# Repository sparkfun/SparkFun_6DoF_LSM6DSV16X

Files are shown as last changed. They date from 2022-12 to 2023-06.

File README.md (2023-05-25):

# SparkFun 6DoF - LSM6DSV16X (Qwiic)
========================================

<table class="table table-hover table-striped table-bordered">
    <tr>
        <th class="text-center"> 
        </th>
        <th class="text-center">
        </th>
    </tr>
    <tr align="center">
        <td></td>
        <td></td>
    </tr>
    <tr align="center">
        <td><a href="https://www.sparkfun.com/products/21325">SparkFun 6DoF - LSM6DSV16X (Qwiic)</a></td>
        <td><a href="https://www.sparkfun.com/products/21336">SparkFun Micro 6DoF - LSM6DSV16X (Qwiic)</a></td>
    </tr>
</table>

Looking for an extremely accurate way to detect motion utilizing AI? We've got you covered with the Qwiic-enabled, SparkFun LSM6DSV16X 6DoF IMU Breakout and the SparkFun Micro 6DoF - LSM6DSV16X (Qwiic). The LSM6DSV16X Breakout is a high-performance, low-power 6-axis IMU, featuring a 3-axis digital accelerometer, and a 3-axis digital gyroscope, with a triple core for processing acceleration and angular rate data on three separate channels (user interface, OIS, and EIS) with dedicated configuration, processing, and filtering. All this functionality comes in our standard 1in. x 1in. Qwiic form factor and will seamlessly integrate into your Qwiic-based projects. However, we still routed the I<sup>2</sup>C signals out to a set of 0.1in.-spaced pins for users who prefer a soldered connection.

The triple core of the LSM6DSV16X enables processes in edge computing, leveraging embedded advanced dedicated features such as a finite state machine (FSM) for configurable motion tracking and a machine learning core (MLC) for contextual awareness with exportable AI features for IoT applications. 

Additionally, Qvar (electric charge variation detection) is embedded in the LSM6DSV16X for user interface functions like tap, double tap, triple tap, long press, or L/R – R/L swipe.

Repository Contents
-------------------

* **/Documentation** - Data sheets, additional product information
* **/Hardware** - Eagle design files (.brd, .sch)

Documentation
--------------
* **[Library](https://github.com/sparkfun/SparkFun_LSM6DSV16X_Arduino_Library)** - Arduino library for the SparkFun 6DoF - LSM6DSV16X (Qwiic) and the SparkFun Micro 6DoF - LSM6DSV16X (Qwiic). 
* **[Hookup Guide](https://learn.sparkfun.com/tutorials/sparkfun-6dof-lsm6dsv16x-qwiic-hookup-guide)** - Basic hookup guide for the SparkFun 6DoF - LSM6DSV16X (Qwiic) and the SparkFun Micro 6DoF - LSM6DSV16X (Qwiic).

License Information
-------------------

This product is _**open source**_! 

Please review the LICENSE.md file for license information. 

If you have any questions or concerns on licensing, please contact technical support on our [SparkFun forums](https://forum.sparkfun.com/viewforum.php?f=152).

Distributed as-is; no warranty is given.

- Your friends at SparkFun.

_<COLLABORATION CREDIT>_

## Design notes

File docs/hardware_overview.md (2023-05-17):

###Accelerometer - LSM6DSV16X

The LSM6DSV16X Accelerometer from STMicroelectronics has a few different modes: 

* Mode 1: Periperhal only mode - I<sup>2</sup>C or SPI
* Mode 2: Sensor hub mode - I<sup>2</sup>C or SPI with controller I2C port
* Mode 3 and 4: AUX SPI mode I<sup>2</sup>C and SPI access multi-read

<div class="grid.cards.desc" markdown>

<table class="pdf" style="border-style:none;" markdown="1">
<tbody markdown="1">
<tr markdown="1">
<td align="center" width="35%" markdown="block">
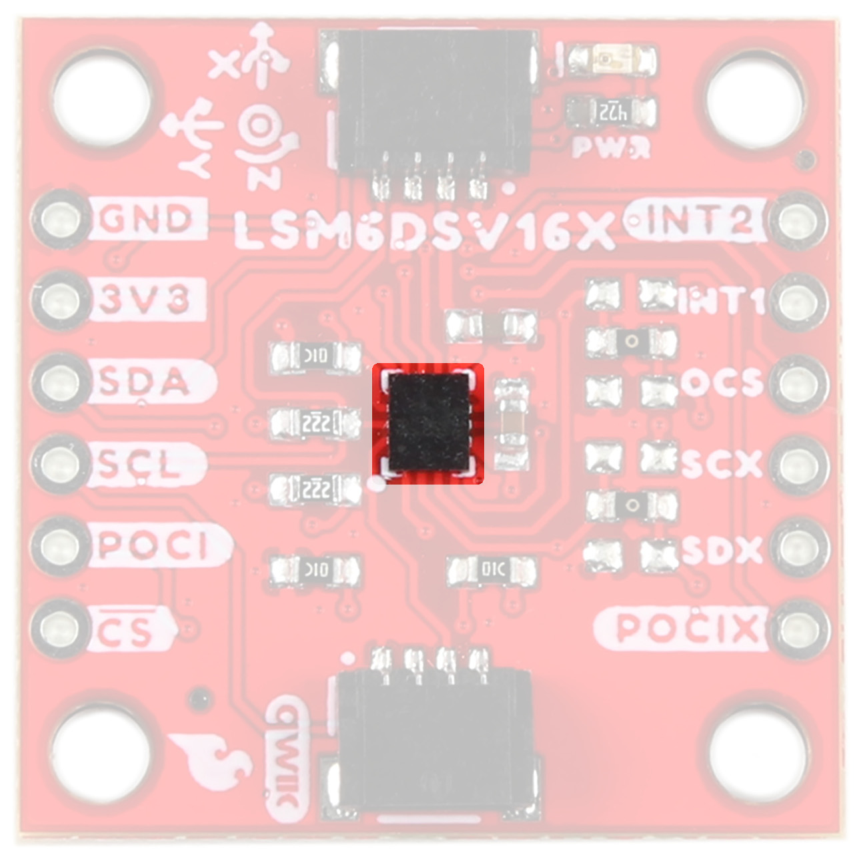
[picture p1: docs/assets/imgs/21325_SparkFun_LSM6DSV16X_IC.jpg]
SparkFun 6DoF - LSM6DSV16X (Qwiic)

</td>
<td align="center" width="35%" markdown="block">
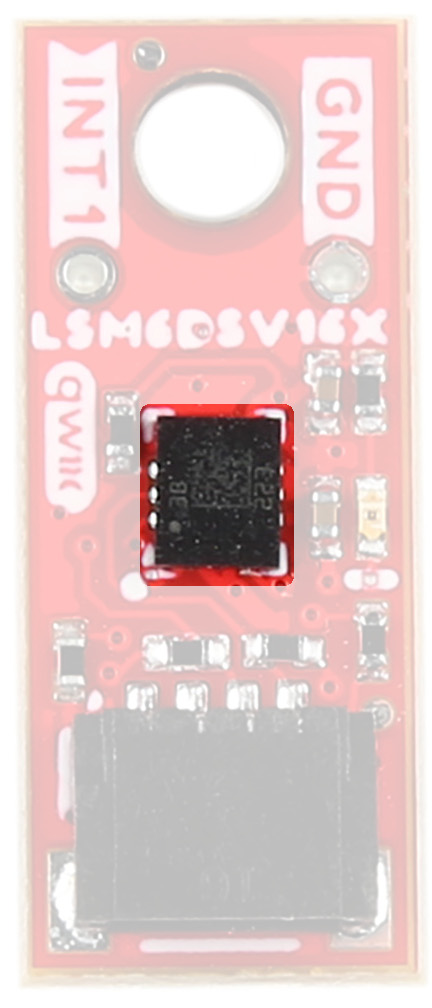
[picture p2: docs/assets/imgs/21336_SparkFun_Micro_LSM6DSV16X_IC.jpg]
SparkFun 6DoF Micro - LSM6DSV16X (Qwiic)

</td>
</tr>
</tbody>
</table>
</div class>

#### Mode 1
This is the default "peripheral only" mode. This mode allows you to use either I<sup>2</sup>C or SPI. By default, I<sup>2</sup>C is enabled with an address of 0x6B. By manipulating the associated jumper, you can change the I<sup>2</sup>C address to 0x6A (cut the power side and close the ground side) or switch to SPI mode (both jumpers open).

#### Mode 2
This mode enables a secondary I<sup>2</sup>C port that the 6DoF controls; up to 4 external sensors can be connected to the I<sup>2</sup>C controller interface of the device. External sensors communicate via the SCX and SDX (PICOX) lines - the SCX and SDX jumpers will need to be opened.

#### Modes 3 & 4
In addition to the primary I<sup>2</sup>C peripheral interface or SPI (3- / 4-wire) serial interface, an auxiliary SPI (3- / 4-wire) serial interface is available for external device connections (i.e. camera module). Mode 3 is available for gyroscope only, Mode 4 is available for both gyroscope and accelerometer.

The analog hub and Qvar functionalities are available in mode 1 with I²C interface only.

###Qwiic Connector

The Qwiic connector(s) on the SparkFun 6DoF - LSM6DSV16X (Qwiic) and SparkFun 6DoF Micro - LSM6DSV16X (Qwiic) provide power and I<sup>2</sup>C connectivity simultaneously.

<div class="grid.cards.desc" markdown>

<table class="pdf" style="border-style:none;" markdown="1">
<tbody markdown="1">
<tr markdown="1">
<td align="center" width="35%" markdown="block">
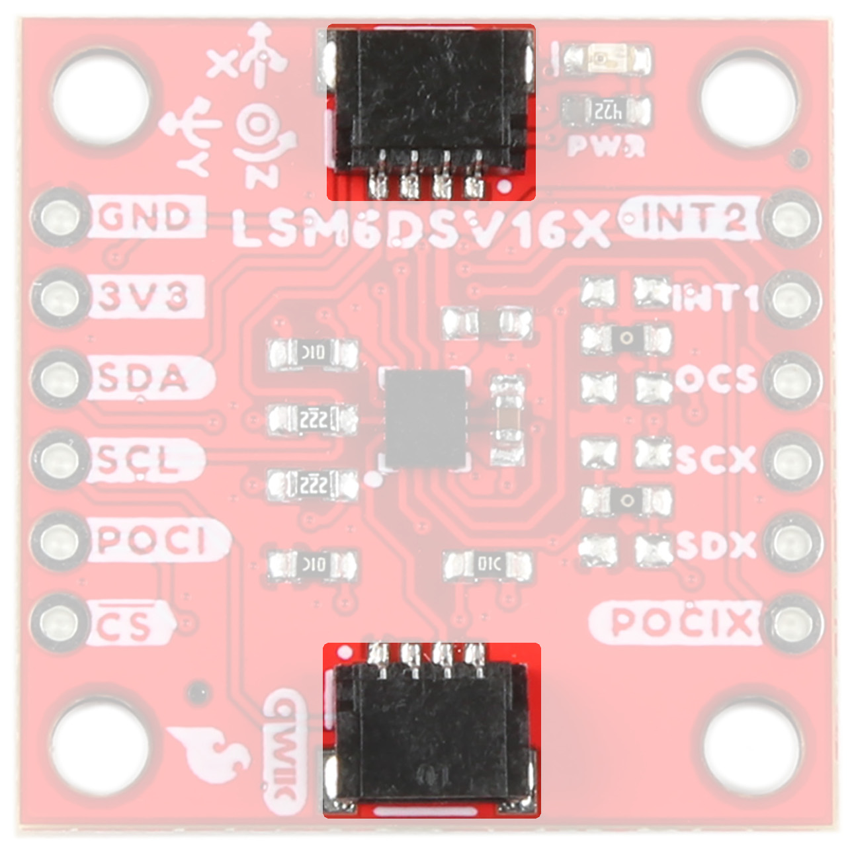
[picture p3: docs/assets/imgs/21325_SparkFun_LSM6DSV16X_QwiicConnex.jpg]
SparkFun 6DoF - LSM6DSV16X (Qwiic)

</td>
<td align="center" width="35%" markdown="block">
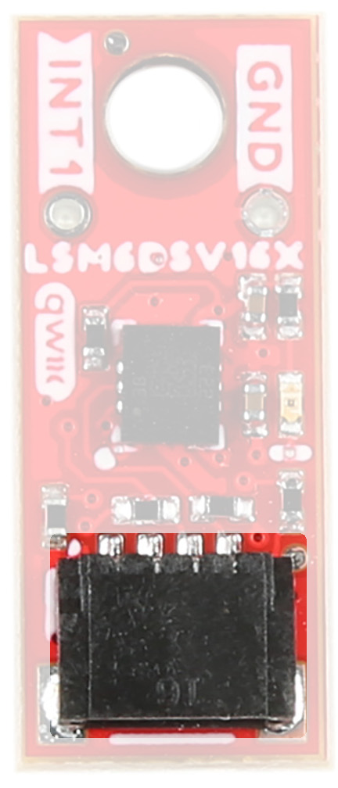
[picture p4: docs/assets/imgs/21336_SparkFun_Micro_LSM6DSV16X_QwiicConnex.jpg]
SparkFun 6DoF Micro - LSM6DSV16X (Qwiic)

</td>
</tr>
</tbody>
</table>
</div class>

###Power

Ideally, power to these boards will be provided by the Qwiic cables. However, should you wish to provide power separately, the 1" x 1" board has its pins broken out to PTH and you can wire up power via these. 

!!! warning
    <p>Make sure to pay attention to logic levels - supply voltage range should be between 1.71V - 3.6V. </p>

<figure markdown>
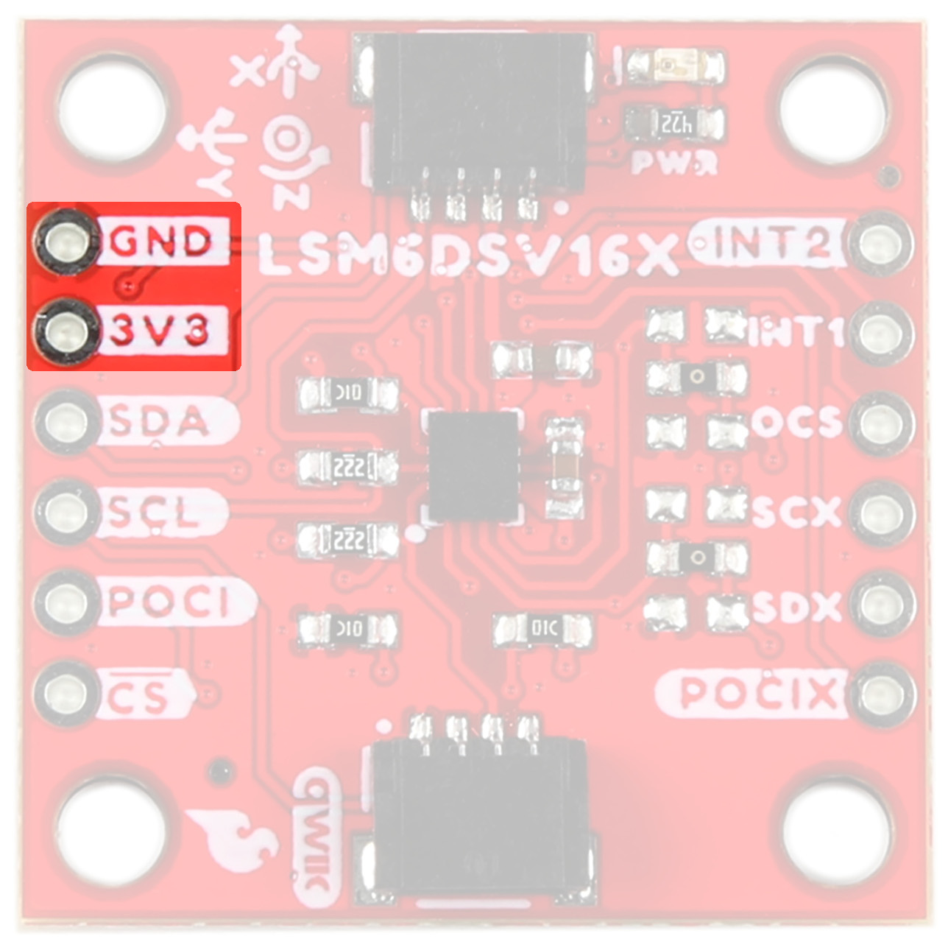
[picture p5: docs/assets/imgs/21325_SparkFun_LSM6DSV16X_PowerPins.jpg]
LSM6DSV16X Power Pins

<figcaption markdown>LSM6DSV16X Power Pins</figcaption>
</figure>

###GPIO

This is a quick overview of the pin functionality. For more information, refer to the [datasheet](assets/BoardFiles/lsm6dsv16x.pdf). 

#### I<sup>2</sup>C

If you do not want to use the Qwiic connectors, I<sup>2</sup>C functionality has been broken out to PTH pins on the 1x1" board. 

<figure markdown>
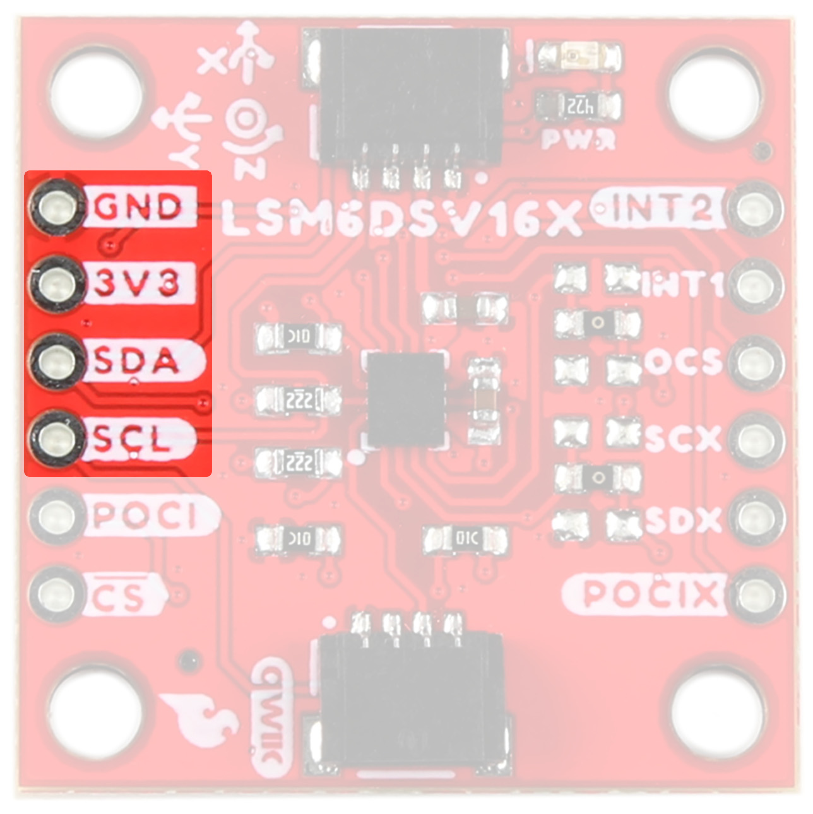
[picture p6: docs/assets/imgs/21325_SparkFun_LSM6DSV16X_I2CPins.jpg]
LSM6DSV16X I2C Pins

<figcaption markdown>LSM6DSV16X I2C Pins</figcaption>
</figure>

#### SPI

Primary SPI functionality has been broken out to the highlighted pins below. 

<figure markdown>
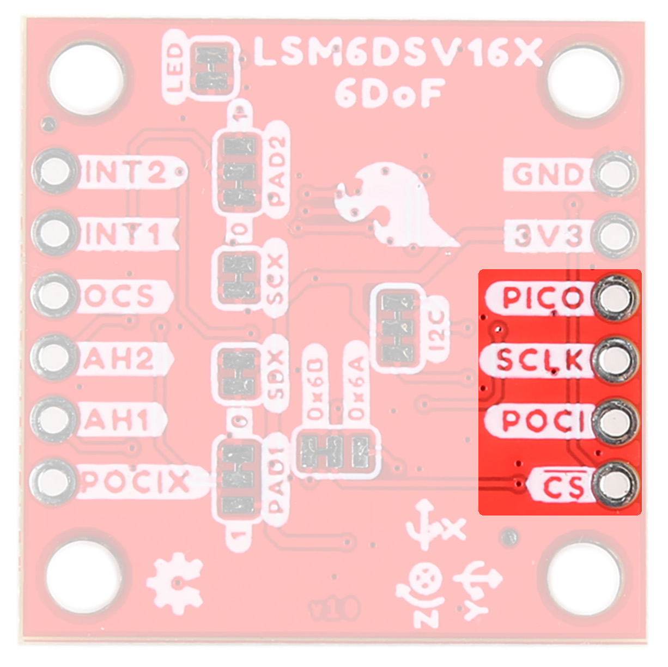
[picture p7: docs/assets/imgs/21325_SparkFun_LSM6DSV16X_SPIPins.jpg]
LSM6DSV16X SPI Pins

<figcaption markdown>LSM6DSV16X SPI Pins</figcaption>
</figure>

Auxiliary SPI is available via AH1, AH2, and OCS. 

<figure markdown>
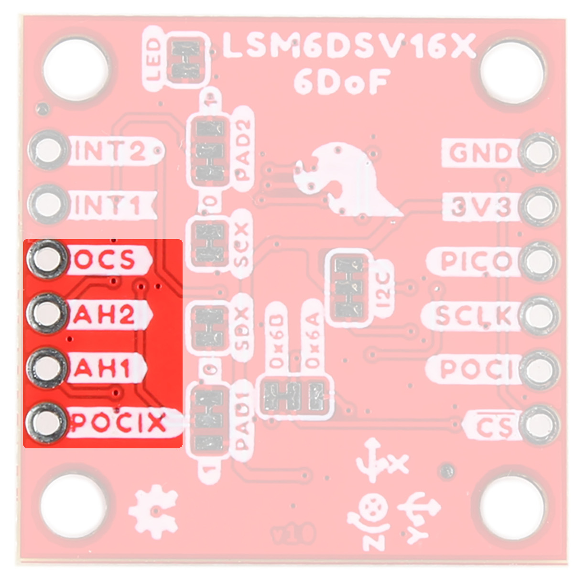
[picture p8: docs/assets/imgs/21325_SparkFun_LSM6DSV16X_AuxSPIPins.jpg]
LSM6DSV16X Aux SPI Pins

<figcaption markdown>LSM6DSV16X Aux SPI Pins</figcaption>
</figure>

#### AH1/AH2

The LSM6DSV16X embeds Qvar functionality, which is an electrostatic sensor able to measure the variation of the quasi-electrostatic potential. The Qvar sensing channel can be used for user interface applications like tap, double tap, triple tap, long press, and L/R – R/L swipe. Functionality is accessed via the AH1 and AH2 pins. For more information, refer to STMicroelectronics' [Qvar Sensing Channel Application Notes](https://www.st.com/resource/en/application_note/an5755-qvar-sensing-channel--stmicroelectronics.pdf). 

<figure markdown>
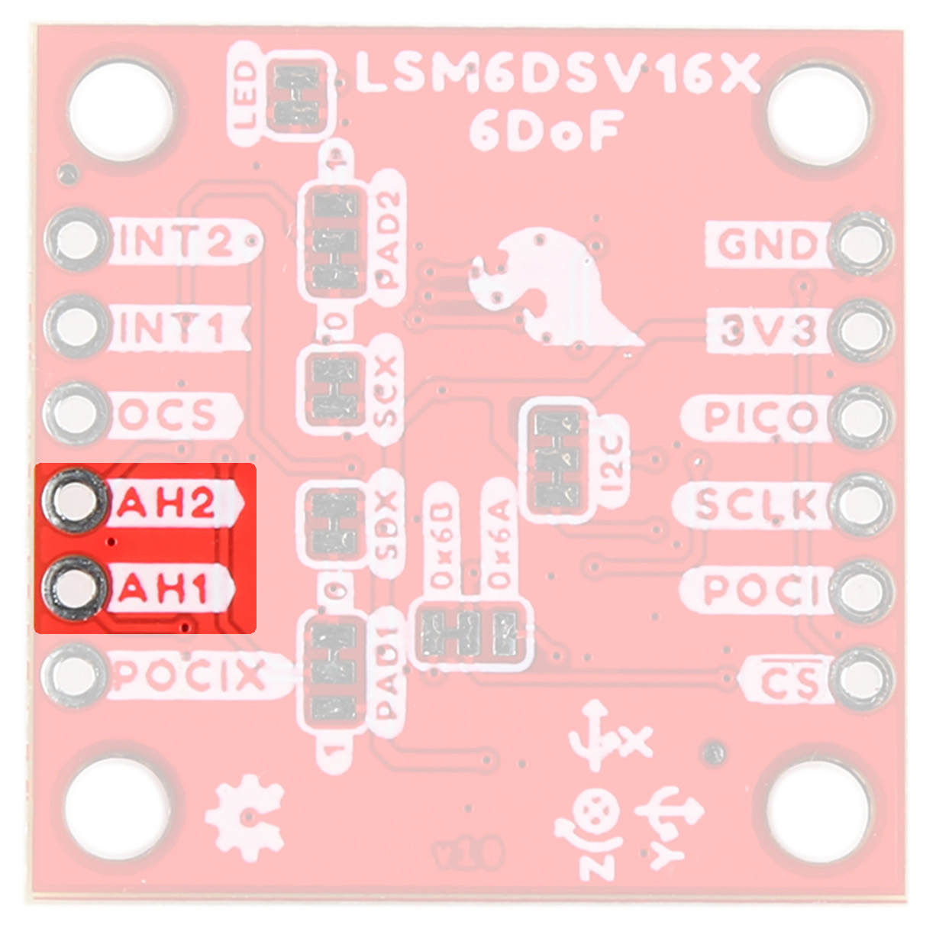
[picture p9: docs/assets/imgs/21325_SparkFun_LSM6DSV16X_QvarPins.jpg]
LSM6DSV16X Aux SPI Pins

<figcaption markdown>LSM6DSV16X Qvar Pins</figcaption>
</figure>

#### Interrupt Pins

Interrupt functionality is available via the INT pins. There are two interrupts available on the 1x1" board, and 1 interrupt available on the Micro. These pins are configurable to be high or low. 

<div class="grid.cards.desc" markdown>

<table class="pdf" style="border-style:none;" markdown="1">
<tbody markdown="1">
<tr markdown="1">
<td align="center" width="35%" markdown="block">
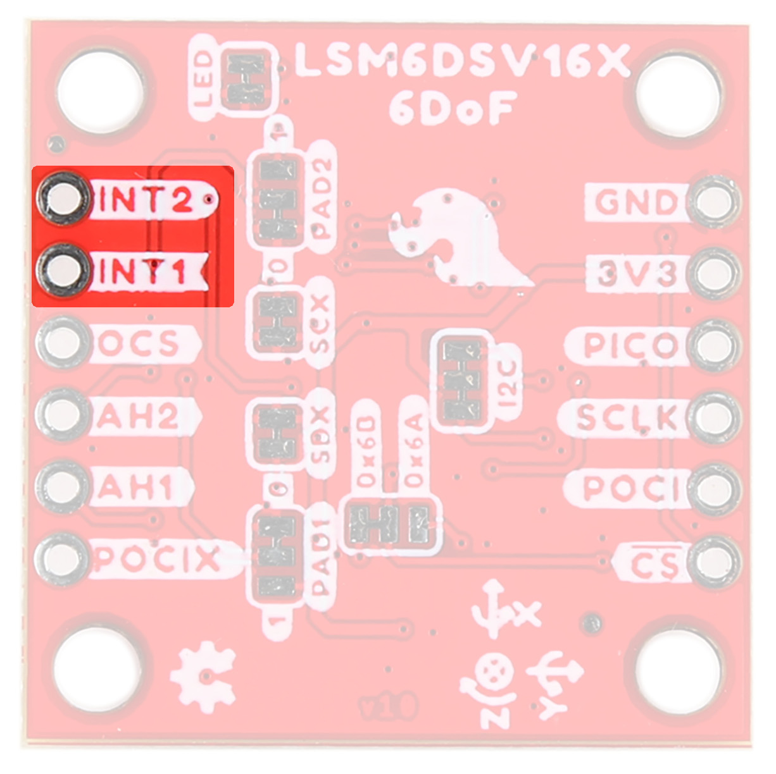
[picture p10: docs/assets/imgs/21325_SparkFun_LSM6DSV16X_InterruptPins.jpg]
LSM6DSV16X Interrupt Pins

</td>
<td align="center" width="35%" markdown="block">
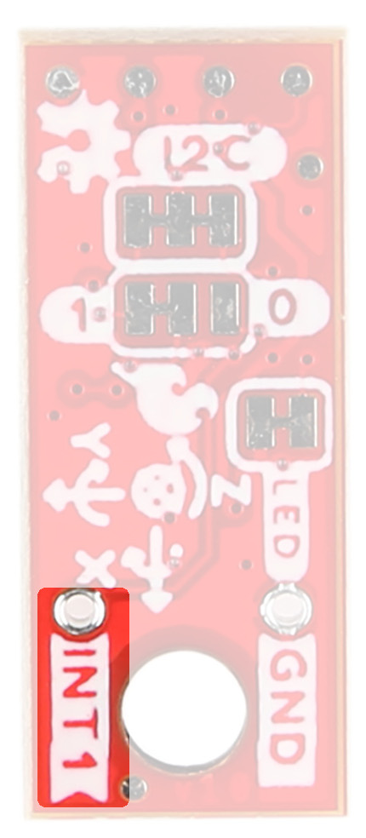
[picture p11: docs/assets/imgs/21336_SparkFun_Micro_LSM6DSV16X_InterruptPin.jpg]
LSM6DSV16X Micro Interrupt Pin

</td>
</tr>
</tbody>
</table>
</div class>

###Jumpers 

####I2C

Like our other Qwiic boards, the Qwiic 6DoF - LSM6DSV16X boards come equipped with pull-up resistors on the clock and data pins. If you are daisy-chaining multiple Qwiic devices, you will want to cut this jumper; if multiple sensors are connected to the bus with the pull-up resistors enabled, the parallel equivalent resistance will create too strong of a pull-up for the bus to operate correctly. As a general rule of thumb, disable all but one pair of pull-up resistors if multiple devices are connected to the bus. To disable the pull up resistors, use an X-acto knife to cut the joint between the two jumper pads highlighted below.

<div class="grid.cards.desc" markdown>

<table class="pdf" style="border-style:none;" markdown="1">
<tbody markdown="1">
<tr markdown="1">
<td align="center" width="35%" markdown="block">
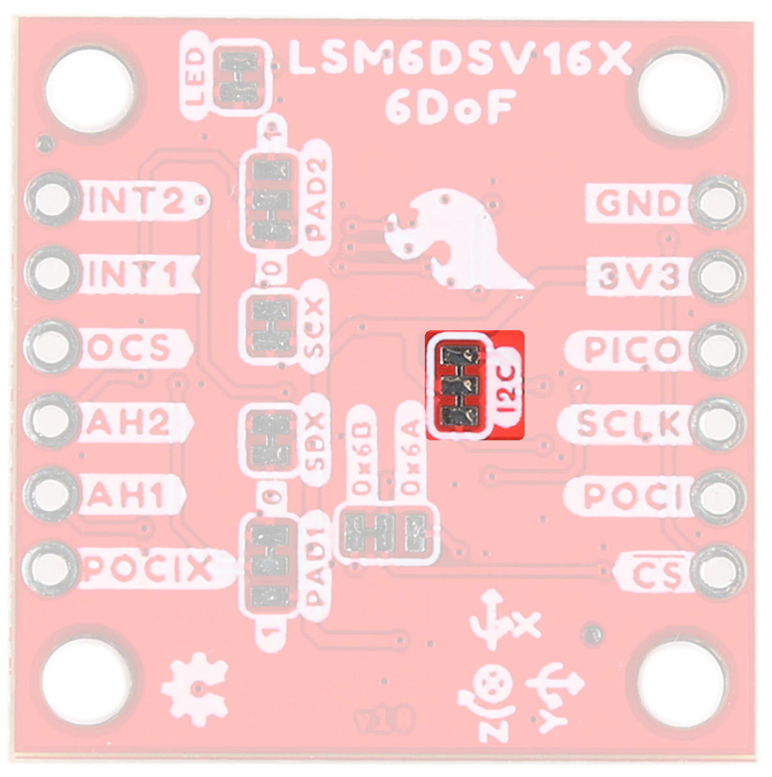
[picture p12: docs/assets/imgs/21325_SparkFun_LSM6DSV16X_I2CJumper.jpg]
SparkFun 6DoF - LSM6DSV16X (Qwiic)

</td>
<td align="center" width="35%" markdown="block">
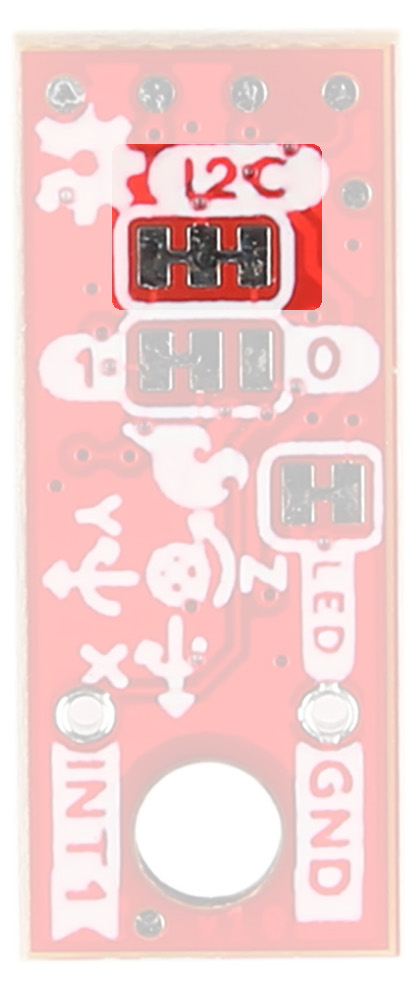
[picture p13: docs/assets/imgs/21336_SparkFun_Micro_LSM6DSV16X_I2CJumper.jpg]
SparkFun 6DoF Micro - LSM6DSV16X (Qwiic)

</td>
</tr>
</tbody>
</table>
</div class>

####I<sup>2</sup>C Address

The SparkFun 6DoF - LSM6DSV16X (Qwiic) boards have a default I<sup>2</sup>C address of 0x6B, but by cutting the address jumper on the back of the board, you can select 0x6A (GND) or SPI (fully open). 

<div class="grid.cards.desc" markdown>

<table class="pdf" style="border-style:none;" markdown="1">
<tbody markdown="1">
<tr markdown="1">
<td align="center" width="35%" markdown="block">
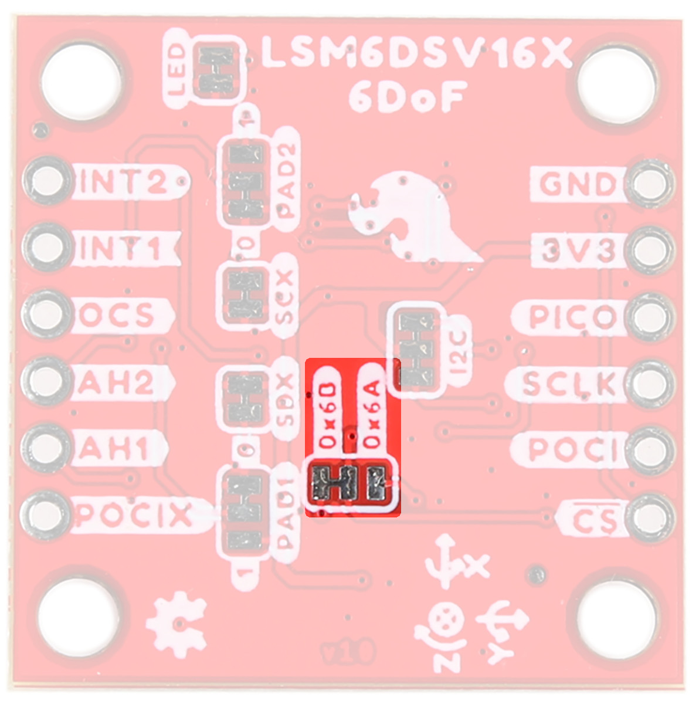
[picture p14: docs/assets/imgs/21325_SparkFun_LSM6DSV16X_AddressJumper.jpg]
LSM6DSV16X Address Jumpers

</td>
<td align="center" width="35%" markdown="block">
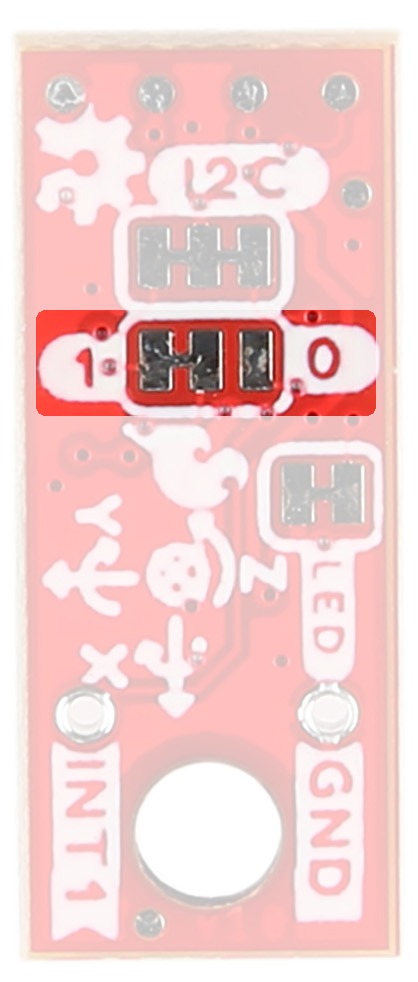
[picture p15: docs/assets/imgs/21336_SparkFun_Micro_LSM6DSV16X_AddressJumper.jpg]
LSM6DSV16X Micro Address Jumpers

</td>
</tr>
</tbody>
</table>
</div class>

####SDX/SCX

If using either Mode 2 (sensor hub mode) or the analog capabilities of the sensor, cut both of these traces. 

<figure markdown>
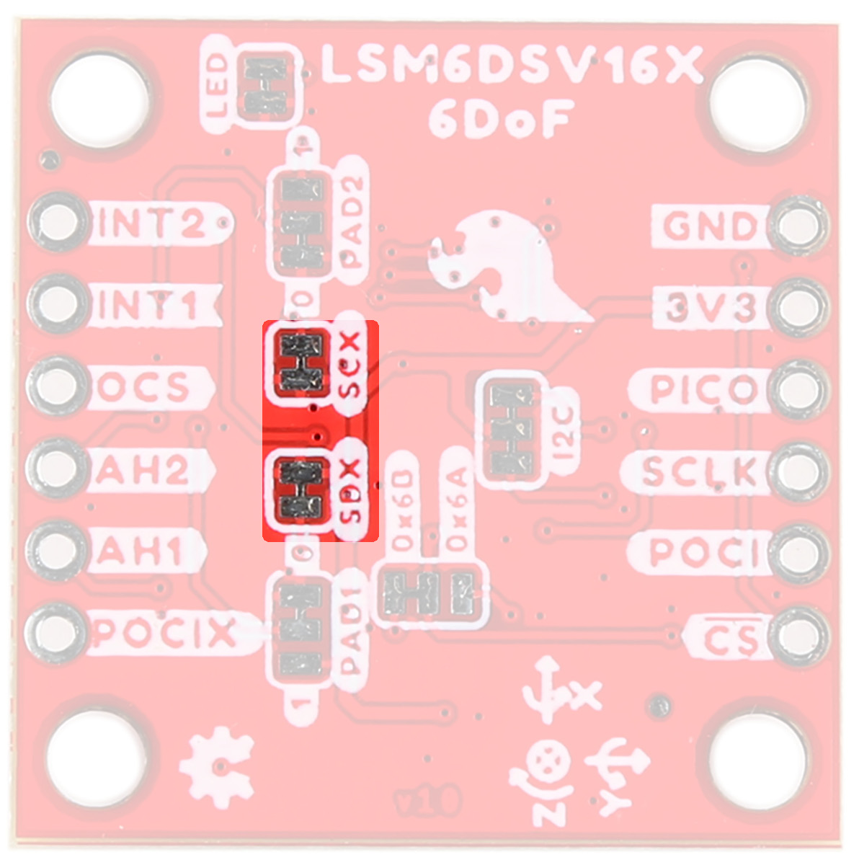
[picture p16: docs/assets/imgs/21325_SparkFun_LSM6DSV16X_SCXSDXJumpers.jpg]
LSM6DSV16X SCX/SDX Jumpers

<figcaption markdown>LSM6DSV16X SCX/SDX Jumpers</figcaption>
</figure>

####Pad Jumpers

When using the Analog In (QVar) functionality, you can select whether P1 is tied to GND or 3v3 using the PAD1 jumper. Similarly, you can select whether P2 is tied to GND or 3v3 using the PAD2 jumper. Refer to either the [application notes](https://www.st.com/en/mems-and-sensors/lsm6dsv16x.html#documentation) for more information. 

<figure markdown>
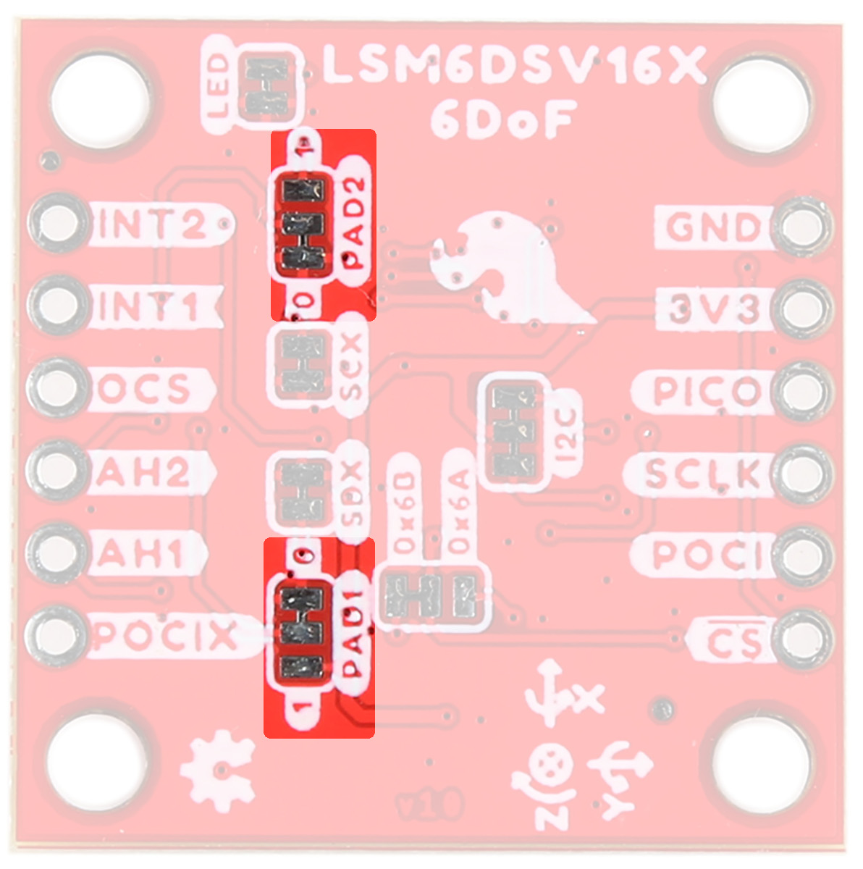
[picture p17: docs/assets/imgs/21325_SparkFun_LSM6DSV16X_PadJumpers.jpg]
LSM6DSV16X Pad Jumpers

<figcaption markdown>LSM6DSV16X Pad Jumpers</figcaption>
</figure>

####LED

Let there be light! Or not. An LED on the front of each board indicates power is being provided to the board. If you don't like LEDs or you are concerned about current draw, cut the jumper highlighted below. 

<div class="grid.cards.desc" markdown>

<table class="pdf" style="border-style:none;" markdown="1">
<tbody markdown="1">
<tr markdown="1">
<td align="center" width="35%" markdown="block">
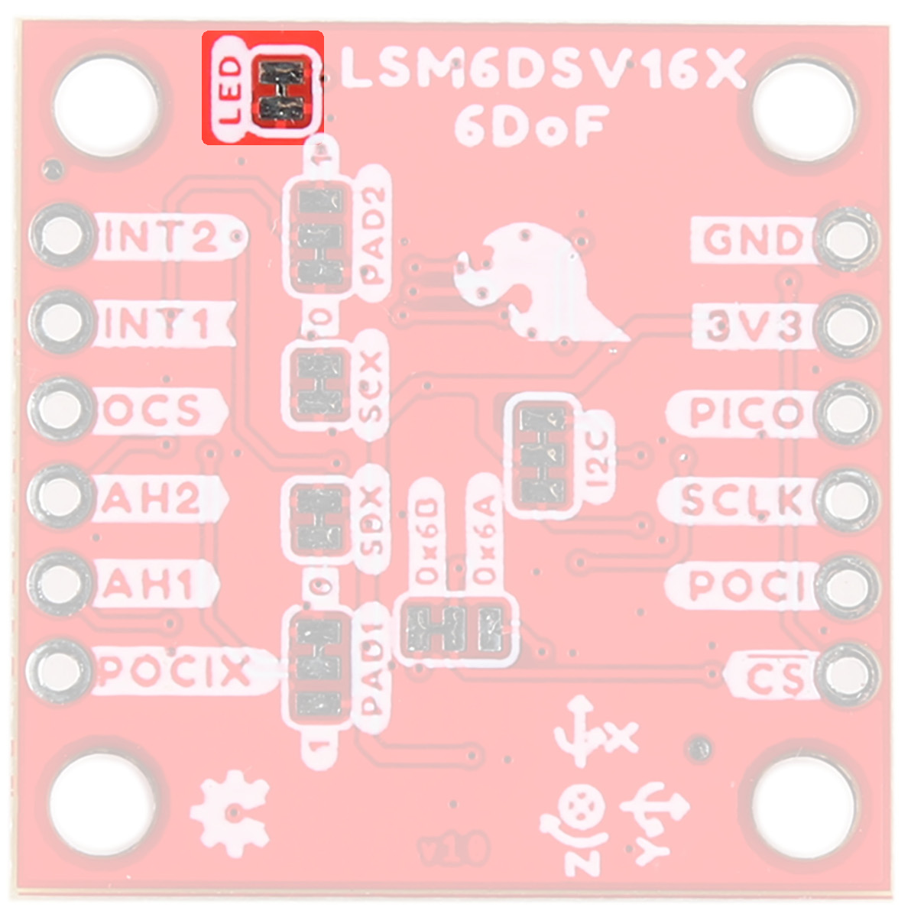
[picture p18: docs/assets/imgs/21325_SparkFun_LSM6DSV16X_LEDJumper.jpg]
SparkFun 6DoF - LSM6DSV16X (Qwiic)

</td>
<td align="center" width="35%" markdown="block">
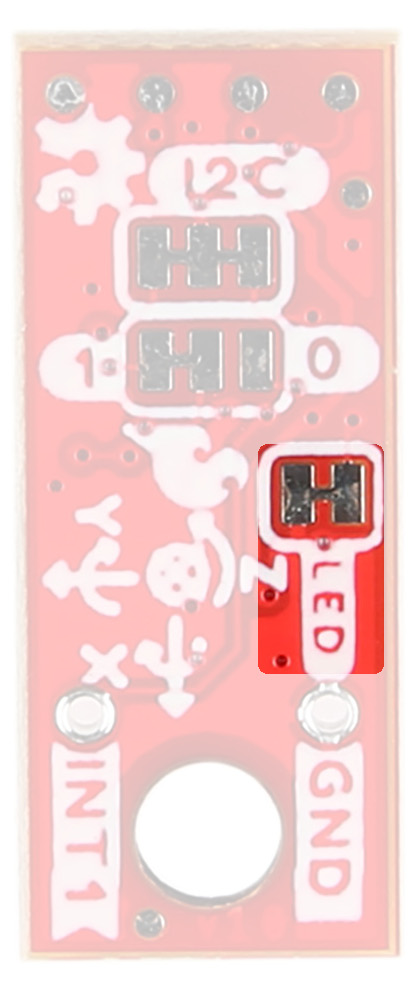
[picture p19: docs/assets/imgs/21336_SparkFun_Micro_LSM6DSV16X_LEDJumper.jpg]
SparkFun 6DoF Micro - LSM6DSV16X (Qwiic)

</td>
</tr>
</tbody>
</table>
</div class>

###Board Outline

The SparkFun 6DoF - LSM6DSV16X (Qwiic) follows the standard 1" x 1" convention of most of our Qwiic breakout boards. 

<figure markdown>
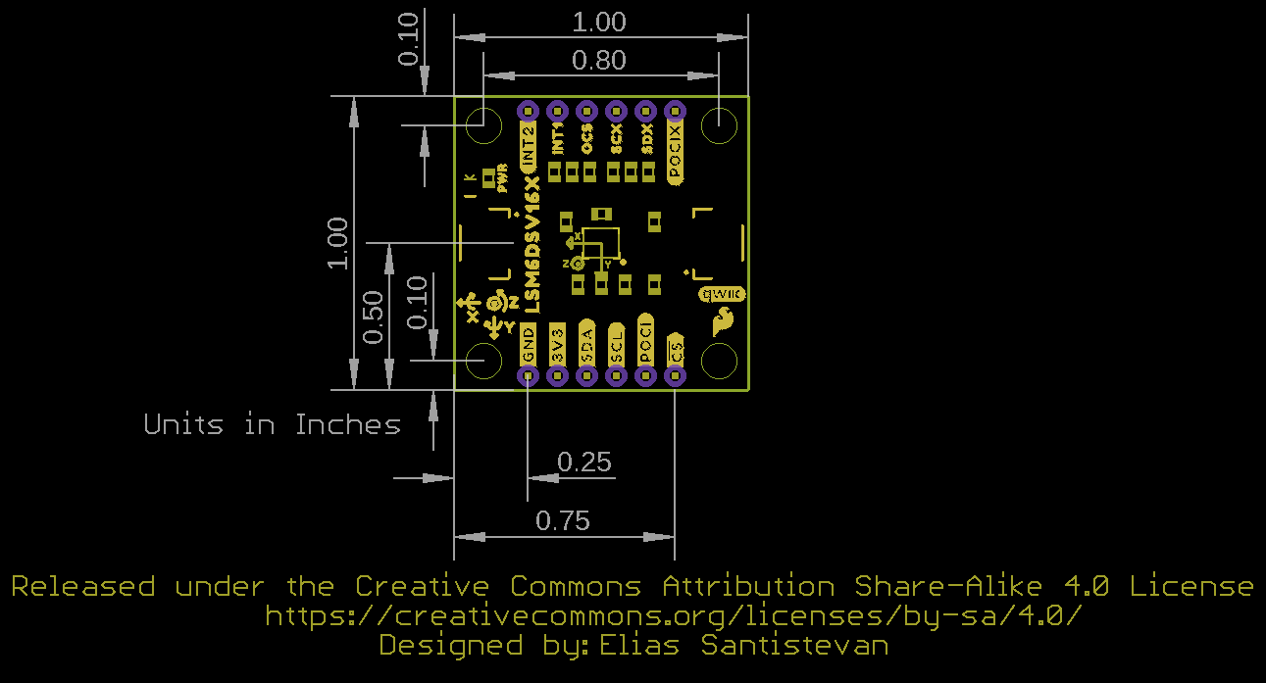
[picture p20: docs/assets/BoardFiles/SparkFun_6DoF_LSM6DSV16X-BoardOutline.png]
SparkFun 6DoF - LSM6DSV16X (Qwiic) Board Outline

<figcaption markdown>SparkFun 6DoF - LSM6DSV16X (Qwiic)</figcaption>
</figure>

The SparkFun 6DoF Micro - LSM6DSV16X (Qwiic) measures 0.3" x 0.75". 

<figure markdown>
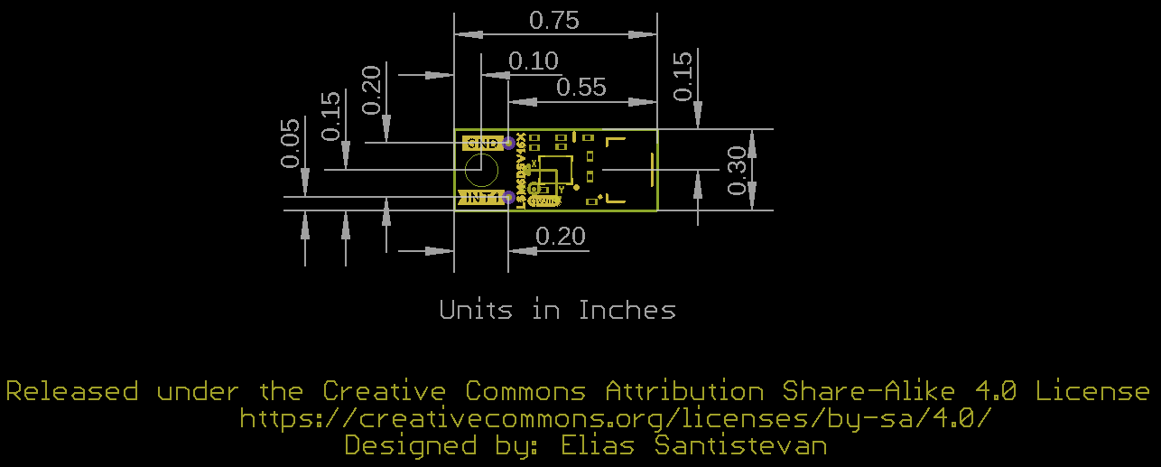
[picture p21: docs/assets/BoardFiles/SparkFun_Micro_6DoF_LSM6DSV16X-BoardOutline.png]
SparkFun 6DoF - LSM6DSV16X (Qwiic) Board Outline

<figcaption markdown>SparkFun 6DoF Micro - LSM6DSV16X (Qwiic)</figcaption>
</figure>

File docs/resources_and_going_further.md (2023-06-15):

For more information, check out the resources below.

SparkFun 6DoF LSM6DSV16X 1"x1" Board: 

* [Schematic (PDF)](assets/BoardFiles/SparkFun_6DoF_LSM6DSV16X-Schematic.pdf){:target="_blank"}
* [Eagle Files](assets/BoardFiles/SparkFun_6DoF_LSM6DSV16X-EagleFiles.zip)
* [Board Outline (PNG)](assets/BoardFiles/SparkFun_6DoF_LSM6DSV16X-BoardOutline.png){:target="_blank"}
* [GitHub Hardware Repo](https://github.com/sparkfun/SparkFun_6DoF_LSM6DSV16X){:target="_blank"}
* [GitHub Arduino Library Repo](https://github.com/sparkfun/SparkFun_LSM6DSV16X_Arduino_Library)

SparkFun 6DoF LSM6DSV16X Micro Board: 

* [Schematic (PDF)](assets/BoardFiles/SparkFun_Micro_6DoF_LSM6DSV16X-Schematic.pdf){:target="_blank"}
* [Eagle Files](assets/BoardFiles/SparkFun_Micro_6DoF_LSM6DSV16X-EagleFiles.zip)
* [Board Outline (PNG)](assets/BoardFiles/SparkFun_Micro_6DoF_LSM6DSV16X-BoardOutline.png){:target="_blank"}
* [GitHub Hardware Repo](https://github.com/sparkfun/SparkFun_6DoF_LSM6DSV16X){:target="_blank"}
* [GitHub Arduino Library Repo](https://github.com/sparkfun/SparkFun_LSM6DSV16X_Arduino_Library)

Or check out other [Qwiic Sensor Tutorials](https://learn.sparkfun.com/tutorials/tags/qwiic):

<table style="border-style:none">
    <tr>
        <td style="vertical-align: text-top;" width="264px">
            <a href="https://learn.sparkfun.com/tutorials/sparkfun-humidity-sensor-breakout---shtc3-qwiic-hookup-guide">
            
            <h3 style="vertical-align: left">SparkFun Humidity Sensor Breakout - SHTC3 (Qwiic) Hookup Guide
            </h3></a>
        </td>
        <td style="vertical-align: text-top;" width="264px">
            <div style="text-align: center"><a href="https://learn.sparkfun.com/tutorials/qwiic-atmospheric-sensor-bme280-hookup-guide">
            </div>
            <h3 style="text-align: left">Qwiic Atmospheric Sensor (BME280) Hookup Guide
            </h3></a>
        </td>
        <td style="vertical-align: text-top;" width="264px">
            <div style="text-align: center"><a href="https://learn.sparkfun.com/tutorials/qwiic-tmp117-high-precision-digital-temperature-sensor-hookup-guide">
            </div>
            <h3 style="text-align: left">Qwiic TMP117 High Precision Digital Temperature Sensor Hookup Guide
            </h3></a>
        </td>
        <td style="vertical-align: text-top;" width="264px">
            <a href="https://learn.sparkfun.com/tutorials/qwiic-pressure-sensor-bmp384-hookup-guide">
            
            <h3 style="text-align: left">Qwiic Pressure Sensor (BMP384) Hookup Guide
            </h3></a>
        </td>
    </tr>
</table>

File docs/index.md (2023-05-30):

<link rel="stylesheet" href="https://cdnjs.cloudflare.com/ajax/libs/font-awesome/4.7.0/css/font-awesome.min.css">

<div class="grid.cards.desc" markdown>

<table class="pdf" style="border-style:none;" markdown="1">
<tbody markdown="1">
<tr markdown="1">
<td align="center" width="35%" markdown="block">
SparkFun 6DoF - LSM6DSV16X (Qwiic) (https://www.sparkfun.com/products/21325)

The [SparkFun 6DoF - LSM6DSV16X (Qwiic)](https://www.sparkfun.com/products/21325) is a Qwiic enabled board based on the LSM6DSV16X from STMicroelectronics. This little chip is a high-performance, low-power 6-axis IMU, featuring a 3-axis digital accelerometer and a 3-axis digital gyroscope, with a triple core for processing acceleration and angular rate data on three separate channels (user interface, OIS, and EIS) with dedicated configuration, processing, and filtering. 

<center>
[Purchase from SparkFun :fontawesome-solid-cart-plus:](https://www.sparkfun.com/products/21325){ .md-button .md-button--primary }
</center>
</td>
<td align="center" width="35%" markdown="block">
SparkFun Micro 6DoF - LSM6DSV16X (Qwiic) (https://www.sparkfun.com/products/21336)

The [SparkFun 6DoF Micro- LSM6DSV16X (Qwiic)](https://www.sparkfun.com/products/21336) is the 1x1's mini-me, containing most of it's elder sibling's functionality in a tiny little package. 

<center>
[Purchase from SparkFun :fontawesome-solid-cart-plus:](https://www.sparkfun.com/products/21336){ .md-button .md-button--primary }
</center>
</td>
</tr>
</tbody>
</table>
</div class>

<div style="text-align: center;">
<iframe width="560" height="315" src="https://www.youtube.com/embed/iTeRRxXpNMM" title="YouTube video player" frameborder="0" allow="accelerometer; autoplay; clipboard-write; encrypted-media; gyroscope; picture-in-picture; web-share" allowfullscreen></iframe></div>

### Required Materials

To follow along with this tutorial, you will need the following materials. You may not need everything though depending on what you have. Add it to your cart, read through the guide, and adjust the cart as necessary.

<section class="cards">

<!--   card 1 -->
  <article class="card">
	<div class="card-header">
		<a href="https://www.sparkfun.com/products/21325"><center><b>SparkFun 6DoF - LSM6DSV16X (Qwiic)</b><br />SEN-21325</center></a>
	</div>    
    <div class="card-content">
		<a href="https://www.sparkfun.com/products/21325">
			SparkFun 6DoF - LSM6DSV16X (Qwiic)
		</a>
	<!-- 
		<div class="card-footer">
			<button class="button1"><a href="https://www.sparkfun.com/products/21772" style="color: #ffffff">Purchase From SparkFun <i class="fa fa-cart-plus"></i></a></button>
		</div> -->
   </div><!-- .card-content -->
  </article>

<!--   card 2 -->
  <article class="card">
	<div class="card-header">
		<a href="https://www.sparkfun.com/products/21336"><center><b>SparkFun 6DoF Micro- LSM6DSV16X (Qwiic)</b><br /> SEN-21336</center></a>
	</div>    
    <div class="card-content">
		<a href="https://www.sparkfun.com/products/21336">
			SparkFun 6DoF Micro- LSM6DSV16X (Qwiic)
		</a>
   </div><!-- .card-content -->
  </article>

<!--   card 3 -->
  <article class="card">
	<div class="card-header">
		<a href="https://www.sparkfun.com/products/15123"><center><b>SparkFun RedBoard Qwiic</b><br /> DEV-14743</center></a>
	</div>    
    <div class="card-content">
		<a href="https://www.sparkfun.com/products/15123">
			SparkFun RedBoard Qwiic
		</a>
   </div><!-- .card-content -->
  </article>

<!--   card 4 -->
  <article class="card">
	<div class="card-header">
		<a href="https://www.sparkfun.com/products/14427"><center><b>Qwiic Cable - 100mm</b><br /> PRT-14427</center></a>
	</div>    
    <div class="card-content">
		<a href="https://www.sparkfun.com/products/14427">
			Qwiic Cable - 100mm
		</a>
   </div><!-- .card-content -->
  </article>

<!--   card 5 -->
  <article class="card">
	<div class="card-header">
		<a href="https://www.sparkfun.com/products/14743"><center><b>USB 3.1 Cable A to C - 3 Foot</b><br /> CAB-14743</center></a>
	</div>    
    <div class="card-content">
		<a href="https://www.sparkfun.com/products/14743">
			USB 3.1 Cable A to C - 3 Foot
		</a>
   </div><!-- .card-content -->
  </article>

  </section>

### Suggested Reading

If you aren’t familiar with the following concepts, we recommend checking out these tutorials before continuing.

<section class="cards">

<!--   card 1 -->
  <article class="card">
    <picture class="thumbnail">
         
    </picture>
    <div class="card-content">
      <a href="https://www.sparkfun.com/qwiic">Qwiic Connect System</a>
   </div><!-- .card-content -->
  </article>

<!--   card 2 -->
  <article class="card">
    <picture class="thumbnail">
         
    </picture>
    <div class="card-content">
      <a href="https://learn.sparkfun.com/tutorials/accelerometer-basics">Accelerometer Basics</a>
   </div><!-- .card-content -->
  </article>

<!--   card 3 -->
  <article class="card">
    <picture class="thumbnail">
         
    </picture>
    <div class="card-content">
      <a href="https://learn.sparkfun.com/tutorials/i2c">I2C</a>
   </div><!-- .card-content -->
  </article>
</section>

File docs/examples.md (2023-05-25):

###Example 1: Basic Readings

This first example just does some basic measurements. To find Example 1, go to **File** > **Examples** > **SparkFun 6DoF LSM6DSV16X** > **example1_basic**:

<figure markdown>
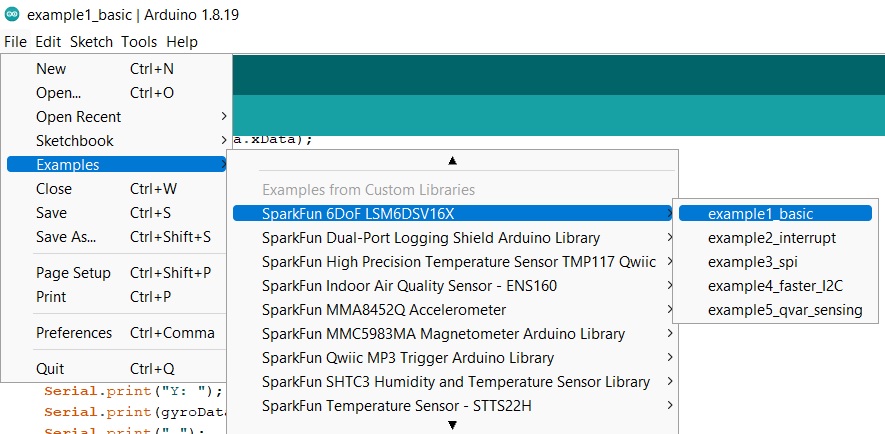
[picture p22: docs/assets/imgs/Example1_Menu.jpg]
LSM6DSV16X Arduino Example 1

<figcaption markdown>Finding Example 1</figcaption>
</figure>

Alternatively, you can expand the link below and copy and paste the code into a shiny new Arduino sketch: 

??? "Example 1 Arduino Code"
	```
	--8<-- "https://raw.githubusercontent.com/sparkfun/SparkFun_LSM6DSV16X_Arduino_Library/main/examples/example1_basic/example1_basic.ino"
	```

Make sure you've selected the correct board and port in the Tools menu and then hit the upload button. Once the code has finished uploading, go ahead and open a [Serial Monitor](https://learn.sparkfun.com/tutorials/terminal-basics). You should see something similar to the following. Note the obvious changes where the sensor was turned upright. 

<figure markdown>
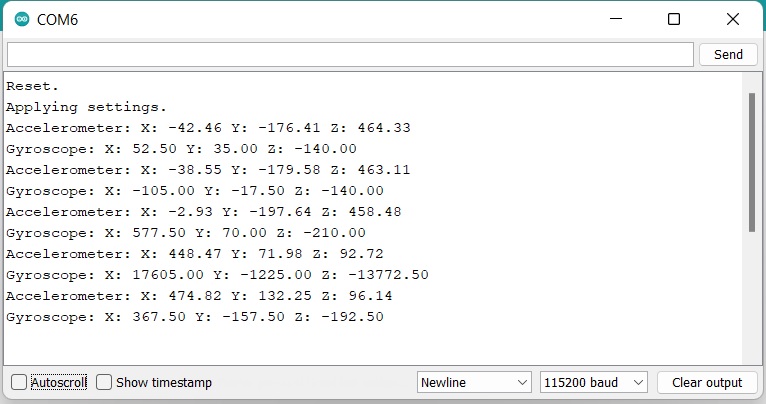
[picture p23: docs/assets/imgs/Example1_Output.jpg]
LSM6DSV16X Arduino Example 1 Output

<figcaption markdown>Example 1 Output</figcaption>
</figure>

###Example 2: Interrupt

This example shows the basic settings and functions for retrieving accelerometer data. In addition we're setting the data ready signal to interrupt pin one in an active high configuration and show additional ways in which the interrupts can be configured. To find Example 2, go to **File** > **Examples** > **SparkFun 6DoF LSM6DSV16X** > **example2_interrupt**. 

<figure markdown>
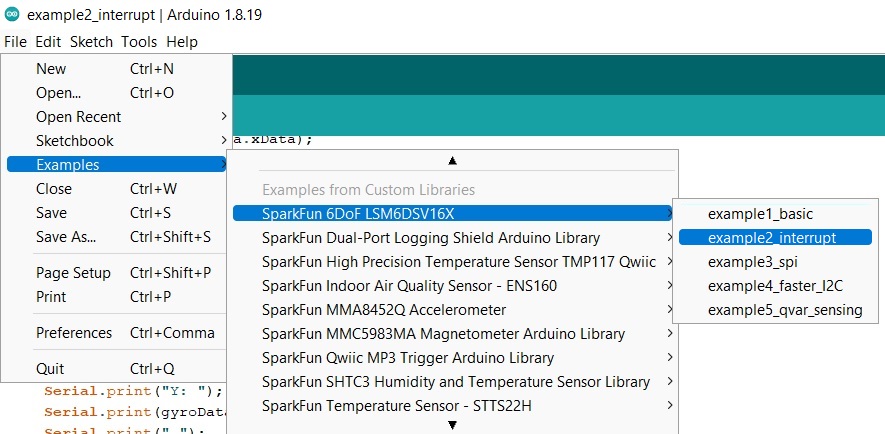
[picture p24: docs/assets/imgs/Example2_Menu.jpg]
LSM6DSV16X Arduino Example 2

<figcaption markdown>Finding Example 2</figcaption>
</figure>

Alternatively, you can expand the link below and copy and paste the code into a shiny new Arduino sketch: 

??? "Example 2 Arduino Code"
	```
	--8<-- "https://raw.githubusercontent.com/sparkfun/SparkFun_LSM6DSV16X_Arduino_Library/main/examples/example2_interrupt/example2_interrupt.ino"
	```

Your setup should resemble something like this: 

<figure markdown>
LSM6DSV16X Arduino Example 2
<figcaption markdown>Example 2</figcaption>
</figure>

Make sure your code matches the pin you've selected as the interrupt pin. Here Pin 2 is wired as the interrupt pin on the RedBoard, so the code was modified to reflect that. Again, make sure you've selected the correct board and port in the Tools menu and then hit the upload button. Once the code has finished uploading, go ahead and open a [Serial Monitor](https://learn.sparkfun.com/tutorials/terminal-basics). You should see something similar to the following.

<figure markdown>
LSM6DSV16X Arduino Example 2 Output
<figcaption markdown>Example 2 Output</figcaption>
</figure>

###Example 3: SPI

 This example shows the basic settings and functions for retrieving accelerometer and gyroscopic data but using the SPI interface. Everything other than that is identical to the "basic" example. To find Example 3, go to **File** > **Examples** > **SparkFun 6DoF LSM6DSV16X** > **example3_spi**:

<figure markdown>
LSM6DSV16X Arduino Example 3
<figcaption markdown>Finding Example 3</figcaption>
</figure>

Alternatively, you can expand the link below and copy and paste the code into a shiny new Arduino sketch: 

??? "Example 3 Arduino Code"
	```
	--8<-- "https://raw.githubusercontent.com/sparkfun/SparkFun_LSM6DSV16X_Arduino_Library/main/examples/example3_spi/example3_spi.ino"
	```

The wiring for this example is fairly straight forward, if somewhat ugly. Here's what it looks like:

<figure markdown>
LSM6DSV16X Arduino Example 3
<figcaption markdown>Example 3</figcaption>
</figure>

And here are the connections:
<center>
<table>
    <th colspan="2" align="center"><b>Pin Connections</b></th>
    <tr align="center">
        <td><b>Qwiic Breakout Pin</b></td>
        <td><b>RedBoard Pin</b></td>    
    </tr>   
    <tr align="center">
        <td>PICO</td>
        <td>11</td>
    </tr>
    <tr align="center">
        <td>POCI</td>
        <td>12</td>       
    </tr> 
    <tr align="center">
        <td>SCLK</td>
        <td>13</td>
    </tr>
    <tr align="center"> 
        <td>CS</td> 
        <td>A4</td>
    </tr>
</table>
</center>

Once you get the correct port and board selected and the code is uploaded, you should see something like the following: 

<figure markdown>
LSM6DSV16X Arduino Example 3 Output
<figcaption markdown>Example 3 Output</figcaption>
</figure>

!!! attention
	If you are using the SparkFun RedBoard Qwiic and your output only says "Reset. Applying Settings." with no other output, make sure that you have your I/O jumper set correctly. You'll find the 3V3 vs 5V jumper on the front of the RedBoard Qwiic. You'll need to cut the connective trace to 5V and solder the center jumper pad to the 3V3 pad. More information can be found in the [RedBoard Qwiic Hookup Guide](https://learn.sparkfun.com/tutorials/redboard-qwiic-hookup-guide/all#hardware-overview). 

	<figure markdown>
	3V3/5V Jumper on the RedBoard
	<figcaption markdown>3V3/5V Jumper on the RedBoard</figcaption>
	</figure>

<!-- 
	https://github.com/sparkfun/SparkFun_LSM6DSV16X_Arduino_Library/blob/main/examples/example3_spi/example3_spi.ino
-->

### Further Examples

There are a few more examples in the library that get you started with I<sup>2</sup>C speeds, Qvar, and single/double tap. Feel free to explore and play with these examples to maximize your use of the SparkFun 6DoF - LSM6DSV16X (Qwiic) or  SparkFun Micro 6DoF - LSM6DSV16X (Qwiic)!

<!-- Starting comment of example 4
###Example 4: Basic Readings

 This example shows how to retrieve accelerometer and gyroscopic data as fast as the I2C bus will allow.

 If you want to run the accel and gyro at 416Hz, you need to use 400kHz I2C. See the Wire.setClock(400000); at the start of setup().

 This example also allows you to run the accel and gyro at different rates,
 should you want to. To find Example 4, go to **File** > **Examples** > **SparkFun 6DoF LSM6DSV16X** > **example4_faster_I2C**:

<figure markdown>
[![LSM6DSV16X Arduino Example 4](assets/imgs/Example4_Menu.jpg){ width="90%" }](assets/imgs/Example4_Menu.jpg "Click to enlarge")
<figcaption markdown>Finding Example 4</figcaption>
</figure>

Alternatively, you can expand the link below and copy and paste the code into a shiny new Arduino sketch: 

??? "Example 4 Arduino Code"
	```
	--8<-- "https://raw.githubusercontent.com/sparkfun/SparkFun_STTS22H_Arduino_Library/main/examples/example1-basic/example1-basic.ino"
	```

<!-- 
	https://github.com/sparkfun/SparkFun_LSM6DSV16X_Arduino_Library/blob/main/examples/example4_faster_I2C/example4_faster_I2C.ino
-->
<!-- Starting comment of example 5

###Example 5: Basic Readings

This example shows the basic setup and functions for the QVar sensing pins (AH1/AH2). 

Before running this example you'll need to cut the SDX and SCX jumpers on the bottom side of the board. These pins are not broken out on the micro.

The Qvar pins are analog input pins and can be used for a wide range of applications. However, to use them on the SparkFun 6DoF LSM6DSV16X you'll need to add some kind of filter, depending on your application, to the unpopulated pads. You can refer to the [two application notes from STMicroelectronics here](https://www.st.com/en/mems-and-sensors/lsm6dsv16x.html#documentation).

To find Example 5, go to **File** > **Examples** > **SparkFun 6DoF LSM6DSV16X** > **example5_qvar_sensing**:

<figure markdown>
[![LSM6DSV16X Arduino Example 5](assets/imgs/Example5_Menu.jpg){ width="90%" }](assets/imgs/Example5_Menu.jpg "Click to enlarge")
<figcaption markdown>Finding Example 5</figcaption>
</figure>

Alternatively, you can expand the link below and copy and paste the code into a shiny new Arduino sketch: 

??? "Example 5 Arduino Code"
	```
	--8<-- "https://raw.githubusercontent.com/sparkfun/SparkFun_STTS22H_Arduino_Library/main/examples/example1-basic/example1-basic.ino"
	```

<!-- 
	https://github.com/sparkfun/SparkFun_LSM6DSV16X_Arduino_Library/blob/main/examples/example5_qvar_sensing/example5_qvar_sensing.ino
-->

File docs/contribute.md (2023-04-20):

# Contribute: Make an Augmentation!
Spot an improvement opportunity? Feel free to contribute to our open-source design and documentation. 

## :material-file-document-multiple:&nbsp;Improve our Documentation
All of this documentation can be modified by you! Please help us make it better.

* These pages are contained in the [`docs` folder](https://github.com/sparkfun/SparkFun_6DoF_LSM6DSV16X/tree/main/docs) of the [SparkFun 6DoF - LSM6DSV16X (Qwiic) repository](https://github.com/sparkfun/SparkFun_6DoF_LSM6DSV16X).

### Submit a Correction

1. With a GitHub account, [fork this repository](https://github.com/sparkfun/SparkFun_6DoF_LSM6DSV16X/fork).
2. Add your corrections or improvements to the markdown file.
3. File a pull request with your changes, and enjoy making the ~~words~~ ~~worlds~~ world a better place.
	* Once received, the documentation specialist will automatically be notified.
	* We will review your suggested improvements to make sure they are correct and fit within our documentation standards.

## :material-cog:&nbsp;Improve our Hardware Design
All of our designs are open-source! Please help us make it better.

* Our board design files are contained in the [`Hardware` folder](https://github.com/sparkfun/SparkFun_6DoF_LSM6DSV16X/tree/main/Hardware) of the [SparkFun 6DoF - LSM6DSV16X (Qwiic) repository](https://github.com/sparkfun/SparkFun_6DoF_LSM6DSV16X).

1. With a GitHub account, [fork this repository](https://github.com/sparkfun/SparkFun_6DoF_LSM6DSV16X/fork).
2. Add your design augmentation(s)
3. File a pull request with your changes, and enjoy making the ~~words~~ ~~worlds~~ world a better place.
	1. Once received, the engineer in charge of the original design will automatically be notified.
	2. We will review your suggested improvement(s) to verify that they are within our board design standards and meet our product design requirements.
	3. If approved, we will flag these changes for our next board revision. Congrats! 🍻

		!!! info
			Even if your suggestion is accepted, these changes may not be immediately available for purchase. We may have to cycle through our current product inventory first.

## Contributors&nbsp;:clap:
Let's provide some recognition to the contributors for this project!

GitHub Contributors Image
<br>


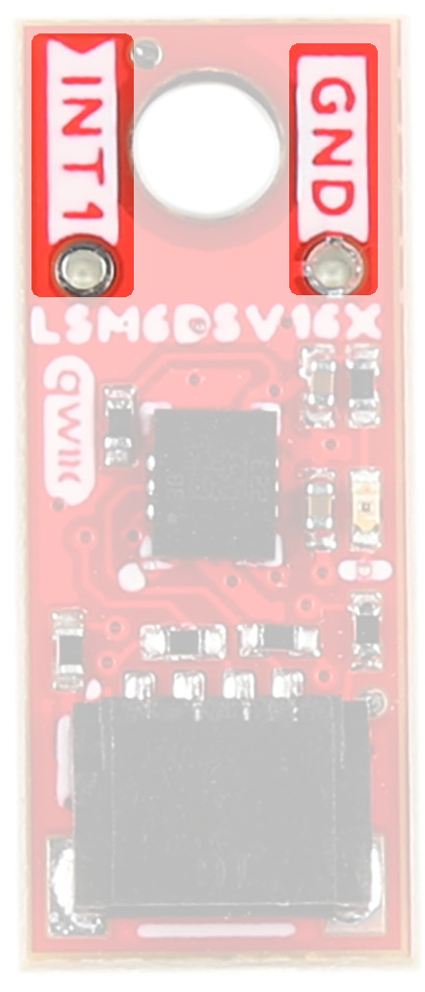
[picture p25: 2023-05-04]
docs/assets/imgs/21336_SparkFun_Micro_LSM6DSV16X_PTHs.jpg

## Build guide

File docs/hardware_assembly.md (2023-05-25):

The delightful thing about our Qwiic boards is that they are quite literally plug and play. 

<figure markdown>
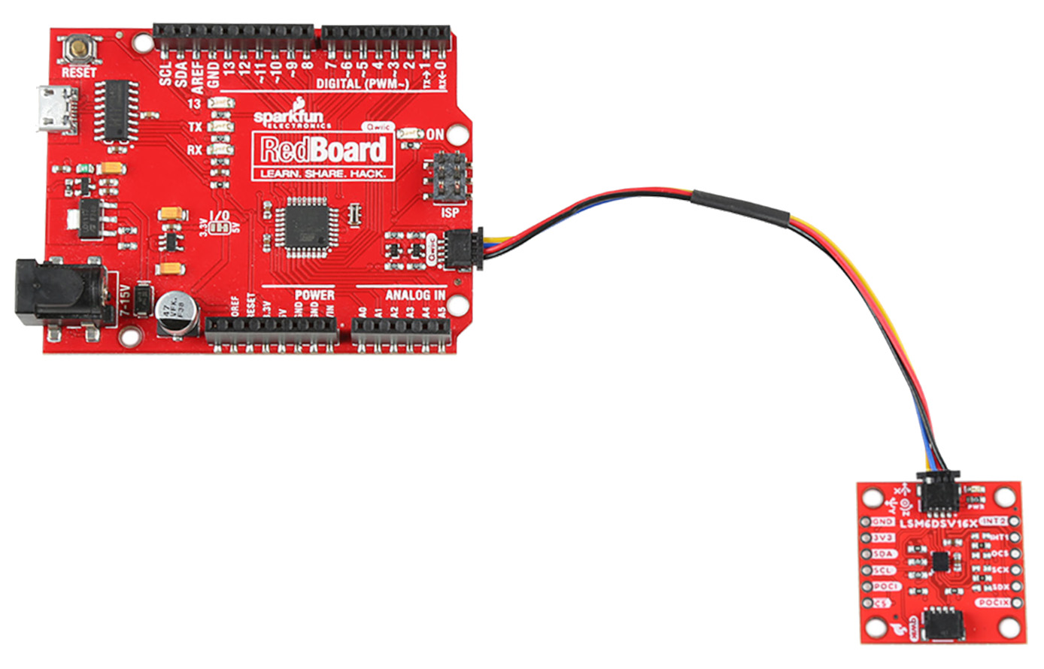
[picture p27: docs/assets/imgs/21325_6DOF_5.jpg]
SparkFun 6DoF - LSM6DSV16X (Qwiic) Plugged into the RedBoard Qwiic

<figcaption markdown>SparkFun 6DoF - LSM6DSV16X (Qwiic) Plugged into the RedBoard Qwiic</figcaption>
</figure>

<figure markdown>
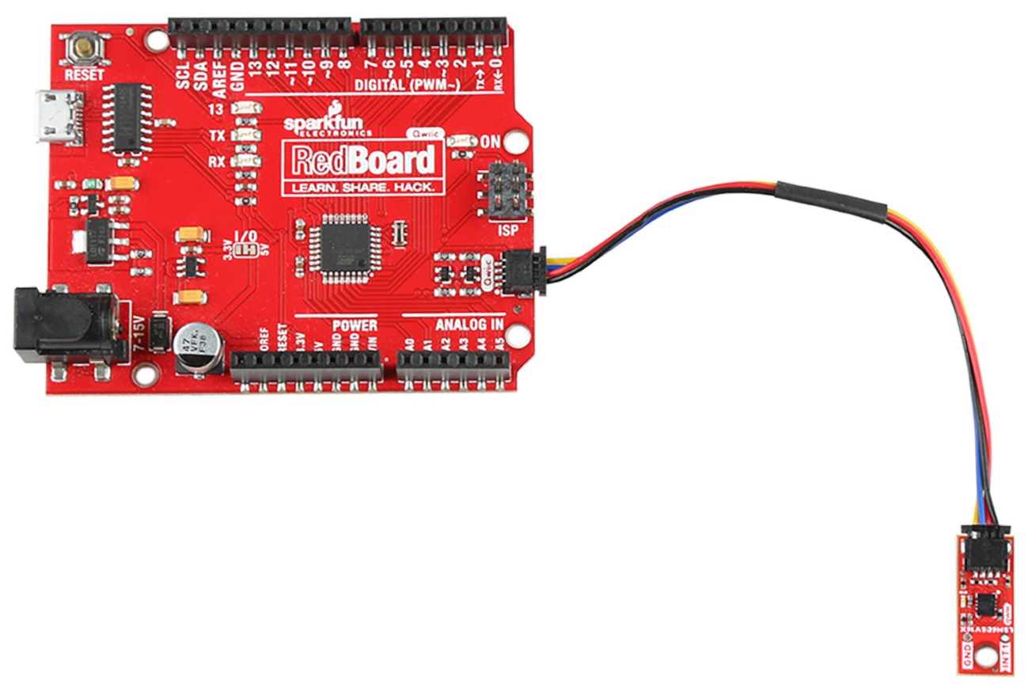
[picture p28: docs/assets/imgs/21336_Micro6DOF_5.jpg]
SparkFun 6DoF Micro - LSM6DSV16X (Qwiic) Plugged into the RedBoard Qwiic

<figcaption markdown>SparkFun 6DoF Micro - LSM6DSV16X (Qwiic)  Plugged into the RedBoard Qwiic</figcaption>
</figure>

!!! attention
	If you are using the SparkFun RedBoard Qwiic, make sure that you have your I/O jumper set correctly. You'll find the 3V3 vs 5V jumper on the front of the RedBoard Qwiic. You'll need to cut the connective trace to 5V and solder the center jumper pad to the 3V3 pad in order for the examples to work. More information can be found in the [RedBoard Qwiic Hookup Guide](https://learn.sparkfun.com/tutorials/redboard-qwiic-hookup-guide/all#hardware-overview). 

	<figure markdown>
	3V3/5V Jumper on the RedBoard
	<figcaption markdown>3V3/5V Jumper on the RedBoard</figcaption>
	</figure>

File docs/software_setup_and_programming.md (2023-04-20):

!!! attention
	If this is your first time using Arduino, please review our tutorial on [installing the Arduino IDE](https://learn.sparkfun.com/tutorials/installing-arduino-ide). If you have not previously installed an Arduino library, please check out our [installation guide](https://learn.sparkfun.com/tutorials/installing-an-arduino-library).

SparkFun has written a library to work with the SparkFun LSM6DSV16X Boards. You can obtain this library through the Arduino Library Manager by searching for "LSM6DSV16X" and installing the latest version. If you prefer downloading libraries manually, you can grab them from the GitHub Repository.

<center>
	[SparkFun LSM6DSV16X Arduino Library GitHub](https://github.com/sparkfun/SparkFun_LSM6DSV16X_Arduino_Library/archive/refs/heads/main.zip){ .md-button .md-button--primary }
</center>

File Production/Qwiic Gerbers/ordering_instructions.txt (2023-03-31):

panel size, 169x117mm
PCB thickness, 1.6mm
number of layers, 2
soldermask color, Red
silkscreen color, White
oz copper, 1oz
finish, HASL lead free
stencils, top
pcs per panel, 24
min trace width, 0.2540mm / 0.0100in
min drill size, 0.3048mm / 0.0120in

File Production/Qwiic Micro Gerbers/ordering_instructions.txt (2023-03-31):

panel size, 170x79mm
PCB thickness, 1.6mm
number of layers, 2
soldermask color, Red
silkscreen color, White
oz copper, 1oz
finish, HASL lead free
stencils, top
pcs per panel, 64
min trace width, 0.1524mm / 0.0060in
min drill size, 0.3000mm / 0.0118in

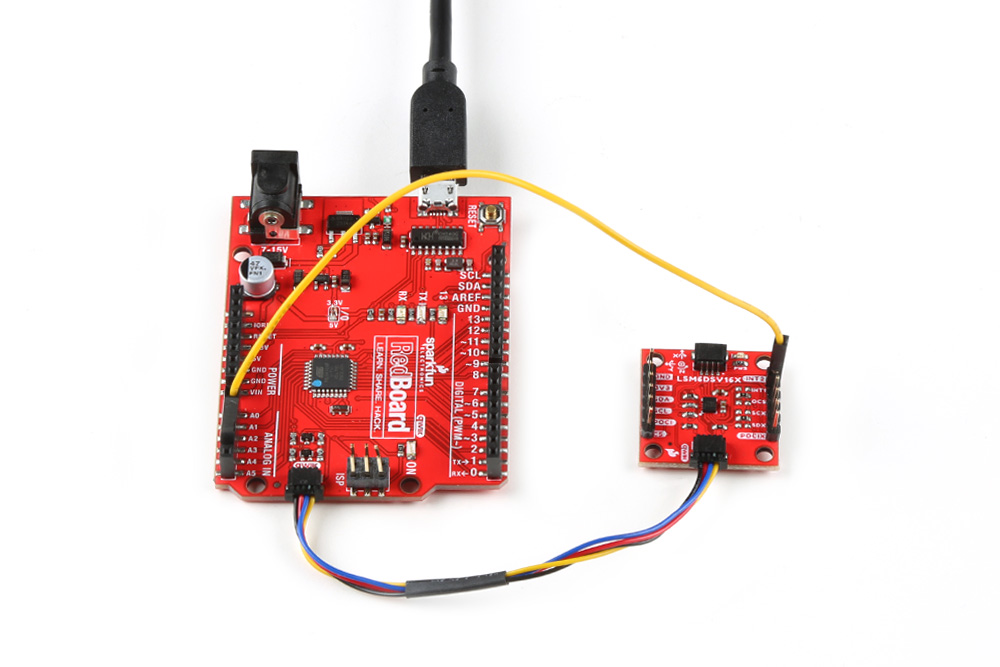
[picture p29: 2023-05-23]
docs/assets/imgs/Example2_WiringTake2.jpg

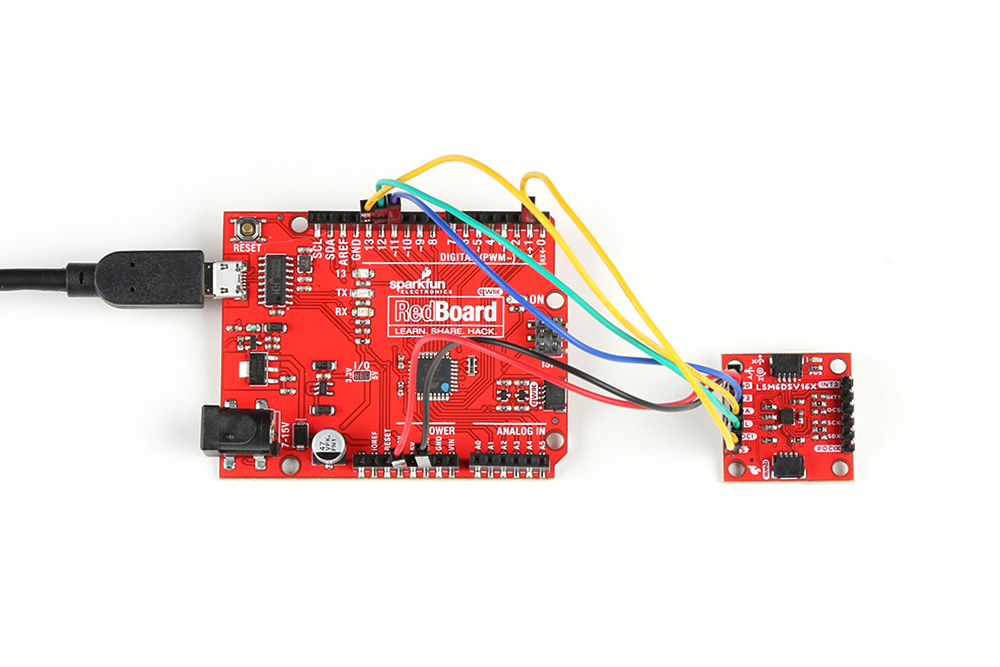
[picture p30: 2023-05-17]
docs/assets/imgs/Example3_Wiring.jpg

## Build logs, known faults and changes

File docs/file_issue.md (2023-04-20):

# Did we make a mistake?

Spot something wrong? Please let us know. 

!!! attention
    This is not where customers should seek assistance on a product. If you require technical assistance or have questions about a product that is not working as expected, please head over to the [SparkFun Technical Assistance](https://www.sparkfun.com/technical_assistance) page for some initial troubleshooting.
    <center>
    [SparkFun Technical Assistance Page](https://www.sparkfun.com/technical_assistance){ .md-button .md-button--primary }
    </center>
    
    If you can't find what you need there, you'll need a [Forum Account](https://forum.sparkfun.com/ucp.php?mode=register) to search product forums and post questions.

## Discrepancies in the Documentation

All of this documentation can be modified by you! Please help us make it better.

* The documentation files for these pages are contained in the [`docs` folder](https://github.com/sparkfun/SparkFun_6DoF_LSM6DSV16X/tree/main/docs) of the [SparkFun 6DoF - LSM6DSV16X (Qwiic)](https://github.com/sparkfun/SparkFun_6DoF_LSM6DSV16X) repository.

### Spot something wrong?
If a section of the documentation is incorrect, please [open an issue](https://github.com/sparkfun/SparkFun_6DoF_LSM6DSV16X/issues) and let us know.

### Do you have a suggested correction?
1. With a GitHub account, fork this repo
2. Add your correction(s) or improvement(s) to the markdown file(s)
3. File a pull request with your changes, and enjoy making the ~~words~~ ~~worlds~~ world a better place.
    * Once received, the documentation specialist will automatically be notified.
    * We will review your suggested improvement(s) to make sure they are correct and fit within our documentation standards.

## Problems in the Hardware Design

All of our designs are open-source! Please help us make it better.

* Our board design files are contained in the [`Hardware` folder](https://github.com/sparkfun/SparkFun_6DoF_LSM6DSV16X/tree/main/Hardware) of the [SparkFun 6DoF - LSM6DSV16X (Qwiic)](https://github.com/sparkfun/SparkFun_6DoF_LSM6DSV16X) repository. 

### Does something not make sense?
If part of the design is confusing, please [open an issue](https://github.com/sparkfun/SparkFun_6DoF_LSM6DSV16X/issues) and let us know.

### Did we forget to include an important function of the board?
* Please keep in mind that we may intentionally exclude certain functions of the board to meet our product design requirements. *(For example, our Qwiic Micro boards are intended to fit on a small board layout and only use I<sup>2</sup>C communication; therefore, we may not have the SPI and interrupt pins available for users.)*
* If part of the board's functionality is missing, please [open an issue](https://github.com/sparkfun/SparkFun_6DoF_LSM6DSV16X/issues) and file a feature request.

### Do you wish to contribute directly to improving the board design?
1. With a GitHub account, Fork this repo
2. Add your design improvement(s)
3. File a pull request with your changes, and enjoy making the ~~words~~ ~~worlds~~ world a better place.
    * Once received, the engineer in charge of the original design will automatically be notified.
    * We will review your suggested improvement(s), if they are within our board design standards and meet our product design requirements, we will flag these changes for our next board revision. *(Please note, that even if your suggestion is accepted, these changes may not be immediate. We may have to cycle through our current product inventory first.)*

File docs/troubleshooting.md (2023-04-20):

!!! note
    <span class="glyphicon glyphicon-question-sign" aria-hidden="true"></span>
        <strong> Not working as expected and need help? </strong> <br /><br />

    If you need technical assistance and more information on a product that is not working as you expected, we recommend heading on over to the <a href="https://www.sparkfun.com/technical_assistance">SparkFun Technical Assistance</a> page for some initial troubleshooting. <br /><br />

    <div style="text-align: center"><a href="https://www.sparkfun.com/technical_assistance" target="sfe_technical_assistance" class="md-button">SparkFun Technical Assistance Page</a></div>

    If you don't find what you need there, the <a href="https://forum.sparkfun.com/index.php">SparkFun Forums</a> are a great place to find and ask for help. If this is your first visit, you'll need to <a href="https://forum.sparkfun.com/ucp.php?mode=register">create a Forum Account</a> to search product forums and post questions.<br /><br />

    <div style="text-align: center"><a href="https://forum.sparkfun.com/ucp.php?mode=register" class="md-button">Create New Forum Account</a>&nbsp;&nbsp;&nbsp;<a href="https://forum.sparkfun.com/index.php" class="md-button md-button--primary">Log Into SparkFun Forums</a></div>

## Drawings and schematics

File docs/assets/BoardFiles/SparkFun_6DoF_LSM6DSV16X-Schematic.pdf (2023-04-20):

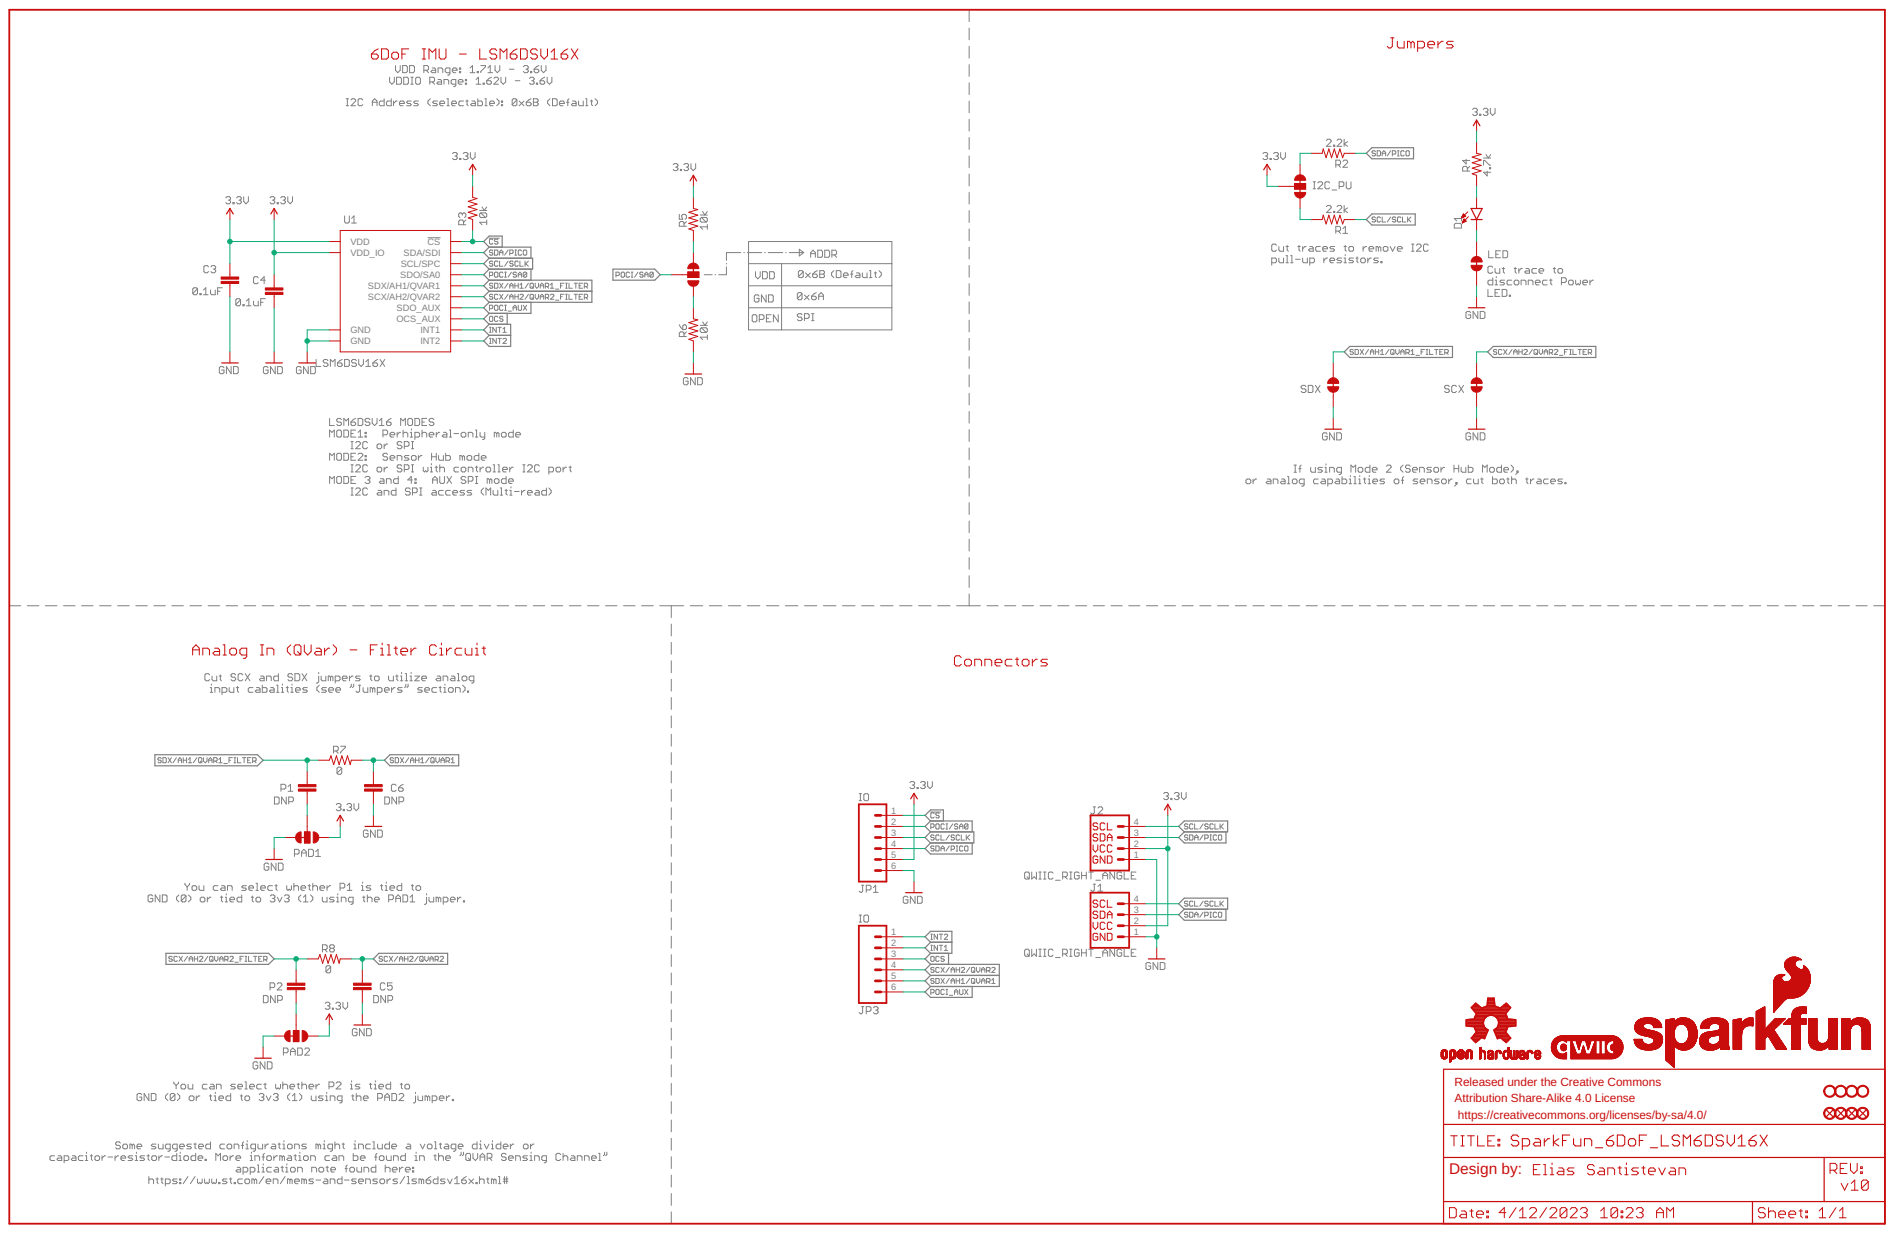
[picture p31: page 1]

SDA/SDI SCL/SPC

Released under the Creative Commons Attribution Share-Alike 4.0 License

https://creativecommons.org/licenses/by-sa/4.0/ Design by:

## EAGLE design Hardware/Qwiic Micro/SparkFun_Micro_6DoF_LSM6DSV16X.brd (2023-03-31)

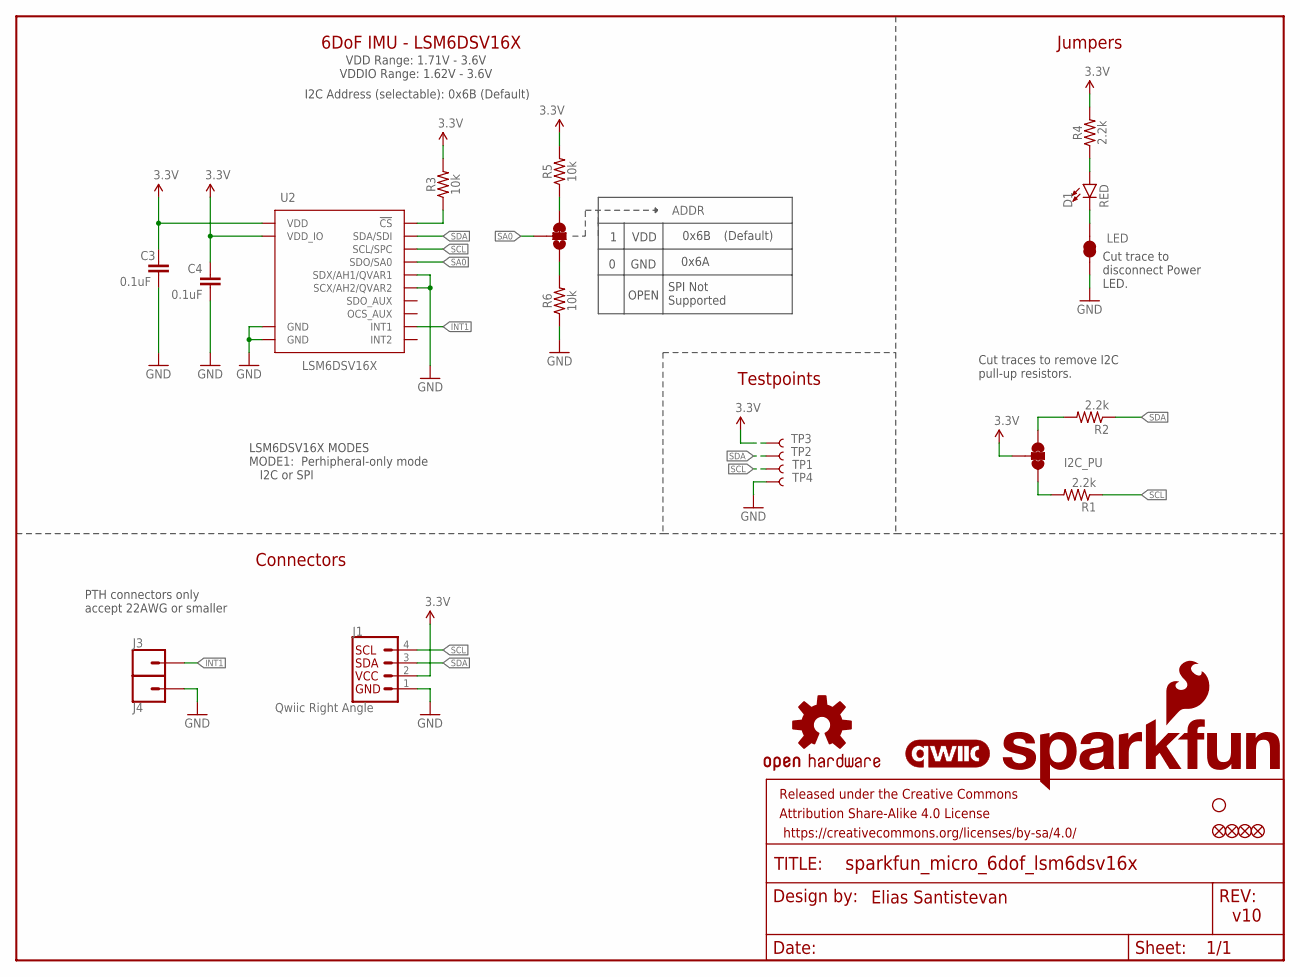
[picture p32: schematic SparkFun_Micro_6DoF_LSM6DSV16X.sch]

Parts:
ADDR: JUMPER-SMT_3_1-NC_TRACE_SILK; SMT-JUMPER_3_1-NC_TRACE_SILK
C3, C4: 0.1uF; 0402-TIGHT
D1: RED; LED-0402
FD1, FD2: FIDUCIALUFIDUCIAL; FIDUCIAL-MICRO
FID1, FID2: FIDUCIALUFIDUCIAL; FIDUCIAL-MICRO
FRAME1: FRAME-LETTER; CREATIVE_COMMONS
I2C_PU: S_MODE; SMT-JUMPER_3_2-NC_TRACE_SILK
J1: Qwiic Right Angle; JST04_1MM_RA
J3, J4: CONN_01_1MM; 1X01_1MM_NO_SILK
LED: JUMPER-SMT_2_NC_TRACE_SILK; SMT-JUMPER_2_NC_TRACE_SILK
LOGO1: QWIIC_LOGO_3MM; QWIIC_3MM
LOGO2: OSHW-LOGOMINI; OSHW-LOGO-MINI
LOGO3: SFE_LOGO_NAME_FLAMEBLANK; BLANK
R1, R2, R4: 2.2k; 0402-TIGHT
R3, R5, R6: 10k; 0402-TIGHT
STANDOFF1: STAND-OFFTIGHT; STAND-OFF-TIGHT
TP1, TP2, TP3, TP4: TEST-POINT3; PAD.03X.03
U2: LSM6DSV16X; LGA-14L

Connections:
3.3V: C3.1, C4.1, I2C_PU.2, J1.2, R3.2, R4.2, R5.2, TP3.1, U2.P5 (VDD_IO), U2.P8 (VDD)
GND: C3.2, C4.2, J1.1, J4.1, LED.1, R6.1, TP4.1, U2.P2 (SDX/AH1/QVAR1), U2.P3 (SCX/AH2/QVAR2), U2.P6 (GND), U2.P7 (GND)
INT1: J3.1, U2.P4 (INT1)
unnamed: ADDR.3, R5.1
unnamed: D1.A, R4.1
unnamed: D1.C, LED.2
unnamed: R3.1, U2.P12 (!CS!)
unnamed: I2C_PU.1, R1.2
unnamed: I2C_PU.3, R2.2
unnamed: ADDR.1, R6.2
SA0: ADDR.2, U2.P1 (SDO/SA0)
SCL: J1.4, R1.1, TP1.1, U2.P13 (SCL/SPC)
SDA: J1.3, R2.1, TP2.1, U2.P14 (SDA/SDI)

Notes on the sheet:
6DoF IMU - LSM6DSV16X
Cut traces to remove I2C pull-up resistors.
LSM6DSV16X MODES MODE1: Perhipheral-only mode I2C or SPI
VDD Range: 1.71V - 3.6V VDDIO Range: 1.62V - 3.6V
v10
Jumpers
Cut trace to disconnect Power LED.
Connectors
VDD
GND
OPEN
0x6B
0x6A
Elias Santistevan
SPI Not Supported
Testpoints
(Default)
I2C Address (selectable): 0x6B (Default)
PTH connectors only accept 22AWG or smaller

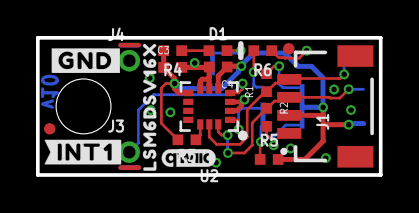
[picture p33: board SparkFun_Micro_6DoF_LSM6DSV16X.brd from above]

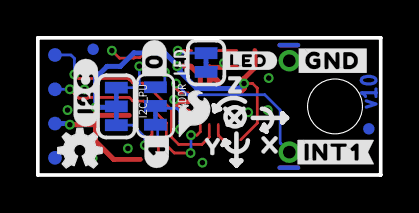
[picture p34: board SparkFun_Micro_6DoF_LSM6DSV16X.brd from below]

Board: 2 copper layers, 19.1 x 7.6 mm, 42 parts (20 on the bottom side), 13 nets.

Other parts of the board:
U$1: #0#4
U$2: #1#4
U$3: #LED#2121
U$4, U$10: #GND#4
U$5: #INT1#0
U$6: LSM6DSV16X31
U$7: X2114
U$8: Y2115
U$9: Z2116
U$11: #INT1#2
U$12: #I2C#4
U$29: SFE_LOGO_FLAME_.1

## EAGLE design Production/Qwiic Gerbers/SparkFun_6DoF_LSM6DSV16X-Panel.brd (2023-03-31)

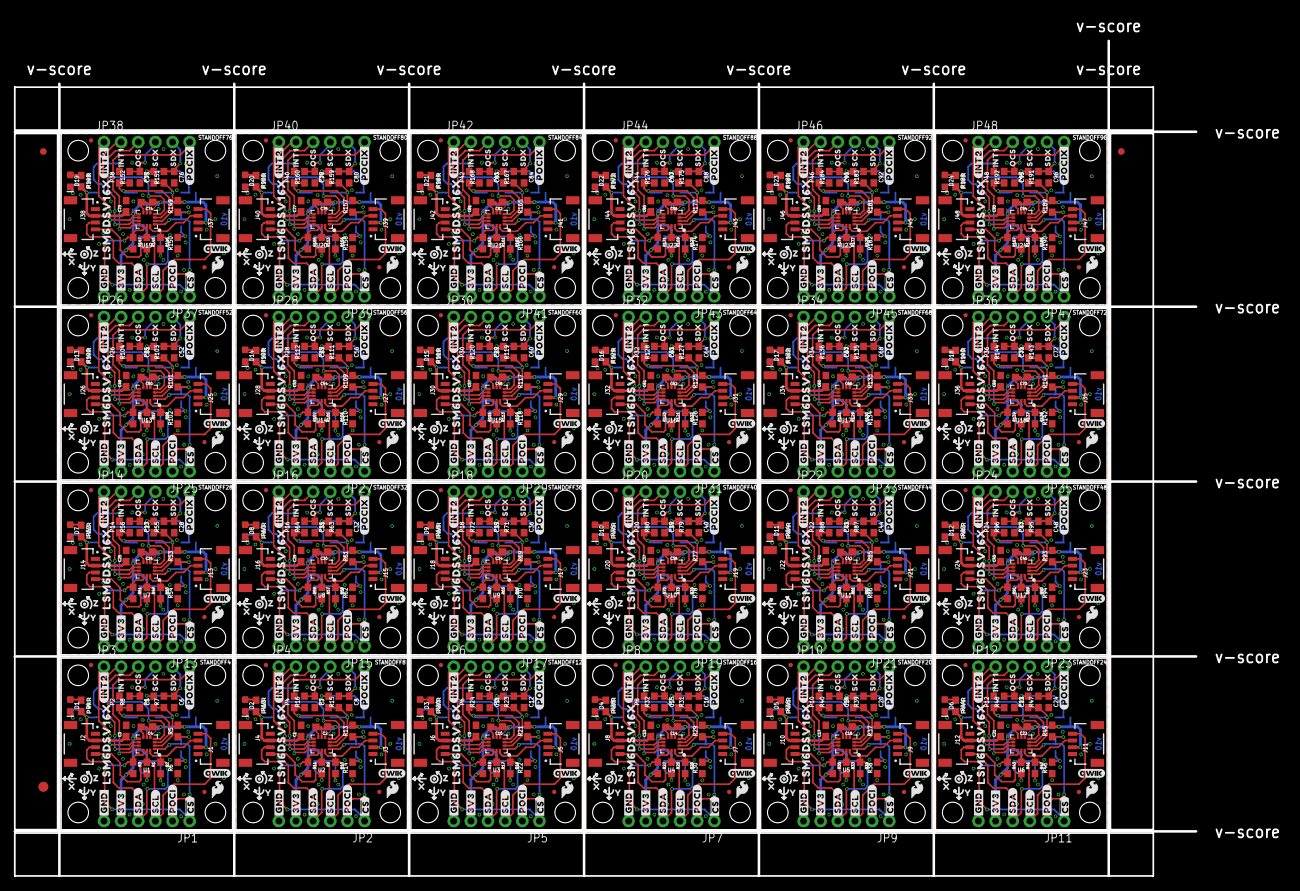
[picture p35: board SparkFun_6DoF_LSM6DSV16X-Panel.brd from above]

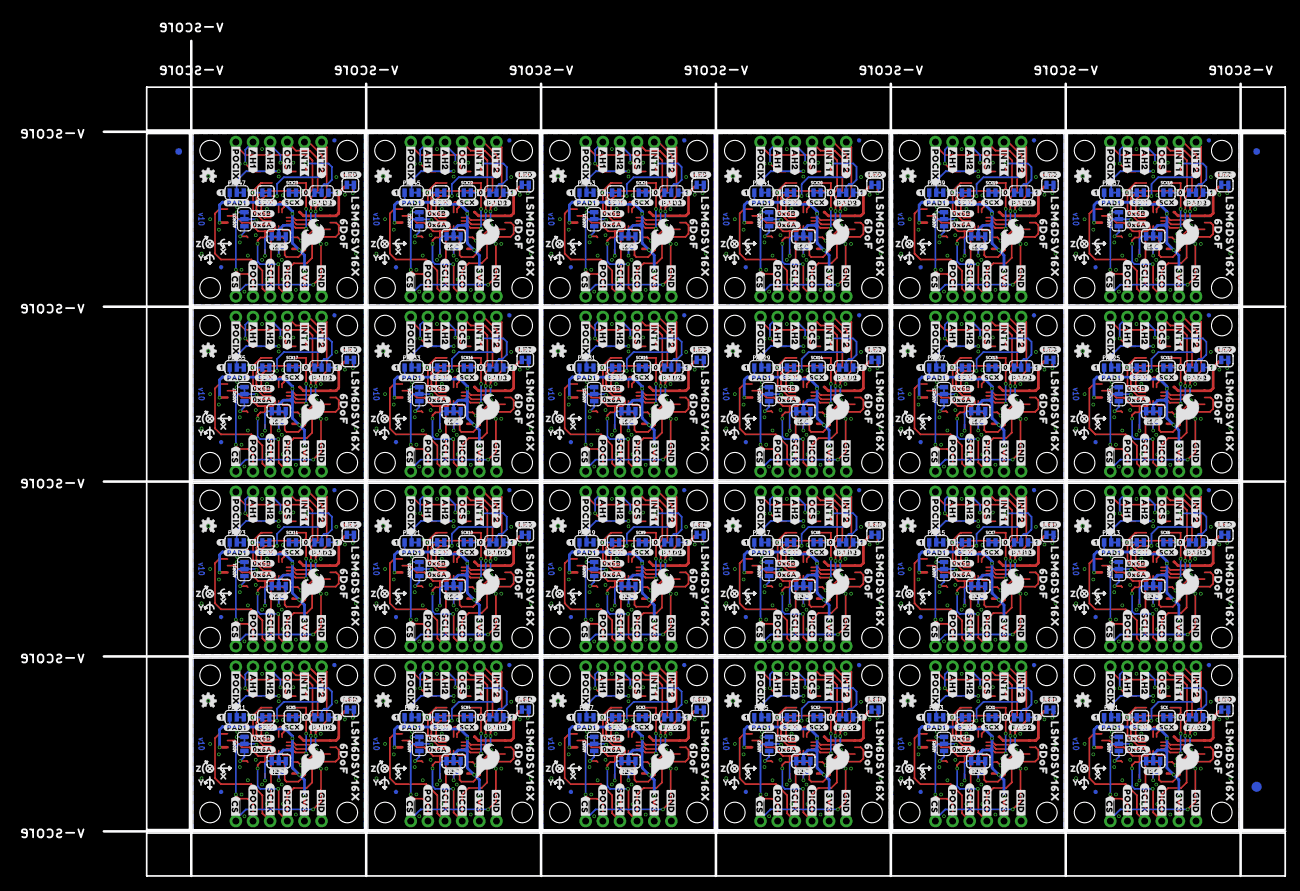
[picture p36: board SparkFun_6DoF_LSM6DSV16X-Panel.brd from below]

Board: 2 copper layers, 175.0 x 123.7 mm, 2094 parts (963 on the bottom side), 528 nets.

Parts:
ADDR, ADDR1, ADDR2, ADDR3, ADDR4, ADDR5, ADDR6, ADDR7, ADDR8, ADDR9, ADDR10, ADDR11, ADDR12, ADDR13, ADDR14, ADDR15, ADDR16, ADDR17, ADDR18, ADDR19, ADDR20, ADDR21, ADDR22, ADDR23: JUMPER-SMT_3_1-NC_TRACE_SILK; SMT-JUMPER_3_1-NC_TRACE_SILK
C1, C2, C3, C4, C9, C10, C13, C14, C17, C18, C21, C22, C25, C26, C29, C30, C33, C34, C37, C38, C41, C42, C45, C46, C49, C50, C53, C54, C57, C58, C61, C62, C65, C66, C69, C70, C73, C74, C77, C78, C81, C82, C85, C86, C89, C90, C93, C94: 0.1uF; 0603
C5, C6, C7, C8, C11, C12, C15, C16, C19, C20, C23, C24, C27, C28, C31, C32, C35, C36, C39, C40, C43, C44, C47, C48, C51, C52, C55, C56, C59, C60, C63, C64, C67, C68, C71, C72, C75, C76, C79, C80, C83, C84, C87, C88, C91, C92, C95, C96: 110pF; 0603
D1, D2, D3, D4, D5, D6, D7, D8, D9, D10, D11, D12, D13, D14, D15, D16, D17, D18, D19, D20, D21, D22, D23, D24: RED; LED-0603
E$1, E$2, E$3, E$4: FIDUCIAL-1X2
E$5, E$6: FIDUCIAL-1.5X3
FD1, FD2, FD3, FD4, FD5, FD6, FD7, FD8, FD9, FD10, FD11, FD12, FD13, FD14, FD15, FD16, FD17, FD18, FD19, FD20, FD21, FD22, FD23, FD24, FD25, FD26, FD27, FD28, FD29, FD30, FD31, FD32, FD33, FD34, FD35, FD36, FD37, FD38, FD39, FD40, FD41, FD42, FD43, FD44, FD45, FD46, FD47, FD48: FIDUCIALUFIDUCIAL; FIDUCIAL-MICRO
FID1, FID2, FID3, FID4, FID5, FID6, FID7, FID8, FID9, FID10, FID11, FID12, FID13, FID14, FID15, FID16, FID17, FID18, FID19, FID20, FID21, FID22, FID23, FID24, FID25, FID26, FID27, FID28, FID29, FID30, FID31, FID32, FID33, FID34, FID35, FID36, FID37, FID38, FID39, FID40, FID41, FID42, FID43, FID44, FID45, FID46, FID47, FID48: FIDUCIALUFIDUCIAL; FIDUCIAL-MICRO
FRAME1, FRAME2, FRAME3, FRAME4, FRAME5, FRAME6, FRAME7, FRAME8, FRAME9, FRAME10, FRAME11, FRAME12, FRAME13, FRAME14, FRAME15, FRAME16, FRAME17, FRAME18, FRAME19, FRAME20, FRAME21, FRAME22, FRAME23, FRAME24: FRAME-LEDGER; CREATIVE_COMMONS
I2C_PU, I2C_PU1, I2C_PU2, I2C_PU3, I2C_PU4, I2C_PU5, I2C_PU6, I2C_PU7, I2C_PU8, I2C_PU9, I2C_PU10, I2C_PU11, I2C_PU12, I2C_PU13, I2C_PU14, I2C_PU15, I2C_PU16, I2C_PU17, I2C_PU18, I2C_PU19, I2C_PU20, I2C_PU21, I2C_PU22, I2C_PU23: S_MODE; SMT-JUMPER_3_2-NC_TRACE_SILK
J1, J2, J3, J4, J5, J6, J7, J8, J9, J10, J11, J12, J13, J14, J15, J16, J17, J18, J19, J20, J21, J22, J23, J24, J25, J26, J27, J28, J29, J30, J31, J32, J33, J34, J35, J36, J37, J38, J39, J40, J41, J42, J43, J44, J45, J46, J47, J48: QWIIC_RIGHT_ANGLE; JST04_1MM_RA
JP1, JP2, JP3, JP4, JP5, JP6, JP7, JP8, JP9, JP10, JP11, JP12, JP13, JP14, JP15, JP16, JP17, JP18, JP19, JP20, JP21, JP22, JP23, JP24, JP25, JP26, JP27, JP28, JP29, JP30, JP31, JP32, JP33, JP34, JP35, JP36, JP37, JP38, JP39, JP40, JP41, JP42, JP43, JP44, JP45, JP46, JP47, JP48: IO; 1X06_NO_SILK
LED, LED1, LED2, LED3, LED4, LED5, LED6, LED7, LED8, LED9, LED10, LED11, LED12, LED13, LED14, LED15, LED16, LED17, LED18, LED19, LED20, LED21, LED22, LED23: JUMPER-SMT_2_NC_TRACE_SILK; SMT-JUMPER_2_NC_TRACE_SILK
LOGO1, LOGO5, LOGO8, LOGO11, LOGO14, LOGO17, LOGO20, LOGO23, LOGO26, LOGO29, LOGO32, LOGO35, LOGO38, LOGO41, LOGO44, LOGO47, LOGO50, LOGO53, LOGO56, LOGO59, LOGO62, LOGO65, LOGO68, LOGO71: QWIIC_LOGO_4MM; QWIIC_4MM
LOGO2, LOGO4, LOGO7, LOGO10, LOGO13, LOGO16, LOGO19, LOGO22, LOGO25, LOGO28, LOGO31, LOGO34, LOGO37, LOGO40, LOGO43, LOGO46, LOGO49, LOGO52, LOGO55, LOGO58, LOGO61, LOGO64, LOGO67, LOGO70: OSHW-LOGOMINI; OSHW-LOGO-MINI
LOGO3, LOGO6, LOGO9, LOGO12, LOGO15, LOGO18, LOGO21, LOGO24, LOGO27, LOGO30, LOGO33, LOGO36, LOGO39, LOGO42, LOGO45, LOGO48, LOGO51, LOGO54, LOGO57, LOGO60, LOGO63, LOGO66, LOGO69, LOGO72: SFE_LOGO_NAME_FLAMEBLANK; BLANK
P1, P2, P3, P4, P5, P6, P7, P8, P9, P10, P11, P12, P13, P14, P15, P16, P17, P18, P19, P20, P21, P22, P23, P24, P25, P26, P27, P28, P29, P30, P31, P32, P33, P34, P35, P36, P37, P38, P39, P40, P41, P42, P43, P44, P45, P46, P47, P48: 110pF; 0603
PAD1, PAD2, PAD3, PAD4, PAD5, PAD6, PAD7, PAD8, PAD9, PAD10, PAD11, PAD12, PAD13, PAD14, PAD15, PAD16, PAD17, PAD18, PAD19, PAD20, PAD21, PAD22, PAD23, PAD24, PAD25, PAD26, PAD27, PAD28, PAD29, PAD30, PAD31, PAD32, PAD33, PAD34, PAD35, PAD36, PAD37, PAD38, PAD39, PAD40, PAD41, PAD42, PAD43, PAD44, PAD45, PAD46, PAD47, PAD48: JUMPER-SMT_3_1-NC_TRACE_SILK; SMT-JUMPER_3_1-NC_TRACE_SILK
R1, R2, R9, R10, R17, R18, R25, R26, R33, R34, R41, R42, R49, R50, R57, R58, R65, R66, R73, R74, R81, R82, R89, R90, R97, R98, R105, R106, R113, R114, R121, R122, R129, R130, R137, R138, R145, R146, R153, R154, R161, R162, R169, R170, R177, R178, R185, R186: 2.2k; 0603
R3, R5, R6, R11, R13, R14, R19, R21, R22, R27, R29, R30, R35, R37, R38, R43, R45, R46, R51, R53, R54, R59, R61, R62, R67, R69, R70, R75, R77, R78, R83, R85, R86, R91, R93, R94, R99, R101, R102, R107, R109, R110, R115, R117, R118, R123, R125, R126, R131, R133, R134, R139, R141, R142, R147, R149, R150, R155, R157, R158, R163, R165, R166, R171, R173, R174, R179, R181, R182, R187, R189, R190: 10k; 0603
R4, R12, R20, R28, R36, R44, R52, R60, R68, R76, R84, R92, R100, R108, R116, R124, R132, R140, R148, R156, R164, R172, R180, R188: 4.7k; 0603
R7, R8, R15, R16, R23, R24, R31, R32, R39, R40, R47, R48, R55, R56, R63, R64, R71, R72, R79, R80, R87, R88, R95, R96, R103, R104, R111, R112, R119, R120, R127, R128, R135, R136, R143, R144, R151, R152, R159, R160, R167, R168, R175, R176, R183, R184, R191, R192: 0; 0603
SCX, SCX1, SCX2, SCX3, SCX4, SCX5, SCX6, SCX7, SCX8, SCX9, SCX10, SCX11, SCX12, SCX13, SCX14, SCX15, SCX16, SCX17, SCX18, SCX19, SCX20, SCX21, SCX22, SCX23: JUMPER-SMT_2_NC_TRACE_SILK; SMT-JUMPER_2_NC_TRACE_SILK
SDX, SDX1, SDX2, SDX3, SDX4, SDX5, SDX6, SDX7, SDX8, SDX9, SDX10, SDX11, SDX12, SDX13, SDX14, SDX15, SDX16, SDX17, SDX18, SDX19, SDX20, SDX21, SDX22, SDX23: JUMPER-SMT_2_NC_TRACE_SILK; SMT-JUMPER_2_NC_TRACE_SILK
STANDOFF1, STANDOFF2, STANDOFF3, STANDOFF4, STANDOFF5, STANDOFF6, STANDOFF7, STANDOFF8, STANDOFF9, STANDOFF10, STANDOFF11, STANDOFF12, STANDOFF13, STANDOFF14, STANDOFF15, STANDOFF16, STANDOFF17, STANDOFF18, STANDOFF19, STANDOFF20, STANDOFF21, STANDOFF22, STANDOFF23, STANDOFF24, STANDOFF25, STANDOFF26, STANDOFF27, STANDOFF28, STANDOFF29, STANDOFF30, STANDOFF31, STANDOFF32, STANDOFF33, STANDOFF34, STANDOFF35, STANDOFF36, STANDOFF37, STANDOFF38, STANDOFF39, STANDOFF40, STANDOFF41, STANDOFF42, STANDOFF43, STANDOFF44, STANDOFF45, STANDOFF46, STANDOFF47, STANDOFF48, STANDOFF49, STANDOFF50, STANDOFF51, STANDOFF52, STANDOFF53, STANDOFF54, STANDOFF55, STANDOFF56, STANDOFF57, STANDOFF58, STANDOFF59, STANDOFF60, STANDOFF61, STANDOFF62, STANDOFF63, STANDOFF64, STANDOFF65, STANDOFF66, STANDOFF67, STANDOFF68, STANDOFF69, STANDOFF70, STANDOFF71, STANDOFF72, STANDOFF73, STANDOFF74, STANDOFF75, STANDOFF76, STANDOFF77, STANDOFF78, STANDOFF79, STANDOFF80, STANDOFF81, STANDOFF82, STANDOFF83, STANDOFF84, STANDOFF85, STANDOFF86, STANDOFF87, STANDOFF88, STANDOFF89, STANDOFF90, STANDOFF91, STANDOFF92, STANDOFF93, STANDOFF94, STANDOFF95, STANDOFF96: STAND-OFFTIGHT; STAND-OFF-TIGHT
U1, U2, U3, U4, U5, U6, U7, U8, U9, U10, U11, U12, U13, U14, U15, U16, U17, U18, U19, U20, U21, U22, U23, U24: LSM6DSV16X; LGA-14L
U$1, U$15, U$22, U$53, U$97, U$101, U$145, U$149, U$193, U$197, U$241, U$245, U$289, U$293, U$337, U$341, U$385, U$389, U$433, U$437, U$481, U$485, U$529, U$533, U$577, U$581, U$625, U$629, U$673, U$677, U$721, U$725, U$769, U$773, U$817, U$821, U$865, U$869, U$913, U$917, U$961, U$965, U$1009, U$1013, U$1057, U$1061, U$1105, U$1109: #3V3#1
U$2, U$17, U$50, U$54, U$98, U$102, U$146, U$150, U$194, U$198, U$242, U$246, U$290, U$294, U$338, U$342, U$386, U$390, U$434, U$438, U$482, U$486, U$530, U$534, U$578, U$582, U$626, U$630, U$674, U$678, U$722, U$726, U$770, U$774, U$818, U$822, U$866, U$870, U$914, U$918, U$962, U$966, U$1010, U$1014, U$1058, U$1062, U$1106, U$1110: #GND#0
U$3, U$59, U$107, U$155, U$203, U$251, U$299, U$347, U$395, U$443, U$491, U$539, U$587, U$635, U$683, U$731, U$779, U$827, U$875, U$923, U$971, U$1019, U$1067, U$1115: ##CS##7
U$4, U$51, U$99, U$147, U$195, U$243, U$291, U$339, U$387, U$435, U$483, U$531, U$579, U$627, U$675, U$723, U$771, U$819, U$867, U$915, U$963, U$1011, U$1059, U$1107: #SDA#4
U$5, U$52, U$100, U$148, U$196, U$244, U$292, U$340, U$388, U$436, U$484, U$532, U$580, U$628, U$676, U$724, U$772, U$820, U$868, U$916, U$964, U$1012, U$1060, U$1108: #SCL#5
U$6, U$66, U$114, U$162, U$210, U$258, U$306, U$354, U$402, U$450, U$498, U$546, U$594, U$642, U$690, U$738, U$786, U$834, U$882, U$930, U$978, U$1026, U$1074, U$1122: #POCI#11
U$7, U$76, U$124, U$172, U$220, U$268, U$316, U$364, U$412, U$460, U$508, U$556, U$604, U$652, U$700, U$748, U$796, U$844, U$892, U$940, U$988, U$1036, U$1084, U$1132: INT16
U$8, U$75, U$123, U$171, U$219, U$267, U$315, U$363, U$411, U$459, U$507, U$555, U$603, U$651, U$699, U$747, U$795, U$843, U$891, U$939, U$987, U$1035, U$1083, U$1131: #INT2#2
U$9, U$77, U$125, U$173, U$221, U$269, U$317, U$365, U$413, U$461, U$509, U$557, U$605, U$653, U$701, U$749, U$797, U$845, U$893, U$941, U$989, U$1037, U$1085, U$1133: OCS17
U$10, U$78, U$126, U$174, U$222, U$270, U$318, U$366, U$414, U$462, U$510, U$558, U$606, U$654, U$702, U$750, U$798, U$846, U$894, U$942, U$990, U$1038, U$1086, U$1134: SCX18
U$11, U$79, U$127, U$175, U$223, U$271, U$319, U$367, U$415, U$463, U$511, U$559, U$607, U$655, U$703, U$751, U$799, U$847, U$895, U$943, U$991, U$1039, U$1087, U$1135: SDX19
U$12, U$84, U$132, U$180, U$228, U$276, U$324, U$372, U$420, U$468, U$516, U$564, U$612, U$660, U$708, U$756, U$804, U$852, U$900, U$948, U$996, U$1044, U$1092, U$1140: #AH1#32
U$13, U$55, U$103, U$151, U$199, U$247, U$295, U$343, U$391, U$439, U$487, U$535, U$583, U$631, U$679, U$727, U$775, U$823, U$871, U$919, U$967, U$1015, U$1063, U$1111: #0X6A#11
U$14, U$56, U$104, U$152, U$200, U$248, U$296, U$344, U$392, U$440, U$488, U$536, U$584, U$632, U$680, U$728, U$776, U$824, U$872, U$920, U$968, U$1016, U$1064, U$1112: #0X6B#11
U$16, U$96, U$144, U$192, U$240, U$288, U$336, U$384, U$432, U$480, U$528, U$576, U$624, U$672, U$720, U$768, U$816, U$864, U$912, U$960, U$1008, U$1056, U$1104, U$1152: #LED#4
U$18, U$67, U$115, U$163, U$211, U$259, U$307, U$355, U$403, U$451, U$499, U$547, U$595, U$643, U$691, U$739, U$787, U$835, U$883, U$931, U$979, U$1027, U$1075, U$1123: #POCI#12
U$19, U$85, U$133, U$181, U$229, U$277, U$325, U$373, U$421, U$469, U$517, U$565, U$613, U$661, U$709, U$757, U$805, U$853, U$901, U$949, U$997, U$1045, U$1093, U$1141: #AH2#32
U$20, U$86, U$134, U$182, U$230, U$278, U$326, U$374, U$422, U$470, U$518, U$566, U$614, U$662, U$710, U$758, U$806, U$854, U$902, U$950, U$998, U$1046, U$1094, U$1142: #OCS#32
U$21, U$87, U$135, U$183, U$231, U$279, U$327, U$375, U$423, U$471, U$519, U$567, U$615, U$663, U$711, U$759, U$807, U$855, U$903, U$951, U$999, U$1047, U$1095, U$1143: #INT1#25
U$23, U$93, U$141, U$189, U$237, U$285, U$333, U$381, U$429, U$477, U$525, U$573, U$621, U$669, U$717, U$765, U$813, U$861, U$909, U$957, U$1005, U$1053, U$1101, U$1149: #PAD1#4
U$24, U$63, U$111, U$159, U$207, U$255, U$303, U$351, U$399, U$447, U$495, U$543, U$591, U$639, U$687, U$735, U$783, U$831, U$879, U$927, U$975, U$1023, U$1071, U$1119: #POCIX#8
U$25, U$57, U$105, U$153, U$201, U$249, U$297, U$345, U$393, U$441, U$489, U$537, U$585, U$633, U$681, U$729, U$777, U$825, U$873, U$921, U$969, U$1017, U$1065, U$1113: #I2C#11
U$26, U$65, U$113, U$161, U$209, U$257, U$305, U$353, U$401, U$449, U$497, U$545, U$593, U$641, U$689, U$737, U$785, U$833, U$881, U$929, U$977, U$1025, U$1073, U$1121: #PICO#13
U$27, U$60, U$108, U$156, U$204, U$252, U$300, U$348, U$396, U$444, U$492, U$540, U$588, U$636, U$684, U$732, U$780, U$828, U$876, U$924, U$972, U$1020, U$1068, U$1116: ##CS##8
U$28, U$58, U$106, U$154, U$202, U$250, U$298, U$346, U$394, U$442, U$490, U$538, U$586, U$634, U$682, U$730, U$778, U$826, U$874, U$922, U$970, U$1018, U$1066, U$1114: PWR8
U$29, U$62, U$110, U$158, U$206, U$254, U$302, U$350, U$398, U$446, U$494, U$542, U$590, U$638, U$686, U$734, U$782, U$830, U$878, U$926, U$974, U$1022, U$1070, U$1118: SFE_LOGO_FLAME_.1
U$30, U$94, U$142, U$190, U$238, U$286, U$334, U$382, U$430, U$478, U$526, U$574, U$622, U$670, U$718, U$766, U$814, U$862, U$910, U$958, U$1006, U$1054, U$1102, U$1150: #PAD2#4
U$31, U$61, U$109, U$157, U$205, U$253, U$301, U$349, U$397, U$445, U$493, U$541, U$589, U$637, U$685, U$733, U$781, U$829, U$877, U$925, U$973, U$1021, U$1069, U$1117: 6DOF12
U$32, U$89, U$137, U$185, U$233, U$281, U$329, U$377, U$425, U$473, U$521, U$569, U$617, U$665, U$713, U$761, U$809, U$857, U$905, U$953, U$1001, U$1049, U$1097, U$1145: #1#729
U$33, U$64, U$112, U$160, U$208, U$256, U$304, U$352, U$400, U$448, U$496, U$544, U$592, U$640, U$688, U$736, U$784, U$832, U$880, U$928, U$976, U$1024, U$1072, U$1120: #POCIX#7
U$34, U$37, U$68, U$71, U$116, U$119, U$164, U$167, U$212, U$215, U$260, U$263, U$308, U$311, U$356, U$359, U$404, U$407, U$452, U$455, U$500, U$503, U$548, U$551, U$596, U$599, U$644, U$647, U$692, U$695, U$740, U$743, U$788, U$791, U$836, U$839, U$884, U$887, U$932, U$935, U$980, U$983, U$1028, U$1031, U$1076, U$1079, U$1124, U$1127: X2114
U$35, U$38, U$69, U$72, U$117, U$120, U$165, U$168, U$213, U$216, U$261, U$264, U$309, U$312, U$357, U$360, U$405, U$408, U$453, U$456, U$501, U$504, U$549, U$552, U$597, U$600, U$645, U$648, U$693, U$696, U$741, U$744, U$789, U$792, U$837, U$840, U$885, U$888, U$933, U$936, U$981, U$984, U$1029, U$1032, U$1077, U$1080, U$1125, U$1128: Y2115
U$36, U$39, U$70, U$73, U$118, U$121, U$166, U$169, U$214, U$217, U$262, U$265, U$310, U$313, U$358, U$361, U$406, U$409, U$454, U$457, U$502, U$505, U$550, U$553, U$598, U$601, U$646, U$649, U$694, U$697, U$742, U$745, U$790, U$793, U$838, U$841, U$886, U$889, U$934, U$937, U$982, U$985, U$1030, U$1033, U$1078, U$1081, U$1126, U$1129: Z2116
U$40, U$74, U$122, U$170, U$218, U$266, U$314, U$362, U$410, U$458, U$506, U$554, U$602, U$650, U$698, U$746, U$794, U$842, U$890, U$938, U$986, U$1034, U$1082, U$1130: #INT2#3
U$41, U$88, U$136, U$184, U$232, U$280, U$328, U$376, U$424, U$472, U$520, U$568, U$616, U$664, U$712, U$760, U$808, U$856, U$904, U$952, U$1000, U$1048, U$1096, U$1144: #1#4
U$42, U$80, U$128, U$176, U$224, U$272, U$320, U$368, U$416, U$464, U$512, U$560, U$608, U$656, U$704, U$752, U$800, U$848, U$896, U$944, U$992, U$1040, U$1088, U$1136: #SDX#20
U$43, U$81, U$129, U$177, U$225, U$273, U$321, U$369, U$417, U$465, U$513, U$561, U$609, U$657, U$705, U$753, U$801, U$849, U$897, U$945, U$993, U$1041, U$1089, U$1137: #SCX#19
U$44, U$90, U$138, U$186, U$234, U$282, U$330, U$378, U$426, U$474, U$522, U$570, U$618, U$666, U$714, U$762, U$810, U$858, U$906, U$954, U$1002, U$1050, U$1098, U$1146: SFE_LOGO_FLAME_.2
U$45, U$49, U$91, U$92, U$139, U$140, U$187, U$188, U$235, U$236, U$283, U$284, U$331, U$332, U$379, U$380, U$427, U$428, U$475, U$476, U$523, U$524, U$571, U$572, U$619, U$620, U$667, U$668, U$715, U$716, U$763, U$764, U$811, U$812, U$859, U$860, U$907, U$908, U$955, U$956, U$1003, U$1004, U$1051, U$1052, U$1099, U$1100, U$1147, U$1148: #0#4
U$46, U$47, U$82, U$83, U$130, U$131, U$178, U$179, U$226, U$227, U$274, U$275, U$322, U$323, U$370, U$371, U$418, U$419, U$466, U$467, U$514, U$515, U$562, U$563, U$610, U$611, U$658, U$659, U$706, U$707, U$754, U$755, U$802, U$803, U$850, U$851, U$898, U$899, U$946, U$947, U$994, U$995, U$1042, U$1043, U$1090, U$1091, U$1138, U$1139: LSM6DSV16X37
U$48, U$95, U$143, U$191, U$239, U$287, U$335, U$383, U$431, U$479, U$527, U$575, U$623, U$671, U$719, U$767, U$815, U$863, U$911, U$959, U$1007, U$1055, U$1103, U$1151: #SCLK#4

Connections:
3.3V: C3.1, C4.1, I2C_PU.2, J1.2, J2.2, JP1.5, PAD1.1, PAD2.1, R3.2, R4.2, R5.2, U1.P5, U1.P8
3.3V1: C1.1, C2.1, I2C_PU1.2, J3.2, J4.2, JP2.5, PAD3.1, PAD4.1, R11.2, R12.2, R13.2, U2.P5, U2.P8
3.3V2: C9.1, C10.1, I2C_PU2.2, J5.2, J6.2, JP5.5, PAD5.1, PAD6.1, R19.2, R20.2, R21.2, U3.P5, U3.P8
3.3V3: C13.1, C14.1, I2C_PU3.2, J7.2, J8.2, JP7.5, PAD7.1, PAD8.1, R27.2, R28.2, R29.2, U4.P5, U4.P8
3.3V4: C17.1, C18.1, I2C_PU4.2, J9.2, J10.2, JP9.5, PAD9.1, PAD10.1, R35.2, R36.2, R37.2, U5.P5, U5.P8
3.3V5: C21.1, C22.1, I2C_PU5.2, J11.2, J12.2, JP11.5, PAD11.1, PAD12.1, R43.2, R44.2, R45.2, U6.P5, U6.P8
3.3V6: C25.1, C26.1, I2C_PU6.2, J13.2, J14.2, JP13.5, PAD13.1, PAD14.1, R51.2, R52.2, R53.2, U7.P5, U7.P8
3.3V7: C29.1, C30.1, I2C_PU7.2, J15.2, J16.2, JP15.5, PAD15.1, PAD16.1, R59.2, R60.2, R61.2, U8.P5, U8.P8
3.3V8: C33.1, C34.1, I2C_PU8.2, J17.2, J18.2, JP17.5, PAD17.1, PAD18.1, R67.2, R68.2, R69.2, U9.P5, U9.P8
3.3V9: C37.1, C38.1, I2C_PU9.2, J19.2, J20.2, JP19.5, PAD19.1, PAD20.1, R75.2, R76.2, R77.2, U10.P5, U10.P8
3.3V10: C41.1, C42.1, I2C_PU10.2, J21.2, J22.2, JP21.5, PAD21.1, PAD22.1, R83.2, R84.2, R85.2, U11.P5, U11.P8
3.3V11: C45.1, C46.1, I2C_PU11.2, J23.2, J24.2, JP23.5, PAD23.1, PAD24.1, R91.2, R92.2, R93.2, U12.P5, U12.P8
3.3V12: C49.1, C50.1, I2C_PU12.2, J25.2, J26.2, JP25.5, PAD25.1, PAD26.1, R99.2, R100.2, R101.2, U13.P5, U13.P8
3.3V13: C53.1, C54.1, I2C_PU13.2, J27.2, J28.2, JP27.5, PAD27.1, PAD28.1, R107.2, R108.2, R109.2, U14.P5, U14.P8
3.3V14: C57.1, C58.1, I2C_PU14.2, J29.2, J30.2, JP29.5, PAD29.1, PAD30.1, R115.2, R116.2, R117.2, U15.P5, U15.P8
3.3V15: C61.1, C62.1, I2C_PU15.2, J31.2, J32.2, JP31.5, PAD31.1, PAD32.1, R123.2, R124.2, R125.2, U16.P5, U16.P8
3.3V16: C65.1, C66.1, I2C_PU16.2, J33.2, J34.2, JP33.5, PAD33.1, PAD34.1, R131.2, R132.2, R133.2, U17.P5, U17.P8
3.3V17: C69.1, C70.1, I2C_PU17.2, J35.2, J36.2, JP35.5, PAD35.1, PAD36.1, R139.2, R140.2, R141.2, U18.P5, U18.P8
3.3V18: C73.1, C74.1, I2C_PU18.2, J37.2, J38.2, JP37.5, PAD37.1, PAD38.1, R147.2, R148.2, R149.2, U19.P5, U19.P8
3.3V19: C77.1, C78.1, I2C_PU19.2, J39.2, J40.2, JP39.5, PAD39.1, PAD40.1, R155.2, R156.2, R157.2, U20.P5, U20.P8
3.3V20: C81.1, C82.1, I2C_PU20.2, J41.2, J42.2, JP41.5, PAD41.1, PAD42.1, R163.2, R164.2, R165.2, U21.P5, U21.P8
3.3V21: C85.1, C86.1, I2C_PU21.2, J43.2, J44.2, JP43.5, PAD43.1, PAD44.1, R171.2, R172.2, R173.2, U22.P5, U22.P8
3.3V22: C89.1, C90.1, I2C_PU22.2, J45.2, J46.2, JP45.5, PAD45.1, PAD46.1, R179.2, R180.2, R181.2, U23.P5, U23.P8
3.3V23: C93.1, C94.1, I2C_PU23.2, J47.2, J48.2, JP47.5, PAD47.1, PAD48.1, R187.2, R188.2, R189.2, U24.P5, U24.P8
!CS!: JP1.1, R3.1, U1.P12
!CS!1: JP2.1, R11.1, U2.P12
!CS!2: JP5.1, R19.1, U3.P12
!CS!3: JP7.1, R27.1, U4.P12
!CS!4: JP9.1, R35.1, U5.P12
!CS!5: JP11.1, R43.1, U6.P12
!CS!6: JP13.1, R51.1, U7.P12
!CS!7: JP15.1, R59.1, U8.P12
!CS!8: JP17.1, R67.1, U9.P12
!CS!9: JP19.1, R75.1, U10.P12
!CS!10: JP21.1, R83.1, U11.P12
!CS!11: JP23.1, R91.1, U12.P12
!CS!12: JP25.1, R99.1, U13.P12
!CS!13: JP27.1, R107.1, U14.P12
!CS!14: JP29.1, R115.1, U15.P12
!CS!15: JP31.1, R123.1, U16.P12
!CS!16: JP33.1, R131.1, U17.P12
!CS!17: JP35.1, R139.1, U18.P12
!CS!18: JP37.1, R147.1, U19.P12
!CS!19: JP39.1, R155.1, U20.P12
!CS!20: JP41.1, R163.1, U21.P12
!CS!21: JP43.1, R171.1, U22.P12
!CS!22: JP45.1, R179.1, U23.P12
!CS!23: JP47.1, R187.1, U24.P12
GND: C3.2, C4.2, C5.2, C6.2, J1.1, J2.1, JP1.6, LED.1, PAD1.3, PAD2.3, R6.1, SCX.1, SDX.1, U1.P6, U1.P7
GND1: C1.2, C2.2, C7.2, C8.2, J3.1, J4.1, JP2.6, LED1.1, PAD3.3, PAD4.3, R14.1, SCX1.1, SDX1.1, U2.P6, U2.P7
GND2: C9.2, C10.2, C11.2, C12.2, J5.1, J6.1, JP5.6, LED2.1, PAD5.3, PAD6.3, R22.1, SCX2.1, SDX2.1, U3.P6, U3.P7
GND3: C13.2, C14.2, C15.2, C16.2, J7.1, J8.1, JP7.6, LED3.1, PAD7.3, PAD8.3, R30.1, SCX3.1, SDX3.1, U4.P6, U4.P7
GND4: C17.2, C18.2, C19.2, C20.2, J9.1, J10.1, JP9.6, LED4.1, PAD9.3, PAD10.3, R38.1, SCX4.1, SDX4.1, U5.P6, U5.P7
GND5: C21.2, C22.2, C23.2, C24.2, J11.1, J12.1, JP11.6, LED5.1, PAD11.3, PAD12.3, R46.1, SCX5.1, SDX5.1, U6.P6, U6.P7
GND6: C25.2, C26.2, C27.2, C28.2, J13.1, J14.1, JP13.6, LED6.1, PAD13.3, PAD14.3, R54.1, SCX6.1, SDX6.1, U7.P6, U7.P7
GND7: C29.2, C30.2, C31.2, C32.2, J15.1, J16.1, JP15.6, LED7.1, PAD15.3, PAD16.3, R62.1, SCX7.1, SDX7.1, U8.P6, U8.P7
GND8: C33.2, C34.2, C35.2, C36.2, J17.1, J18.1, JP17.6, LED8.1, PAD17.3, PAD18.3, R70.1, SCX8.1, SDX8.1, U9.P6, U9.P7
GND9: C37.2, C38.2, C39.2, C40.2, J19.1, J20.1, JP19.6, LED9.1, PAD19.3, PAD20.3, R78.1, SCX9.1, SDX9.1, U10.P6, U10.P7
GND10: C41.2, C42.2, C43.2, C44.2, J21.1, J22.1, JP21.6, LED10.1, PAD21.3, PAD22.3, R86.1, SCX10.1, SDX10.1, U11.P6, U11.P7
GND11: C45.2, C46.2, C47.2, C48.2, J23.1, J24.1, JP23.6, LED11.1, PAD23.3, PAD24.3, R94.1, SCX11.1, SDX11.1, U12.P6, U12.P7
GND12: C49.2, C50.2, C51.2, C52.2, J25.1, J26.1, JP25.6, LED12.1, PAD25.3, PAD26.3, R102.1, SCX12.1, SDX12.1, U13.P6, U13.P7
GND13: C53.2, C54.2, C55.2, C56.2, J27.1, J28.1, JP27.6, LED13.1, PAD27.3, PAD28.3, R110.1, SCX13.1, SDX13.1, U14.P6, U14.P7
GND14: C57.2, C58.2, C59.2, C60.2, J29.1, J30.1, JP29.6, LED14.1, PAD29.3, PAD30.3, R118.1, SCX14.1, SDX14.1, U15.P6, U15.P7
GND15: C61.2, C62.2, C63.2, C64.2, J31.1, J32.1, JP31.6, LED15.1, PAD31.3, PAD32.3, R126.1, SCX15.1, SDX15.1, U16.P6, U16.P7
GND16: C65.2, C66.2, C67.2, C68.2, J33.1, J34.1, JP33.6, LED16.1, PAD33.3, PAD34.3, R134.1, SCX16.1, SDX16.1, U17.P6, U17.P7
GND17: C69.2, C70.2, C71.2, C72.2, J35.1, J36.1, JP35.6, LED17.1, PAD35.3, PAD36.3, R142.1, SCX17.1, SDX17.1, U18.P6, U18.P7
GND18: C73.2, C74.2, C75.2, C76.2, J37.1, J38.1, JP37.6, LED18.1, PAD37.3, PAD38.3, R150.1, SCX18.1, SDX18.1, U19.P6, U19.P7
GND19: C77.2, C78.2, C79.2, C80.2, J39.1, J40.1, JP39.6, LED19.1, PAD39.3, PAD40.3, R158.1, SCX19.1, SDX19.1, U20.P6, U20.P7
GND20: C81.2, C82.2, C83.2, C84.2, J41.1, J42.1, JP41.6, LED20.1, PAD41.3, PAD42.3, R166.1, SCX20.1, SDX20.1, U21.P6, U21.P7
GND21: C85.2, C86.2, C87.2, C88.2, J43.1, J44.1, JP43.6, LED21.1, PAD43.3, PAD44.3, R174.1, SCX21.1, SDX21.1, U22.P6, U22.P7
GND22: C89.2, C90.2, C91.2, C92.2, J45.1, J46.1, JP45.6, LED22.1, PAD45.3, PAD46.3, R182.1, SCX22.1, SDX22.1, U23.P6, U23.P7
GND23: C93.2, C94.2, C95.2, C96.2, J47.1, J48.1, JP47.6, LED23.1, PAD47.3, PAD48.3, R190.1, SCX23.1, SDX23.1, U24.P6, U24.P7
INT1: JP3.2, U1.P4
INT2: JP3.1, U1.P9
INT3: JP4.2, U2.P4
INT4: JP4.1, U2.P9
INT5: JP6.2, U3.P4
INT6: JP6.1, U3.P9
INT7: JP8.2, U4.P4
INT8: JP8.1, U4.P9
INT9: JP10.2, U5.P4
INT10: JP10.1, U5.P9
INT11: JP12.2, U6.P4
INT12: JP12.1, U6.P9
INT13: JP14.2, U7.P4
INT14: JP14.1, U7.P9
INT15: JP16.2, U8.P4
INT16: JP16.1, U8.P9
INT17: JP18.2, U9.P4
INT18: JP18.1, U9.P9
INT19: JP20.2, U10.P4
INT20: JP20.1, U10.P9
INT21: JP22.2, U11.P4
INT22: JP22.1, U11.P9
INT23: JP24.2, U12.P4
INT24: JP24.1, U12.P9
INT25: JP26.2, U13.P4
INT26: JP26.1, U13.P9
INT27: JP28.2, U14.P4
INT28: JP28.1, U14.P9
INT29: JP30.2, U15.P4
INT30: JP30.1, U15.P9
INT31: JP32.2, U16.P4
INT32: JP32.1, U16.P9
INT33: JP34.2, U17.P4
INT34: JP34.1, U17.P9
INT35: JP36.2, U18.P4
INT36: JP36.1, U18.P9
INT37: JP38.2, U19.P4
INT38: JP38.1, U19.P9
INT39: JP40.2, U20.P4
INT40: JP40.1, U20.P9
INT41: JP42.2, U21.P4
INT42: JP42.1, U21.P9
INT43: JP44.2, U22.P4
INT44: JP44.1, U22.P9
INT45: JP46.2, U23.P4
INT46: JP46.1, U23.P9
INT47: JP48.2, U24.P4
INT48: JP48.1, U24.P9
unnamed: ADDR.3, R5.1
unnamed: D1.A, R4.1
unnamed: D1.C, LED.2
unnamed: P2.2, PAD2.2
unnamed: I2C_PU.1, R1.2
unnamed: I2C_PU.3, R2.2
unnamed: ADDR.1, R6.2
unnamed: P1.2, PAD1.2
unnamed: I2C_PU1.1, R9.2
unnamed: I2C_PU1.3, R10.2
unnamed: D2.A, R12.1
unnamed: D2.C, LED1.2
unnamed: ADDR1.3, R13.1
unnamed: ADDR1.1, R14.2
unnamed: P3.2, PAD3.2
unnamed: P4.2, PAD4.2
unnamed: I2C_PU2.1, R17.2
unnamed: I2C_PU2.3, R18.2
unnamed: D3.A, R20.1
unnamed: D3.C, LED2.2
unnamed: ADDR2.3, R21.1
unnamed: ADDR2.1, R22.2
unnamed: P5.2, PAD5.2
unnamed: P6.2, PAD6.2
unnamed: I2C_PU3.1, R25.2
unnamed: I2C_PU3.3, R26.2
unnamed: D4.A, R28.1
unnamed: D4.C, LED3.2
unnamed: ADDR3.3, R29.1
unnamed: ADDR3.1, R30.2
unnamed: P7.2, PAD7.2
unnamed: P8.2, PAD8.2
unnamed: I2C_PU4.1, R33.2
unnamed: I2C_PU4.3, R34.2
unnamed: D5.A, R36.1
unnamed: D5.C, LED4.2
unnamed: ADDR4.3, R37.1
unnamed: ADDR4.1, R38.2
unnamed: P9.2, PAD9.2
unnamed: P10.2, PAD10.2
unnamed: I2C_PU5.1, R41.2
unnamed: I2C_PU5.3, R42.2
unnamed: D6.A, R44.1
unnamed: D6.C, LED5.2
unnamed: ADDR5.3, R45.1
unnamed: ADDR5.1, R46.2
unnamed: P11.2, PAD11.2
unnamed: P12.2, PAD12.2
unnamed: I2C_PU6.1, R49.2
unnamed: I2C_PU6.3, R50.2
unnamed: D7.A, R52.1
unnamed: D7.C, LED6.2
unnamed: ADDR6.3, R53.1
unnamed: ADDR6.1, R54.2
unnamed: P13.2, PAD13.2
unnamed: P14.2, PAD14.2
unnamed: I2C_PU7.1, R57.2
unnamed: I2C_PU7.3, R58.2
unnamed: D8.A, R60.1
unnamed: D8.C, LED7.2
unnamed: ADDR7.3, R61.1
unnamed: ADDR7.1, R62.2
unnamed: P15.2, PAD15.2
unnamed: P16.2, PAD16.2
unnamed: I2C_PU8.1, R65.2
unnamed: I2C_PU8.3, R66.2
unnamed: D9.A, R68.1
unnamed: D9.C, LED8.2
unnamed: ADDR8.3, R69.1
unnamed: ADDR8.1, R70.2
unnamed: P17.2, PAD17.2
unnamed: P18.2, PAD18.2
unnamed: I2C_PU9.1, R73.2
unnamed: I2C_PU9.3, R74.2
unnamed: D10.A, R76.1
unnamed: D10.C, LED9.2
unnamed: ADDR9.3, R77.1
unnamed: ADDR9.1, R78.2
unnamed: P19.2, PAD19.2
unnamed: P20.2, PAD20.2
unnamed: I2C_PU10.1, R81.2
unnamed: I2C_PU10.3, R82.2
unnamed: D11.A, R84.1
unnamed: D11.C, LED10.2
unnamed: ADDR10.3, R85.1
unnamed: ADDR10.1, R86.2
unnamed: P21.2, PAD21.2
unnamed: P22.2, PAD22.2
unnamed: I2C_PU11.1, R89.2
unnamed: I2C_PU11.3, R90.2
unnamed: D12.A, R92.1
unnamed: D12.C, LED11.2
unnamed: ADDR11.3, R93.1
unnamed: ADDR11.1, R94.2
unnamed: P23.2, PAD23.2
unnamed: P24.2, PAD24.2
unnamed: I2C_PU12.1, R97.2
unnamed: I2C_PU12.3, R98.2
unnamed: D13.A, R100.1
unnamed: D13.C, LED12.2
unnamed: ADDR12.3, R101.1
unnamed: ADDR12.1, R102.2
unnamed: P25.2, PAD25.2
unnamed: P26.2, PAD26.2
unnamed: I2C_PU13.1, R105.2
unnamed: I2C_PU13.3, R106.2
unnamed: D14.A, R108.1
unnamed: D14.C, LED13.2
unnamed: ADDR13.3, R109.1
unnamed: ADDR13.1, R110.2
unnamed: P27.2, PAD27.2
unnamed: P28.2, PAD28.2
unnamed: I2C_PU14.1, R113.2
unnamed: I2C_PU14.3, R114.2
unnamed: D15.A, R116.1
unnamed: D15.C, LED14.2
unnamed: ADDR14.3, R117.1
unnamed: ADDR14.1, R118.2
unnamed: P29.2, PAD29.2
unnamed: P30.2, PAD30.2
unnamed: I2C_PU15.1, R121.2
unnamed: I2C_PU15.3, R122.2
unnamed: D16.A, R124.1
unnamed: D16.C, LED15.2
unnamed: ADDR15.3, R125.1
unnamed: ADDR15.1, R126.2
unnamed: P31.2, PAD31.2
unnamed: P32.2, PAD32.2
unnamed: I2C_PU16.1, R129.2
unnamed: I2C_PU16.3, R130.2
unnamed: D17.A, R132.1
unnamed: D17.C, LED16.2
unnamed: ADDR16.3, R133.1
unnamed: ADDR16.1, R134.2
unnamed: P33.2, PAD33.2
unnamed: P34.2, PAD34.2
unnamed: I2C_PU17.1, R137.2
unnamed: I2C_PU17.3, R138.2
unnamed: D18.A, R140.1
unnamed: D18.C, LED17.2
unnamed: ADDR17.3, R141.1
unnamed: ADDR17.1, R142.2
unnamed: P35.2, PAD35.2
unnamed: P36.2, PAD36.2
unnamed: I2C_PU18.1, R145.2
unnamed: I2C_PU18.3, R146.2
unnamed: D19.A, R148.1
unnamed: D19.C, LED18.2
unnamed: ADDR18.3, R149.1
unnamed: ADDR18.1, R150.2
unnamed: P37.2, PAD37.2
unnamed: P38.2, PAD38.2
unnamed: I2C_PU19.1, R153.2
unnamed: I2C_PU19.3, R154.2
unnamed: D20.A, R156.1
unnamed: D20.C, LED19.2
unnamed: ADDR19.3, R157.1
unnamed: ADDR19.1, R158.2
unnamed: P39.2, PAD39.2
unnamed: P40.2, PAD40.2
unnamed: I2C_PU20.1, R161.2
unnamed: I2C_PU20.3, R162.2
unnamed: D21.A, R164.1
unnamed: D21.C, LED20.2
unnamed: ADDR20.3, R165.1
unnamed: ADDR20.1, R166.2
unnamed: P41.2, PAD41.2
unnamed: P42.2, PAD42.2
unnamed: I2C_PU21.1, R169.2
unnamed: I2C_PU21.3, R170.2
unnamed: D22.A, R172.1
unnamed: D22.C, LED21.2
unnamed: ADDR21.3, R173.1
unnamed: ADDR21.1, R174.2
unnamed: P43.2, PAD43.2
unnamed: P44.2, PAD44.2
unnamed: I2C_PU22.1, R177.2
unnamed: I2C_PU22.3, R178.2
unnamed: D23.A, R180.1
unnamed: D23.C, LED22.2
unnamed: ADDR22.3, R181.1
unnamed: ADDR22.1, R182.2
unnamed: P45.2, PAD45.2
unnamed: P46.2, PAD46.2
unnamed: I2C_PU23.1, R185.2
unnamed: I2C_PU23.3, R186.2
unnamed: D24.A, R188.1
unnamed: D24.C, LED23.2
unnamed: ADDR23.3, R189.1
unnamed: ADDR23.1, R190.2
unnamed: P47.2, PAD47.2
unnamed: P48.2, PAD48.2
OCS: JP3.3, U1.P10
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

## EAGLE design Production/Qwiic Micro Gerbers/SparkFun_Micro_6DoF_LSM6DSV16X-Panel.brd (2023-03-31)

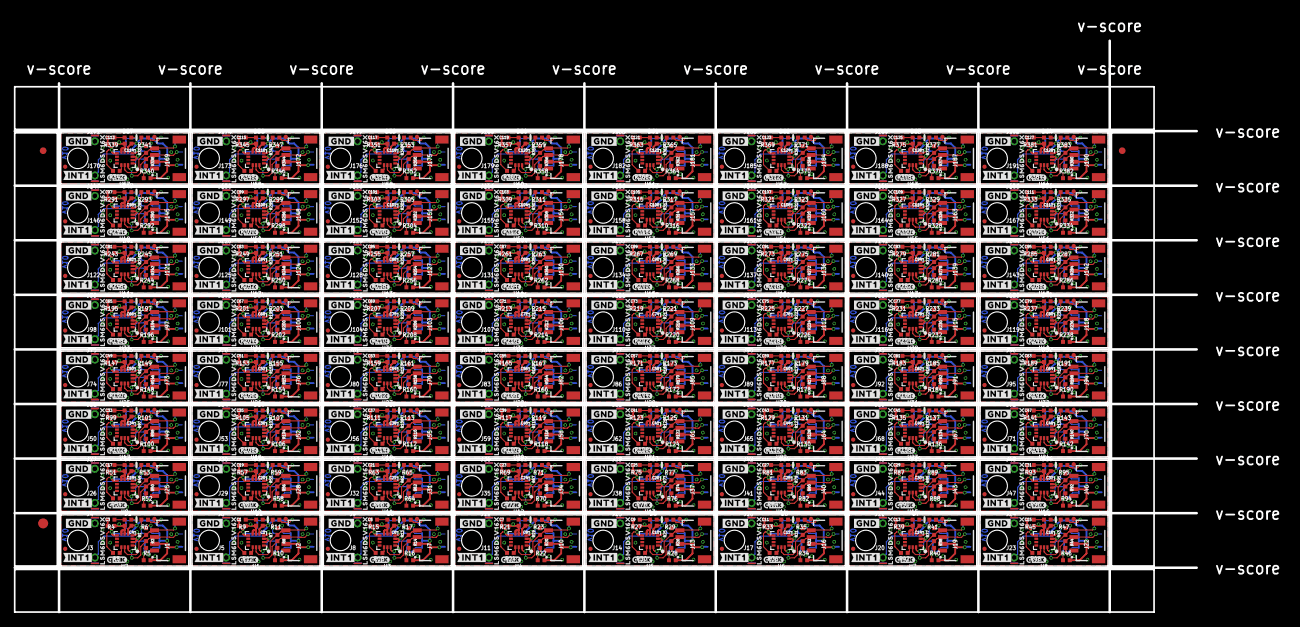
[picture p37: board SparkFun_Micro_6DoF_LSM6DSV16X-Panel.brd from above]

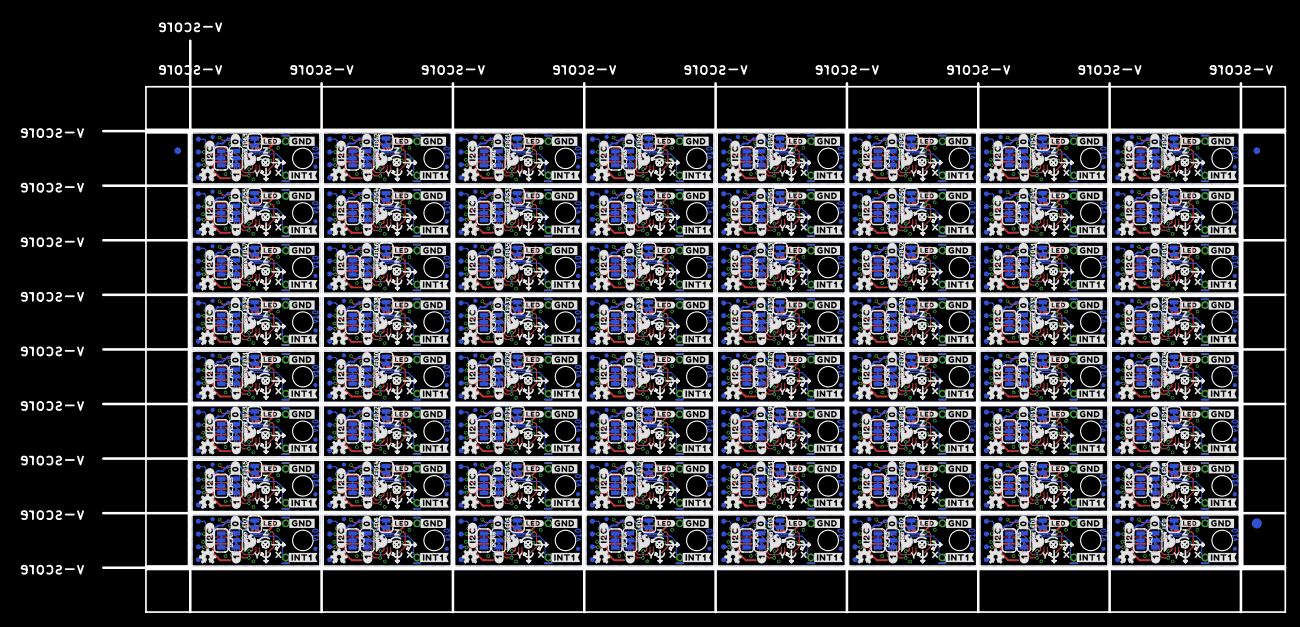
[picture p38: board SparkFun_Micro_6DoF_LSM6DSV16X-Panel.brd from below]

Board: 2 copper layers, 176.0 x 85.1 mm, 2630 parts (1283 on the bottom side), 832 nets.

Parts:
ADDR, ADDR1, ADDR2, ADDR3, ADDR4, ADDR5, ADDR6, ADDR7, ADDR8, ADDR9, ADDR10, ADDR11, ADDR12, ADDR13, ADDR14, ADDR15, ADDR16, ADDR17, ADDR18, ADDR19, ADDR20, ADDR21, ADDR22, ADDR23, ADDR24, ADDR25, ADDR26, ADDR27, ADDR28, ADDR29, ADDR30, ADDR31, ADDR32, ADDR33, ADDR34, ADDR35, ADDR36, ADDR37, ADDR38, ADDR39, ADDR40, ADDR41, ADDR42, ADDR43, ADDR44, ADDR45, ADDR46, ADDR47, ADDR48, ADDR49, ADDR50, ADDR51, ADDR52, ADDR53, ADDR54, ADDR55, ADDR56, ADDR57, ADDR58, ADDR59, ADDR60, ADDR61, ADDR62, ADDR63: JUMPER-SMT_3_1-NC_TRACE_SILK; SMT-JUMPER_3_1-NC_TRACE_SILK
C1, C2, C3, C4, C5, C6, C7, C8, C9, C10, C11, C12, C13, C14, C15, C16, C17, C18, C19, C20, C21, C22, C23, C24, C25, C26, C27, C28, C29, C30, C31, C32, C33, C34, C35, C36, C37, C38, C39, C40, C41, C42, C43, C44, C45, C46, C47, C48, C49, C50, C51, C52, C53, C54, C55, C56, C57, C58, C59, C60, C61, C62, C63, C64, C65, C66, C67, C68, C69, C70, C71, C72, C73, C74, C75, C76, C77, C78, C79, C80, C81, C82, C83, C84, C85, C86, C87, C88, C89, C90, C91, C92, C93, C94, C95, C96, C97, C98, C99, C100, C101, C102, C103, C104, C105, C106, C107, C108, C109, C110, C111, C112, C113, C114, C115, C116, C117, C118, C119, C120, C121, C122, C123, C124, C125, C126, C127, C128: 0.1uF; 0402-TIGHT
D1, D2, D3, D4, D5, D6, D7, D8, D9, D10, D11, D12, D13, D14, D15, D16, D17, D18, D19, D20, D21, D22, D23, D24, D25, D26, D27, D28, D29, D30, D31, D32, D33, D34, D35, D36, D37, D38, D39, D40, D41, D42, D43, D44, D45, D46, D47, D48, D49, D50, D51, D52, D53, D54, D55, D56, D57, D58, D59, D60, D61, D62, D63, D64: RED; LED-0402
E$1, E$2, E$3, E$4: FIDUCIAL-1X2
E$5, E$6: FIDUCIAL-1.5X3
FD1, FD2, FD3, FD4, FD5, FD6, FD7, FD8, FD9, FD10, FD11, FD12, FD13, FD14, FD15, FD16, FD17, FD18, FD19, FD20, FD21, FD22, FD23, FD24, FD25, FD26, FD27, FD28, FD29, FD30, FD31, FD32, FD33, FD34, FD35, FD36, FD37, FD38, FD39, FD40, FD41, FD42, FD43, FD44, FD45, FD46, FD47, FD48, FD49, FD50, FD51, FD52, FD53, FD54, FD55, FD56, FD57, FD58, FD59, FD60, FD61, FD62, FD63, FD64, FD65, FD66, FD67, FD68, FD69, FD70, FD71, FD72, FD73, FD74, FD75, FD76, FD77, FD78, FD79, FD80, FD81, FD82, FD83, FD84, FD85, FD86, FD87, FD88, FD89, FD90, FD91, FD92, FD93, FD94, FD95, FD96, FD97, FD98, FD99, FD100, FD101, FD102, FD103, FD104, FD105, FD106, FD107, FD108, FD109, FD110, FD111, FD112, FD113, FD114, FD115, FD116, FD117, FD118, FD119, FD120, FD121, FD122, FD123, FD124, FD125, FD126, FD127, FD128: FIDUCIALUFIDUCIAL; FIDUCIAL-MICRO
FID1, FID2, FID3, FID4, FID5, FID6, FID7, FID8, FID9, FID10, FID11, FID12, FID13, FID14, FID15, FID16, FID17, FID18, FID19, FID20, FID21, FID22, FID23, FID24, FID25, FID26, FID27, FID28, FID29, FID30, FID31, FID32, FID33, FID34, FID35, FID36, FID37, FID38, FID39, FID40, FID41, FID42, FID43, FID44, FID45, FID46, FID47, FID48, FID49, FID50, FID51, FID52, FID53, FID54, FID55, FID56, FID57, FID58, FID59, FID60, FID61, FID62, FID63, FID64, FID65, FID66, FID67, FID68, FID69, FID70, FID71, FID72, FID73, FID74, FID75, FID76, FID77, FID78, FID79, FID80, FID81, FID82, FID83, FID84, FID85, FID86, FID87, FID88, FID89, FID90, FID91, FID92, FID93, FID94, FID95, FID96, FID97, FID98, FID99, FID100, FID101, FID102, FID103, FID104, FID105, FID106, FID107, FID108, FID109, FID110, FID111, FID112, FID113, FID114, FID115, FID116, FID117, FID118, FID119, FID120, FID121, FID122, FID123, FID124, FID125, FID126, FID127, FID128: FIDUCIALUFIDUCIAL; FIDUCIAL-MICRO
I2C_PU, I2C_PU1, I2C_PU2, I2C_PU3, I2C_PU4, I2C_PU5, I2C_PU6, I2C_PU7, I2C_PU8, I2C_PU9, I2C_PU10, I2C_PU11, I2C_PU12, I2C_PU13, I2C_PU14, I2C_PU15, I2C_PU16, I2C_PU17, I2C_PU18, I2C_PU19, I2C_PU20, I2C_PU21, I2C_PU22, I2C_PU23, I2C_PU24, I2C_PU25, I2C_PU26, I2C_PU27, I2C_PU28, I2C_PU29, I2C_PU30, I2C_PU31, I2C_PU32, I2C_PU33, I2C_PU34, I2C_PU35, I2C_PU36, I2C_PU37, I2C_PU38, I2C_PU39, I2C_PU40, I2C_PU41, I2C_PU42, I2C_PU43, I2C_PU44, I2C_PU45, I2C_PU46, I2C_PU47, I2C_PU48, I2C_PU49, I2C_PU50, I2C_PU51, I2C_PU52, I2C_PU53, I2C_PU54, I2C_PU55, I2C_PU56, I2C_PU57, I2C_PU58, I2C_PU59, I2C_PU60, I2C_PU61, I2C_PU62, I2C_PU63: S_MODE; SMT-JUMPER_3_2-NC_TRACE_SILK
J1, J2, J7, J10, J13, J16, J19, J22, J25, J28, J31, J34, J37, J40, J43, J46, J49, J52, J55, J58, J61, J64, J67, J70, J73, J76, J79, J82, J85, J88, J91, J94, J97, J100, J103, J106, J109, J112, J115, J118, J121, J124, J127, J130, J133, J136, J139, J142, J145, J148, J151, J154, J157, J160, J163, J166, J169, J172, J175, J178, J181, J184, J187, J190: Qwiic Right Angle; JST04_1MM_RA
J3, J4, J5, J6, J8, J9, J11, J12, J14, J15, J17, J18, J20, J21, J23, J24, J26, J27, J29, J30, J32, J33, J35, J36, J38, J39, J41, J42, J44, J45, J47, J48, J50, J51, J53, J54, J56, J57, J59, J60, J62, J63, J65, J66, J68, J69, J71, J72, J74, J75, J77, J78, J80, J81, J83, J84, J86, J87, J89, J90, J92, J93, J95, J96, J98, J99, J101, J102, J104, J105, J107, J108, J110, J111, J113, J114, J116, J117, J119, J120, J122, J123, J125, J126, J128, J129, J131, J132, J134, J135, J137, J138, J140, J141, J143, J144, J146, J147, J149, J150, J152, J153, J155, J156, J158, J159, J161, J162, J164, J165, J167, J168, J170, J171, J173, J174, J176, J177, J179, J180, J182, J183, J185, J186, J188, J189, J191, J192: 1X01_1MM_NO_SILK
LED, LED1, LED2, LED3, LED4, LED5, LED6, LED7, LED8, LED9, LED10, LED11, LED12, LED13, LED14, LED15, LED16, LED17, LED18, LED19, LED20, LED21, LED22, LED23, LED24, LED25, LED26, LED27, LED28, LED29, LED30, LED31, LED32, LED33, LED34, LED35, LED36, LED37, LED38, LED39, LED40, LED41, LED42, LED43, LED44, LED45, LED46, LED47, LED48, LED49, LED50, LED51, LED52, LED53, LED54, LED55, LED56, LED57, LED58, LED59, LED60, LED61, LED62, LED63: JUMPER-SMT_2_NC_TRACE_SILK; SMT-JUMPER_2_NC_TRACE_SILK
LOGO1, LOGO5, LOGO8, LOGO11, LOGO14, LOGO17, LOGO20, LOGO23, LOGO26, LOGO29, LOGO32, LOGO35, LOGO38, LOGO41, LOGO44, LOGO47, LOGO50, LOGO53, LOGO56, LOGO59, LOGO62, LOGO65, LOGO68, LOGO71, LOGO74, LOGO77, LOGO80, LOGO83, LOGO86, LOGO89, LOGO92, LOGO95, LOGO98, LOGO101, LOGO104, LOGO107, LOGO110, LOGO113, LOGO116, LOGO119, LOGO122, LOGO125, LOGO128, LOGO131, LOGO134, LOGO137, LOGO140, LOGO143, LOGO146, LOGO149, LOGO152, LOGO155, LOGO158, LOGO161, LOGO164, LOGO167, LOGO170, LOGO173, LOGO176, LOGO179, LOGO182, LOGO185, LOGO188, LOGO191: QWIIC_LOGO_3MM; QWIIC_3MM
LOGO2, LOGO4, LOGO7, LOGO10, LOGO13, LOGO16, LOGO19, LOGO22, LOGO25, LOGO28, LOGO31, LOGO34, LOGO37, LOGO40, LOGO43, LOGO46, LOGO49, LOGO52, LOGO55, LOGO58, LOGO61, LOGO64, LOGO67, LOGO70, LOGO73, LOGO76, LOGO79, LOGO82, LOGO85, LOGO88, LOGO91, LOGO94, LOGO97, LOGO100, LOGO103, LOGO106, LOGO109, LOGO112, LOGO115, LOGO118, LOGO121, LOGO124, LOGO127, LOGO130, LOGO133, LOGO136, LOGO139, LOGO142, LOGO145, LOGO148, LOGO151, LOGO154, LOGO157, LOGO160, LOGO163, LOGO166, LOGO169, LOGO172, LOGO175, LOGO178, LOGO181, LOGO184, LOGO187, LOGO190: OSHW-LOGOMINI; OSHW-LOGO-MINI
LOGO3, LOGO6, LOGO9, LOGO12, LOGO15, LOGO18, LOGO21, LOGO24, LOGO27, LOGO30, LOGO33, LOGO36, LOGO39, LOGO42, LOGO45, LOGO48, LOGO51, LOGO54, LOGO57, LOGO60, LOGO63, LOGO66, LOGO69, LOGO72, LOGO75, LOGO78, LOGO81, LOGO84, LOGO87, LOGO90, LOGO93, LOGO96, LOGO99, LOGO102, LOGO105, LOGO108, LOGO111, LOGO114, LOGO117, LOGO120, LOGO123, LOGO126, LOGO129, LOGO132, LOGO135, LOGO138, LOGO141, LOGO144, LOGO147, LOGO150, LOGO153, LOGO156, LOGO159, LOGO162, LOGO165, LOGO168, LOGO171, LOGO174, LOGO177, LOGO180, LOGO183, LOGO186, LOGO189, LOGO192: SFE_LOGO_NAME_FLAMEBLANK; BLANK
R1, R2, R4, R7, R8, R9, R13, R14, R15, R19, R20, R21, R25, R26, R27, R31, R32, R33, R37, R38, R39, R43, R44, R45, R49, R50, R51, R55, R56, R57, R61, R62, R63, R67, R68, R69, R73, R74, R75, R79, R80, R81, R85, R86, R87, R91, R92, R93, R97, R98, R99, R103, R104, R105, R109, R110, R111, R115, R116, R117, R121, R122, R123, R127, R128, R129, R133, R134, R135, R139, R140, R141, R145, R146, R147, R151, R152, R153, R157, R158, R159, R163, R164, R165, R169, R170, R171, R175, R176, R177, R181, R182, R183, R187, R188, R189, R193, R194, R195, R199, R200, R201, R205, R206, R207, R211, R212, R213, R217, R218, R219, R223, R224, R225, R229, R230, R231, R235, R236, R237, R241, R242, R243, R247, R248, R249, R253, R254, R255, R259, R260, R261, R265, R266, R267, R271, R272, R273, R277, R278, R279, R283, R284, R285, R289, R290, R291, R295, R296, R297, R301, R302, R303, R307, R308, R309, R313, R314, R315, R319, R320, R321, R325, R326, R327, R331, R332, R333, R337, R338, R339, R343, R344, R345, R349, R350, R351, R355, R356, R357, R361, R362, R363, R367, R368, R369, R373, R374, R375, R379, R380, R381: 2.2k; 0402-TIGHT
R3, R5, R6, R10, R11, R12, R16, R17, R18, R22, R23, R24, R28, R29, R30, R34, R35, R36, R40, R41, R42, R46, R47, R48, R52, R53, R54, R58, R59, R60, R64, R65, R66, R70, R71, R72, R76, R77, R78, R82, R83, R84, R88, R89, R90, R94, R95, R96, R100, R101, R102, R106, R107, R108, R112, R113, R114, R118, R119, R120, R124, R125, R126, R130, R131, R132, R136, R137, R138, R142, R143, R144, R148, R149, R150, R154, R155, R156, R160, R161, R162, R166, R167, R168, R172, R173, R174, R178, R179, R180, R184, R185, R186, R190, R191, R192, R196, R197, R198, R202, R203, R204, R208, R209, R210, R214, R215, R216, R220, R221, R222, R226, R227, R228, R232, R233, R234, R238, R239, R240, R244, R245, R246, R250, R251, R252, R256, R257, R258, R262, R263, R264, R268, R269, R270, R274, R275, R276, R280, R281, R282, R286, R287, R288, R292, R293, R294, R298, R299, R300, R304, R305, R306, R310, R311, R312, R316, R317, R318, R322, R323, R324, R328, R329, R330, R334, R335, R336, R340, R341, R342, R346, R347, R348, R352, R353, R354, R358, R359, R360, R364, R365, R366, R370, R371, R372, R376, R377, R378, R382, R383, R384: 10k; 0402-TIGHT
STANDOFF1, STANDOFF2, STANDOFF3, STANDOFF4, STANDOFF5, STANDOFF6, STANDOFF7, STANDOFF8, STANDOFF9, STANDOFF10, STANDOFF11, STANDOFF12, STANDOFF13, STANDOFF14, STANDOFF15, STANDOFF16, STANDOFF17, STANDOFF18, STANDOFF19, STANDOFF20, STANDOFF21, STANDOFF22, STANDOFF23, STANDOFF24, STANDOFF25, STANDOFF26, STANDOFF27, STANDOFF28, STANDOFF29, STANDOFF30, STANDOFF31, STANDOFF32, STANDOFF33, STANDOFF34, STANDOFF35, STANDOFF36, STANDOFF37, STANDOFF38, STANDOFF39, STANDOFF40, STANDOFF41, STANDOFF42, STANDOFF43, STANDOFF44, STANDOFF45, STANDOFF46, STANDOFF47, STANDOFF48, STANDOFF49, STANDOFF50, STANDOFF51, STANDOFF52, STANDOFF53, STANDOFF54, STANDOFF55, STANDOFF56, STANDOFF57, STANDOFF58, STANDOFF59, STANDOFF60, STANDOFF61, STANDOFF62, STANDOFF63, STANDOFF64: STAND-OFFTIGHT; STAND-OFF-TIGHT
TP1, TP2, TP3, TP4, TP5, TP6, TP7, TP8, TP9, TP10, TP11, TP12, TP13, TP14, TP15, TP16, TP17, TP18, TP19, TP20, TP21, TP22, TP23, TP24, TP25, TP26, TP27, TP28, TP29, TP30, TP31, TP32, TP33, TP34, TP35, TP36, TP37, TP38, TP39, TP40, TP41, TP42, TP43, TP44, TP45, TP46, TP47, TP48, TP49, TP50, TP51, TP52, TP53, TP54, TP55, TP56, TP57, TP58, TP59, TP60, TP61, TP62, TP63, TP64, TP65, TP66, TP67, TP68, TP69, TP70, TP71, TP72, TP73, TP74, TP75, TP76, TP77, TP78, TP79, TP80, TP81, TP82, TP83, TP84, TP85, TP86, TP87, TP88, TP89, TP90, TP91, TP92, TP93, TP94, TP95, TP96, TP97, TP98, TP99, TP100, TP101, TP102, TP103, TP104, TP105, TP106, TP107, TP108, TP109, TP110, TP111, TP112, TP113, TP114, TP115, TP116, TP117, TP118, TP119, TP120, TP121, TP122, TP123, TP124, TP125, TP126, TP127, TP128, TP129, TP130, TP131, TP132, TP133, TP134, TP135, TP136, TP137, TP138, TP139, TP140, TP141, TP142, TP143, TP144, TP145, TP146, TP147, TP148, TP149, TP150, TP151, TP152, TP153, TP154, TP155, TP156, TP157, TP158, TP159, TP160, TP161, TP162, TP163, TP164, TP165, TP166, TP167, TP168, TP169, TP170, TP171, TP172, TP173, TP174, TP175, TP176, TP177, TP178, TP179, TP180, TP181, TP182, TP183, TP184, TP185, TP186, TP187, TP188, TP189, TP190, TP191, TP192, TP193, TP194, TP195, TP196, TP197, TP198, TP199, TP200, TP201, TP202, TP203, TP204, TP205, TP206, TP207, TP208, TP209, TP210, TP211, TP212, TP213, TP214, TP215, TP216, TP217, TP218, TP219, TP220, TP221, TP222, TP223, TP224, TP225, TP226, TP227, TP228, TP229, TP230, TP231, TP232, TP233, TP234, TP235, TP236, TP237, TP238, TP239, TP240, TP241, TP242, TP243, TP244, TP245, TP246, TP247, TP248, TP249, TP250, TP251, TP252, TP253, TP254, TP255, TP256: TEST-POINT3; PAD.03X.03
U1, U2, U3, U4, U5, U6, U7, U8, U9, U10, U11, U12, U13, U14, U15, U16, U17, U18, U19, U20, U21, U22, U23, U24, U25, U26, U27, U28, U29, U30, U31, U32, U33, U34, U35, U36, U37, U38, U39, U40, U41, U42, U43, U44, U45, U46, U47, U48, U49, U50, U51, U52, U53, U54, U55, U56, U57, U58, U59, U60, U61, U62, U63, U64: LSM6DSV16X; LGA-14L
U$1, U$18, U$32, U$45, U$58, U$71, U$84, U$97, U$110, U$123, U$136, U$149, U$162, U$175, U$188, U$201, U$214, U$227, U$240, U$253, U$266, U$279, U$292, U$305, U$318, U$331, U$344, U$357, U$370, U$383, U$396, U$409, U$422, U$435, U$448, U$461, U$474, U$487, U$500, U$513, U$526, U$539, U$552, U$565, U$578, U$591, U$604, U$617, U$630, U$643, U$656, U$669, U$682, U$695, U$708, U$721, U$734, U$747, U$760, U$773, U$786, U$799, U$812, U$825: #0#4
U$2, U$19, U$33, U$46, U$59, U$72, U$85, U$98, U$111, U$124, U$137, U$150, U$163, U$176, U$189, U$202, U$215, U$228, U$241, U$254, U$267, U$280, U$293, U$306, U$319, U$332, U$345, U$358, U$371, U$384, U$397, U$410, U$423, U$436, U$449, U$462, U$475, U$488, U$501, U$514, U$527, U$540, U$553, U$566, U$579, U$592, U$605, U$618, U$631, U$644, U$657, U$670, U$683, U$696, U$709, U$722, U$735, U$748, U$761, U$774, U$787, U$800, U$813, U$826: #1#4
U$3, U$17, U$31, U$44, U$57, U$70, U$83, U$96, U$109, U$122, U$135, U$148, U$161, U$174, U$187, U$200, U$213, U$226, U$239, U$252, U$265, U$278, U$291, U$304, U$317, U$330, U$343, U$356, U$369, U$382, U$395, U$408, U$421, U$434, U$447, U$460, U$473, U$486, U$499, U$512, U$525, U$538, U$551, U$564, U$577, U$590, U$603, U$616, U$629, U$642, U$655, U$668, U$681, U$694, U$707, U$720, U$733, U$746, U$759, U$772, U$785, U$798, U$811, U$824: #LED#2121
U$4, U$10, U$21, U$22, U$35, U$36, U$48, U$49, U$61, U$62, U$74, U$75, U$87, U$88, U$100, U$101, U$113, U$114, U$126, U$127, U$139, U$140, U$152, U$153, U$165, U$166, U$178, U$179, U$191, U$192, U$204, U$205, U$217, U$218, U$230, U$231, U$243, U$244, U$256, U$257, U$269, U$270, U$282, U$283, U$295, U$296, U$308, U$309, U$321, U$322, U$334, U$335, U$347, U$348, U$360, U$361, U$373, U$374, U$386, U$387, U$399, U$400, U$412, U$413, U$425, U$426, U$438, U$439, U$451, U$452, U$464, U$465, U$477, U$478, U$490, U$491, U$503, U$504, U$516, U$517, U$529, U$530, U$542, U$543, U$555, U$556, U$568, U$569, U$581, U$582, U$594, U$595, U$607, U$608, U$620, U$621, U$633, U$634, U$646, U$647, U$659, U$660, U$672, U$673, U$685, U$686, U$698, U$699, U$711, U$712, U$724, U$725, U$737, U$738, U$750, U$751, U$763, U$764, U$776, U$777, U$789, U$790, U$802, U$803, U$815, U$816, U$828, U$829: #GND#4
U$5, U$23, U$37, U$50, U$63, U$76, U$89, U$102, U$115, U$128, U$141, U$154, U$167, U$180, U$193, U$206, U$219, U$232, U$245, U$258, U$271, U$284, U$297, U$310, U$323, U$336, U$349, U$362, U$375, U$388, U$401, U$414, U$427, U$440, U$453, U$466, U$479, U$492, U$505, U$518, U$531, U$544, U$557, U$570, U$583, U$596, U$609, U$622, U$635, U$648, U$661, U$674, U$687, U$700, U$713, U$726, U$739, U$752, U$765, U$778, U$791, U$804, U$817, U$830: #INT1#0
U$6, U$25, U$39, U$52, U$65, U$78, U$91, U$104, U$117, U$130, U$143, U$156, U$169, U$182, U$195, U$208, U$221, U$234, U$247, U$260, U$273, U$286, U$299, U$312, U$325, U$338, U$351, U$364, U$377, U$390, U$403, U$416, U$429, U$442, U$455, U$468, U$481, U$494, U$507, U$520, U$533, U$546, U$559, U$572, U$585, U$598, U$611, U$624, U$637, U$650, U$663, U$676, U$689, U$702, U$715, U$728, U$741, U$754, U$767, U$780, U$793, U$806, U$819, U$832: LSM6DSV16X31
U$7, U$14, U$27, U$41, U$54, U$67, U$80, U$93, U$106, U$119, U$132, U$145, U$158, U$171, U$184, U$197, U$210, U$223, U$236, U$249, U$262, U$275, U$288, U$301, U$314, U$327, U$340, U$353, U$366, U$379, U$392, U$405, U$418, U$431, U$444, U$457, U$470, U$483, U$496, U$509, U$522, U$535, U$548, U$561, U$574, U$587, U$600, U$613, U$626, U$639, U$652, U$665, U$678, U$691, U$704, U$717, U$730, U$743, U$756, U$769, U$782, U$795, U$808, U$821: X2114
U$8, U$15, U$28, U$42, U$55, U$68, U$81, U$94, U$107, U$120, U$133, U$146, U$159, U$172, U$185, U$198, U$211, U$224, U$237, U$250, U$263, U$276, U$289, U$302, U$315, U$328, U$341, U$354, U$367, U$380, U$393, U$406, U$419, U$432, U$445, U$458, U$471, U$484, U$497, U$510, U$523, U$536, U$549, U$562, U$575, U$588, U$601, U$614, U$627, U$640, U$653, U$666, U$679, U$692, U$705, U$718, U$731, U$744, U$757, U$770, U$783, U$796, U$809, U$822: Y2115
U$9, U$16, U$30, U$43, U$56, U$69, U$82, U$95, U$108, U$121, U$134, U$147, U$160, U$173, U$186, U$199, U$212, U$225, U$238, U$251, U$264, U$277, U$290, U$303, U$316, U$329, U$342, U$355, U$368, U$381, U$394, U$407, U$420, U$433, U$446, U$459, U$472, U$485, U$498, U$511, U$524, U$537, U$550, U$563, U$576, U$589, U$602, U$615, U$628, U$641, U$654, U$667, U$680, U$693, U$706, U$719, U$732, U$745, U$758, U$771, U$784, U$797, U$810, U$823: Z2116
U$11, U$24, U$38, U$51, U$64, U$77, U$90, U$103, U$116, U$129, U$142, U$155, U$168, U$181, U$194, U$207, U$220, U$233, U$246, U$259, U$272, U$285, U$298, U$311, U$324, U$337, U$350, U$363, U$376, U$389, U$402, U$415, U$428, U$441, U$454, U$467, U$480, U$493, U$506, U$519, U$532, U$545, U$558, U$571, U$584, U$597, U$610, U$623, U$636, U$649, U$662, U$675, U$688, U$701, U$714, U$727, U$740, U$753, U$766, U$779, U$792, U$805, U$818, U$831: #INT1#2
U$12, U$20, U$34, U$47, U$60, U$73, U$86, U$99, U$112, U$125, U$138, U$151, U$164, U$177, U$190, U$203, U$216, U$229, U$242, U$255, U$268, U$281, U$294, U$307, U$320, U$333, U$346, U$359, U$372, U$385, U$398, U$411, U$424, U$437, U$450, U$463, U$476, U$489, U$502, U$515, U$528, U$541, U$554, U$567, U$580, U$593, U$606, U$619, U$632, U$645, U$658, U$671, U$684, U$697, U$710, U$723, U$736, U$749, U$762, U$775, U$788, U$801, U$814, U$827: #I2C#4
U$13, U$26, U$29, U$40, U$53, U$66, U$79, U$92, U$105, U$118, U$131, U$144, U$157, U$170, U$183, U$196, U$209, U$222, U$235, U$248, U$261, U$274, U$287, U$300, U$313, U$326, U$339, U$352, U$365, U$378, U$391, U$404, U$417, U$430, U$443, U$456, U$469, U$482, U$495, U$508, U$521, U$534, U$547, U$560, U$573, U$586, U$599, U$612, U$625, U$638, U$651, U$664, U$677, U$690, U$703, U$716, U$729, U$742, U$755, U$768, U$781, U$794, U$807, U$820: SFE_LOGO_FLAME_.1

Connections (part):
3.3V: C3.1, C4.1, I2C_PU.2, J1.2, R3.2, R4.2, R5.2, TP3.1, U2.P5, U2.P8
3.3V1: C1.1, C2.1, I2C_PU1.2, J2.2, R9.2, R10.2, R12.2, TP7.1, U1.P5, U1.P8
3.3V2: C5.1, C6.1, I2C_PU2.2, J7.2, R15.2, R16.2, R18.2, TP11.1, U3.P5, U3.P8
3.3V3: C7.1, C8.1, I2C_PU3.2, J10.2, R21.2, R22.2, R24.2, TP15.1, U4.P5, U4.P8
3.3V4: C9.1, C10.1, I2C_PU4.2, J13.2, R27.2, R28.2, R30.2, TP19.1, U5.P5, U5.P8
3.3V5: C11.1, C12.1, I2C_PU5.2, J16.2, R33.2, R34.2, R36.2, TP23.1, U6.P5, U6.P8
3.3V6: C13.1, C14.1, I2C_PU6.2, J19.2, R39.2, R40.2, R42.2, TP27.1, U7.P5, U7.P8
3.3V7: C15.1, C16.1, I2C_PU7.2, J22.2, R45.2, R46.2, R48.2, TP31.1, U8.P5, U8.P8
3.3V8: C17.1, C18.1, I2C_PU8.2, J25.2, R51.2, R52.2, R54.2, TP35.1, U9.P5, U9.P8
3.3V9: C19.1, C20.1, I2C_PU9.2, J28.2, R57.2, R58.2, R60.2, TP39.1, U10.P5, U10.P8
3.3V10: C21.1, C22.1, I2C_PU10.2, J31.2, R63.2, R64.2, R66.2, TP43.1, U11.P5, U11.P8
3.3V11: C23.1, C24.1, I2C_PU11.2, J34.2, R69.2, R70.2, R72.2, TP47.1, U12.P5, U12.P8
3.3V12: C25.1, C26.1, I2C_PU12.2, J37.2, R75.2, R76.2, R78.2, TP51.1, U13.P5, U13.P8
3.3V13: C27.1, C28.1, I2C_PU13.2, J40.2, R81.2, R82.2, R84.2, TP55.1, U14.P5, U14.P8
3.3V14: C29.1, C30.1, I2C_PU14.2, J43.2, R87.2, R88.2, R90.2, TP59.1, U15.P5, U15.P8
3.3V15: C31.1, C32.1, I2C_PU15.2, J46.2, R93.2, R94.2, R96.2, TP63.1, U16.P5, U16.P8
3.3V16: C33.1, C34.1, I2C_PU16.2, J49.2, R99.2, R100.2, R102.2, TP67.1, U17.P5, U17.P8
3.3V17: C35.1, C36.1, I2C_PU17.2, J52.2, R105.2, R106.2, R108.2, TP71.1, U18.P5, U18.P8
3.3V18: C37.1, C38.1, I2C_PU18.2, J55.2, R111.2, R112.2, R114.2, TP75.1, U19.P5, U19.P8
3.3V19: C39.1, C40.1, I2C_PU19.2, J58.2, R117.2, R118.2, R120.2, TP79.1, U20.P5, U20.P8
3.3V20: C41.1, C42.1, I2C_PU20.2, J61.2, R123.2, R124.2, R126.2, TP83.1, U21.P5, U21.P8
3.3V21: C43.1, C44.1, I2C_PU21.2, J64.2, R129.2, R130.2, R132.2, TP87.1, U22.P5, U22.P8
3.3V22: C45.1, C46.1, I2C_PU22.2, J67.2, R135.2, R136.2, R138.2, TP91.1, U23.P5, U23.P8
3.3V23: C47.1, C48.1, I2C_PU23.2, J70.2, R141.2, R142.2, R144.2, TP95.1, U24.P5, U24.P8
3.3V24: C49.1, C50.1, I2C_PU24.2, J73.2, R147.2, R148.2, R150.2, TP99.1, U25.P5, U25.P8
3.3V25: C51.1, C52.1, I2C_PU25.2, J76.2, R153.2, R154.2, R156.2, TP103.1, U26.P5, U26.P8
3.3V26: C53.1, C54.1, I2C_PU26.2, J79.2, R159.2, R160.2, R162.2, TP107.1, U27.P5, U27.P8
3.3V27: C55.1, C56.1, I2C_PU27.2, J82.2, R165.2, R166.2, R168.2, TP111.1, U28.P5, U28.P8
3.3V28: C57.1, C58.1, I2C_PU28.2, J85.2, R171.2, R172.2, R174.2, TP115.1, U29.P5, U29.P8
3.3V29: C59.1, C60.1, I2C_PU29.2, J88.2, R177.2, R178.2, R180.2, TP119.1, U30.P5, U30.P8
3.3V30: C61.1, C62.1, I2C_PU30.2, J91.2, R183.2, R184.2, R186.2, TP123.1, U31.P5, U31.P8
3.3V31: C63.1, C64.1, I2C_PU31.2, J94.2, R189.2, R190.2, R192.2, TP127.1, U32.P5, U32.P8
3.3V32: C65.1, C66.1, I2C_PU32.2, J97.2, R195.2, R196.2, R198.2, TP131.1, U33.P5, U33.P8
3.3V33: C67.1, C68.1, I2C_PU33.2, J100.2, R201.2, R202.2, R204.2, TP135.1, U34.P5, U34.P8
3.3V34: C69.1, C70.1, I2C_PU34.2, J103.2, R207.2, R208.2, R210.2, TP139.1, U35.P5, U35.P8
3.3V35: C71.1, C72.1, I2C_PU35.2, J106.2, R213.2, R214.2, R216.2, TP143.1, U36.P5, U36.P8
3.3V36: C73.1, C74.1, I2C_PU36.2, J109.2, R219.2, R220.2, R222.2, TP147.1, U37.P5, U37.P8
3.3V37: C75.1, C76.1, I2C_PU37.2, J112.2, R225.2, R226.2, R228.2, TP151.1, U38.P5, U38.P8
3.3V38: C77.1, C78.1, I2C_PU38.2, J115.2, R231.2, R232.2, R234.2, TP155.1, U39.P5, U39.P8
3.3V39: C79.1, C80.1, I2C_PU39.2, J118.2, R237.2, R238.2, R240.2, TP159.1, U40.P5, U40.P8
3.3V40: C81.1, C82.1, I2C_PU40.2, J121.2, R243.2, R244.2, R246.2, TP163.1, U41.P5, U41.P8
3.3V41: C83.1, C84.1, I2C_PU41.2, J124.2, R249.2, R250.2, R252.2, TP167.1, U42.P5, U42.P8
3.3V42: C85.1, C86.1, I2C_PU42.2, J127.2, R255.2, R256.2, R258.2, TP171.1, U43.P5, U43.P8
3.3V43: C87.1, C88.1, I2C_PU43.2, J130.2, R261.2, R262.2, R264.2, TP175.1, U44.P5, U44.P8
3.3V44: C89.1, C90.1, I2C_PU44.2, J133.2, R267.2, R268.2, R270.2, TP179.1, U45.P5, U45.P8
3.3V45: C91.1, C92.1, I2C_PU45.2, J136.2, R273.2, R274.2, R276.2, TP183.1, U46.P5, U46.P8
3.3V46: C93.1, C94.1, I2C_PU46.2, J139.2, R279.2, R280.2, R282.2, TP187.1, U47.P5, U47.P8
3.3V47: C95.1, C96.1, I2C_PU47.2, J142.2, R285.2, R286.2, R288.2, TP191.1, U48.P5, U48.P8
3.3V48: C97.1, C98.1, I2C_PU48.2, J145.2, R291.2, R292.2, R294.2, TP195.1, U49.P5, U49.P8
3.3V49: C99.1, C100.1, I2C_PU49.2, J148.2, R297.2, R298.2, R300.2, TP199.1, U50.P5, U50.P8
3.3V50: C101.1, C102.1, I2C_PU50.2, J151.2, R303.2, R304.2, R306.2, TP203.1, U51.P5, U51.P8
3.3V51: C103.1, C104.1, I2C_PU51.2, J154.2, R309.2, R310.2, R312.2, TP207.1, U52.P5, U52.P8
3.3V52: C105.1, C106.1, I2C_PU52.2, J157.2, R315.2, R316.2, R318.2, TP211.1, U53.P5, U53.P8
3.3V53: C107.1, C108.1, I2C_PU53.2, J160.2, R321.2, R322.2, R324.2, TP215.1, U54.P5, U54.P8
3.3V54: C109.1, C110.1, I2C_PU54.2, J163.2, R327.2, R328.2, R330.2, TP219.1, U55.P5, U55.P8
3.3V55: C111.1, C112.1, I2C_PU55.2, J166.2, R333.2, R334.2, R336.2, TP223.1, U56.P5, U56.P8
3.3V56: C113.1, C114.1, I2C_PU56.2, J169.2, R339.2, R340.2, R342.2, TP227.1, U57.P5, U57.P8
3.3V57: C115.1, C116.1, I2C_PU57.2, J172.2, R345.2, R346.2, R348.2, TP231.1, U58.P5, U58.P8
3.3V58: C117.1, C118.1, I2C_PU58.2, J175.2, R351.2, R352.2, R354.2, TP235.1, U59.P5, U59.P8
3.3V59: C119.1, C120.1, I2C_PU59.2, J178.2, R357.2, R358.2, R360.2, TP239.1, U60.P5, U60.P8
3.3V60: C121.1, C122.1, I2C_PU60.2, J181.2, R363.2, R364.2, R366.2, TP243.1, U61.P5, U61.P8
3.3V61: C123.1, C124.1, I2C_PU61.2, J184.2, R369.2, R370.2, R372.2, TP247.1, U62.P5, U62.P8
3.3V62: C125.1, C126.1, I2C_PU62.2, J187.2, R375.2, R376.2, R378.2, TP251.1, U63.P5, U63.P8
3.3V63: C127.1, C128.1, I2C_PU63.2, J190.2, R381.2, R382.2, R384.2, TP255.1, U64.P5, U64.P8
GND: C3.2, C4.2, J1.1, J4.1, LED.1, R6.1, TP4.1, U2.P2, U2.P3, U2.P6, U2.P7
GND1: C1.2, C2.2, J2.1, J6.1, LED1.1, R11.1, TP8.1, U1.P2, U1.P3, U1.P6, U1.P7
GND2: C5.2, C6.2, J7.1, J9.1, LED2.1, R17.1, TP12.1, U3.P2, U3.P3, U3.P6, U3.P7
GND3: C7.2, C8.2, J10.1, J12.1, LED3.1, R23.1, TP16.1, U4.P2, U4.P3, U4.P6, U4.P7
GND4: C9.2, C10.2, J13.1, J15.1, LED4.1, R29.1, TP20.1, U5.P2, U5.P3, U5.P6, U5.P7
GND5: C11.2, C12.2, J16.1, J18.1, LED5.1, R35.1, TP24.1, U6.P2, U6.P3, U6.P6, U6.P7
GND6: C13.2, C14.2, J19.1, J21.1, LED6.1, R41.1, TP28.1, U7.P2, U7.P3, U7.P6, U7.P7
GND7: C15.2, C16.2, J22.1, J24.1, LED7.1, R47.1, TP32.1, U8.P2, U8.P3, U8.P6, U8.P7
GND8: C17.2, C18.2, J25.1, J27.1, LED8.1, R53.1, TP36.1, U9.P2, U9.P3, U9.P6, U9.P7
GND9: C19.2, C20.2, J28.1, J30.1, LED9.1, R59.1, TP40.1, U10.P2, U10.P3, U10.P6, U10.P7
GND10: C21.2, C22.2, J31.1, J33.1, LED10.1, R65.1, TP44.1, U11.P2, U11.P3, U11.P6, U11.P7
GND11: C23.2, C24.2, J34.1, J36.1, LED11.1, R71.1, TP48.1, U12.P2, U12.P3, U12.P6, U12.P7
GND12: C25.2, C26.2, J37.1, J39.1, LED12.1, R77.1, TP52.1, U13.P2, U13.P3, U13.P6, U13.P7
GND13: C27.2, C28.2, J40.1, J42.1, LED13.1, R83.1, TP56.1, U14.P2, U14.P3, U14.P6, U14.P7
GND14: C29.2, C30.2, J43.1, J45.1, LED14.1, R89.1, TP60.1, U15.P2, U15.P3, U15.P6, U15.P7
GND15: C31.2, C32.2, J46.1, J48.1, LED15.1, R95.1, TP64.1, U16.P2, U16.P3, U16.P6, U16.P7
GND16: C33.2, C34.2, J49.1, J51.1, LED16.1, R101.1, TP68.1, U17.P2, U17.P3, U17.P6, U17.P7
GND17: C35.2, C36.2, J52.1, J54.1, LED17.1, R107.1, TP72.1, U18.P2, U18.P3, U18.P6, U18.P7
GND18: C37.2, C38.2, J55.1, J57.1, LED18.1, R113.1, TP76.1, U19.P2, U19.P3, U19.P6, U19.P7
GND19: C39.2, C40.2, J58.1, J60.1, LED19.1, R119.1, TP80.1, U20.P2, U20.P3, U20.P6, U20.P7
GND20: C41.2, C42.2, J61.1, J63.1, LED20.1, R125.1, TP84.1, U21.P2, U21.P3, U21.P6, U21.P7
GND21: C43.2, C44.2, J64.1, J66.1, LED21.1, R131.1, TP88.1, U22.P2, U22.P3, U22.P6, U22.P7
GND22: C45.2, C46.2, J67.1, J69.1, LED22.1, R137.1, TP92.1, U23.P2, U23.P3, U23.P6, U23.P7
GND23: C47.2, C48.2, J70.1, J72.1, LED23.1, R143.1, TP96.1, U24.P2, U24.P3, U24.P6, U24.P7
GND24: C49.2, C50.2, J73.1, J75.1, LED24.1, R149.1, TP100.1, U25.P2, U25.P3, U25.P6, U25.P7
GND25: C51.2, C52.2, J76.1, J78.1, LED25.1, R155.1, TP104.1, U26.P2, U26.P3, U26.P6, U26.P7
GND26: C53.2, C54.2, J79.1, J81.1, LED26.1, R161.1, TP108.1, U27.P2, U27.P3, U27.P6, U27.P7
GND27: C55.2, C56.2, J82.1, J84.1, LED27.1, R167.1, TP112.1, U28.P2, U28.P3, U28.P6, U28.P7
GND28: C57.2, C58.2, J85.1, J87.1, LED28.1, R173.1, TP116.1, U29.P2, U29.P3, U29.P6, U29.P7
GND29: C59.2, C60.2, J88.1, J90.1, LED29.1, R179.1, TP120.1, U30.P2, U30.P3, U30.P6, U30.P7
GND30: C61.2, C62.2, J91.1, J93.1, LED30.1, R185.1, TP124.1, U31.P2, U31.P3, U31.P6, U31.P7
GND31: C63.2, C64.2, J94.1, J96.1, LED31.1, R191.1, TP128.1, U32.P2, U32.P3, U32.P6, U32.P7
GND32: C65.2, C66.2, J97.1, J99.1, LED32.1, R197.1, TP132.1, U33.P2, U33.P3, U33.P6, U33.P7
GND33: C67.2, C68.2, J100.1, J102.1, LED33.1, R203.1, TP136.1, U34.P2, U34.P3, U34.P6, U34.P7
GND34: C69.2, C70.2, J103.1, J105.1, LED34.1, R209.1, TP140.1, U35.P2, U35.P3, U35.P6, U35.P7
GND35: C71.2, C72.2, J106.1, J108.1, LED35.1, R215.1, TP144.1, U36.P2, U36.P3, U36.P6, U36.P7
GND36: C73.2, C74.2, J109.1, J111.1, LED36.1, R221.1, TP148.1, U37.P2, U37.P3, U37.P6, U37.P7
GND37: C75.2, C76.2, J112.1, J114.1, LED37.1, R227.1, TP152.1, U38.P2, U38.P3, U38.P6, U38.P7
GND38: C77.2, C78.2, J115.1, J117.1, LED38.1, R233.1, TP156.1, U39.P2, U39.P3, U39.P6, U39.P7
GND39: C79.2, C80.2, J118.1, J120.1, LED39.1, R239.1, TP160.1, U40.P2, U40.P3, U40.P6, U40.P7
GND40: C81.2, C82.2, J121.1, J123.1, LED40.1, R245.1, TP164.1, U41.P2, U41.P3, U41.P6, U41.P7
GND41: C83.2, C84.2, J124.1, J126.1, LED41.1, R251.1, TP168.1, U42.P2, U42.P3, U42.P6, U42.P7
GND42: C85.2, C86.2, J127.1, J129.1, LED42.1, R257.1, TP172.1, U43.P2, U43.P3, U43.P6, U43.P7
GND43: C87.2, C88.2, J130.1, J132.1, LED43.1, R263.1, TP176.1, U44.P2, U44.P3, U44.P6, U44.P7
GND44: C89.2, C90.2, J133.1, J135.1, LED44.1, R269.1, TP180.1, U45.P2, U45.P3, U45.P6, U45.P7
GND45: C91.2, C92.2, J136.1, J138.1, LED45.1, R275.1, TP184.1, U46.P2, U46.P3, U46.P6, U46.P7
GND46: C93.2, C94.2, J139.1, J141.1, LED46.1, R281.1, TP188.1, U47.P2, U47.P3, U47.P6, U47.P7
GND47: C95.2, C96.2, J142.1, J144.1, LED47.1, R287.1, TP192.1, U48.P2, U48.P3, U48.P6, U48.P7
GND48: C97.2, C98.2, J145.1, J147.1, LED48.1, R293.1, TP196.1, U49.P2, U49.P3, U49.P6, U49.P7
GND49: C99.2, C100.2, J148.1, J150.1, LED49.1, R299.1, TP200.1, U50.P2, U50.P3, U50.P6, U50.P7
GND50: C101.2, C102.2, J151.1, J153.1, LED50.1, R305.1, TP204.1, U51.P2, U51.P3, U51.P6, U51.P7
GND51: C103.2, C104.2, J154.1, J156.1, LED51.1, R311.1, TP208.1, U52.P2, U52.P3, U52.P6, U52.P7
GND52: C105.2, C106.2, J157.1, J159.1, LED52.1, R317.1, TP212.1, U53.P2, U53.P3, U53.P6, U53.P7
GND53: C107.2, C108.2, J160.1, J162.1, LED53.1, R323.1, TP216.1, U54.P2, U54.P3, U54.P6, U54.P7
GND54: C109.2, C110.2, J163.1, J165.1, LED54.1, R329.1, TP220.1, U55.P2, U55.P3, U55.P6, U55.P7
GND55: C111.2, C112.2, J166.1, J168.1, LED55.1, R335.1, TP224.1, U56.P2, U56.P3, U56.P6, U56.P7
GND56: C113.2, C114.2, J169.1, J171.1, LED56.1, R341.1, TP228.1, U57.P2, U57.P3, U57.P6, U57.P7
GND57: C115.2, C116.2, J172.1, J174.1, LED57.1, R347.1, TP232.1, U58.P2, U58.P3, U58.P6, U58.P7
GND58: C117.2, C118.2, J175.1, J177.1, LED58.1, R353.1, TP236.1, U59.P2, U59.P3, U59.P6, U59.P7
GND59: C119.2, C120.2, J178.1, J180.1, LED59.1, R359.1, TP240.1, U60.P2, U60.P3, U60.P6, U60.P7
GND60: C121.2, C122.2, J181.1, J183.1, LED60.1, R365.1, TP244.1, U61.P2, U61.P3, U61.P6, U61.P7
GND61: C123.2, C124.2, J184.1, J186.1, LED61.1, R371.1, TP248.1, U62.P2, U62.P3, U62.P6, U62.P7
GND62: C125.2, C126.2, J187.1, J189.1, LED62.1, R377.1, TP252.1, U63.P2, U63.P3, U63.P6, U63.P7
GND63: C127.2, C128.2, J190.1, J192.1, LED63.1, R383.1, TP256.1, U64.P2, U64.P3, U64.P6, U64.P7
INT1: J3.1, U2.P4
INT2: J5.1, U1.P4
INT3: J8.1, U3.P4
INT4: J11.1, U4.P4
INT5: J14.1, U5.P4
INT6: J17.1, U6.P4
INT7: J20.1, U7.P4
INT8: J23.1, U8.P4
INT9: J26.1, U9.P4
INT10: J29.1, U10.P4
INT11: J32.1, U11.P4
INT12: J35.1, U12.P4
INT13: J38.1, U13.P4
INT14: J41.1, U14.P4
INT15: J44.1, U15.P4
INT16: J47.1, U16.P4
INT17: J50.1, U17.P4
INT18: J53.1, U18.P4
INT19: J56.1, U19.P4
INT20: J59.1, U20.P4
INT21: J62.1, U21.P4
INT22: J65.1, U22.P4
INT23: J68.1, U23.P4
INT24: J71.1, U24.P4
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

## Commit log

2022-12-07 Adds Qwiic Micro moves Qwiic hardware files to their own folders
    [SparkFun_6DoF_LSM6DSV16X.brd, SparkFun_6DoF_LSM6DSV16X.sch, SparkFun_Micro_6DoF_LSM6DSV16X.brd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]
2022-12-07 Approves air wires, shuffles schematic
    [SparkFun_6DoF_LSM6DSV16X.brd, SparkFun_6DoF_LSM6DSV16X.sch]
2022-12-07 Moves schematic parts around
    [SparkFun_6DoF_LSM6DSV16X.sch]
2022-12-08 Adds additional design that includes a low pass filter for "Qvar" sensing
    [SparkFun_6DoF_LSM6DSV16X.brd, SparkFun_6DoF_LSM6DSV16X.sch]
2022-12-08 Some small adjustments to parts
    [SparkFun_6DoF_LSM6DSV16X.brd]
2022-12-08 Changes version to v01, fixes air wires
    [SparkFun_6DoF_LSM6DSV16X.brd, SparkFun_6DoF_LSM6DSV16X.sch]
2022-12-09 Adds silk of the part name
    [SparkFun_Micro_6DoF_LSM6DSV16X.brd]
2022-12-09 Changes silk label on bottom to "SDX instead of "PICOX"
    [SparkFun_6DoF_LSM6DSV16X.brd, SparkFun_6DoF_LSM6DSV16X.sch]
2022-12-09 Capacitors in the schematic were crooked.
    [SparkFun_6DoF_LSM6DSV16X.sch]
2022-12-12 Removes design with filter
    [SparkFun_6DoF_LSM6DSV16X.brd, SparkFun_6DoF_LSM6DSV16X.sch]
2022-12-12 Changes design to design with filter
    [SparkFun_6DoF_LSM6DSV16X.brd, SparkFun_6DoF_LSM6DSV16X.sch]
2022-12-12 Adds labels, fixes various DRC issues
    [SparkFun_6DoF_LSM6DSV16X.brd, SparkFun_6DoF_LSM6DSV16X.sch]
2022-12-12 Updates measures, fixes various DRC issues in micro
    [SparkFun_6DoF_LSM6DSV16X.brd, SparkFun_Micro_6DoF_LSM6DSV16X.brd]
2022-12-13 Updates part with silk outline
    [SparkFun_6DoF_LSM6DSV16X.brd, SparkFun_6DoF_LSM6DSV16X.sch, SparkFun_Micro_6DoF_LSM6DSV16X.brd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]
2022-12-14 Adds note about "Qvar sensing"
    [SparkFun_6DoF_LSM6DSV16X.brd, SparkFun_6DoF_LSM6DSV16X.sch]
2022-12-14 Fixes airwire
    [SparkFun_6DoF_LSM6DSV16X.brd]
2022-12-14 Adds proto gerbers
    [SparkFun_6DoF_LSM6DSV16X.GBL, SparkFun_6DoF_LSM6DSV16X.GBO, SparkFun_6DoF_LSM6DSV16X.GBP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]
2023-03-29 Adds jumpers for one of the DNP pads to select whether it's tied to 3v3 or GND
    * Rolls to v10
    [SparkFun_6DoF_LSM6DSV16X.brd, SparkFun_6DoF_LSM6DSV16X.sch]
2023-03-30 Adds slightly better silk to new three way jumper
    [SparkFun_6DoF_LSM6DSV16X.brd, SparkFun_6DoF_LSM6DSV16X.sch]
2023-03-30 Rolls version to v10 on Micro, increases the size of the pin one indicator for the LED
    [SparkFun_Micro_6DoF_LSM6DSV16X.brd, SparkFun_Micro_6DoF_LSM6DSV16X.sch]
2023-03-30 Grounds SCx and SDx on micro since they are not used
    [SparkFun_Micro_6DoF_LSM6DSV16X.brd, SparkFun_Micro_6DoF_LSM6DSV16X.sch]
2023-03-30 Approves to DRC errors
    [SparkFun_Micro_6DoF_LSM6DSV16X.brd]
2023-03-31 Increases pad size, decreases paste size on footprint
    * Also adds trestrict between ground pads to the footprint itself
    * Fixes gyro silk on bottom
    * Swaps PICO and CS on 1x1 header
    * Improves ground pour
    * Adds more notes to the filter section
    [SparkFun_6DoF_LSM6DSV16X.brd, SparkFun_6DoF_LSM6DSV16X.sch, SparkFun_Micro_6DoF_LSM6DSV16X.brd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]
2023-03-31 Fixes angle of a single trace
    [SparkFun_Micro_6DoF_LSM6DSV16X.brd]
2023-03-31 Adds gerbers
    [SparkFun_6DoF_LSM6DSV16X-Panel.GBL, SparkFun_6DoF_LSM6DSV16X-Panel.GBP, SparkFun_6DoF_LSM6DSV16X-Panel.GBS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]
2023-05-05 Updating pin functionality descriptions on HardWare Overview

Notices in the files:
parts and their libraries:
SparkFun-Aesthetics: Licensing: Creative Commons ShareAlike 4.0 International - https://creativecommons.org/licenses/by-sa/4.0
